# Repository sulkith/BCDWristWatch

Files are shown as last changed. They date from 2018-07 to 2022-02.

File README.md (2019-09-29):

# (BCD)WristWatch
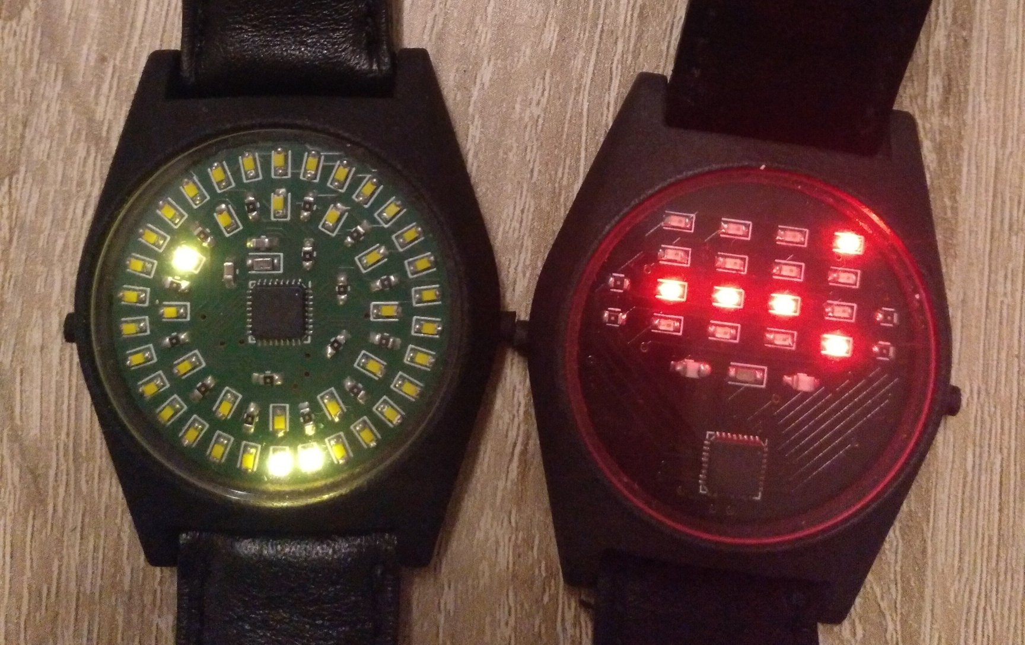
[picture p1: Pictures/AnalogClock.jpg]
picture of Both clocks side by side

Read the complete Story here in the Browser:<br>
https://htmlpreview.github.io/?https://github.com/sulkith/BCDWristWatch/blob/master/Story/Story.html <br>
Or you can download the PDF:<br>
https://github.com/sulkith/BCDWristWatch/blob/master/Story/Story.pdf

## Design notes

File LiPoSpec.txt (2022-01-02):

Typ: Lithium Polymer (LiPo) 3,7V / 1S
Länge der Kabel: ca. 10 cm
Nennspannung: 3,7V
Ladeschlussspannung: 4,2V
Entladeschlussspannung: 3,0V
Max. Ladestrom: (1C)
Max. Entladestrom: 2C für 10s
Max. Dauerentladestrom: (0,5C)

Lebensdauer:
300 Zyklen bei 0,5C Entladestrom
500 Zyklen bei 0,2C Entladestrom
max. erreichbare Zyklenzahl: 500 - 1.000 

https://fpvracing.ch/de/content/21-lipo-batterien

Entladerate (30C, 35C u.s.w.)

Die C Grösse der Batterie gibt an, wie viel Strom auf einmal von der Batterie gezogen werden kann/darf. 1C steht dabei für Ampere durch Amperestunde (Strom durch Ladung). Eine Batterie mit 2200mAh und 30C liefert demnach 30(A/Ah) x 2.2(Ah) = 66A. Der gesamte Multicopter darf in diesem Falle nicht mehr als 66A auf einmal ziehen. Gewisse LiPo-Packungen geben zusätzlich noch eine Burstrate an, welche grösser ist als die Kontinuierliche C-Rate, z.B. Discharge rate = 30C Continuous / 60C Burst. Burst ist die Angabe des erlaubten Spitzenstroms, welcher für ein paar Sekunden gezogen werden darf.

Es ist sehr wichtig dass man keine Batterie mit zu tiefem C-Rating für seinen Copter nimmt. Dadurch schädigt man die LiPo Batterie und wohlmöglich zusätzlich die ESCs.

1C 150mAh
1(A/Ah)*0,150(Ah)=150mA

PROG(Pin 2):Constant Charge Current Setting and Charge Current Monitor Pincharge current is set by connecting a resistor RISET from this pin to GND. When in precharge mode, the ISET pin’s voltage is regulated to 0.2V. When in constant charge current mode, the ISET pin’s voltage is regulated to 2V.In all modes during charging, the voltage on ISET pin can be used to measure the charge current as follows:

I_Bat = V_prog/R_prog * 1200 (Vprog=1V)

0,5A = (1V/2400)*1200

0,15A = (1/x)*1200
0,15A/1200 = 1/x
1200/0,15=x=8000 >= 8k

Rprog=10k
I_Bat = 1/10000*1200 = 120mA

Charger Circuit:
LTC4054
https://www.mouser.de/ProductDetail/Analog-Devices/LTC4054LES5-42TRPBF?qs=hVkxg5c3xu8%252BnYSikPxbpQ%3D%3D

Buck Converter:
TPS62205DBVR
https://www.mouser.de/ProductDetail/Texas-Instruments/TPS62205DBVR?qs=Gse6rAGbi7%252BLOibC81hqAA%3D%3D
TPS62203DBVR
https://www.mouser.de/ProductDetail/Texas-Instruments/TPS62203DBVR?qs=Gse6rAGbi7%252BekjMIU1w5MA%3D%3D
Induction
LQM18DH100M70L
https://www.mouser.de/ProductDetail/81-LQM18DH100M70L

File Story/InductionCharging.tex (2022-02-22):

\section{Making the watch rechargable}
The battery of the STM Watch version will last for about 6 months, so every 5 months i have to open the housing, change the battery and close the housing again. Also from an enviromental point of view it is not good to waste a battery every 6 months. So there has to be a solution to make the watch rechargable.
\subsection{possible solutions}
\subsubsection{Just use a rechargable battery}
The easiest variant to make the watch rechargable would be to directly use a rechargable battery wiht the same PCB. This would require no changes on the PCB level, but the rechargable batteries have a smaller capacitance than the not rechargable lithium batteries which are used till now.
So from the environmental point of view this is even worse, since the housing will wear out and i have to change the housing also very frequently. With this solution it also won't be possible to make the housing 100\% waterproof(glue it shut).
\subsubsection{charging pins on the outside of the watch}
Another possible solution would be to insert some contacts in the housing to be able to contact the battery from the outside. This would either require a battery management controller inside of the watch or in a charging bay. Since the charging bay for the watch would be also a special construction i would have gone for the charging bay with the integrated battery managment. 
This would also make the battery directly connected tothe outside of the watch possibly draining the battery when the watch is wet or sweaty.
For this problem a possible solution would be to add a reed contact to one of the pins of the battery.
to experiment a bit with these variant i created a devboard ( see Schematics/devboards/LiPo\_Circuit). This devboard is using a LTC4054ES5-4.2 as a battery controller.
With the devboard i was able to run the watch for about 2 months without recharging. If i don't have to open the watch to recharge the battery this is sufficient.
\subsubsection{adding a small solar cell}
With a very small solar cell it would also be possible to power the watch and maybe even charge the battery. If the solar cell is not powerfull enough to charge the watch in the daily usage it would also be possible to build a special charging box which charges the watch by shining light directly on the solar cell. 
The problem with this solution was the needed space on the watchface. The goal of the watch is to keep it as small as possible so it is easy to use and smaller than a normal smart watch.
\subsubsection{charging the watch via wireless charging}
This is a very comfortable solution for the user, but the most complex solution to implement in the watch itself. 
Also this solution would make it possible to fill the complete housing with epoxy, so it is 100\% waterproof.
Although this solution is the most complex solution, it is also the most elegant one so it is also the one which gets implemented.
\subsection{possible porblems when using lithium polymer batteries}
\subsubsection{overcurrent protection}
The battery has to be protected aganist overcurrent so it won't start burning suddenly. Luckily most batteries you can buy on ebay or other sources already have an integrated overcurrent protection.
\subsubsection{undervoltege protection}
Lithium batteries will wear out when they are discharged below certain levels, so this has to be avoided. Some Batteries already have an integrated undervoltage protection, but most batterymanagent ICs also include a undervoltage protection.
\subsubsection{voltage levels}
a typical Lithium Polymer battery has a undervoltage protection at $2V$ and a charging Voltage of $4.2V$, so either all parts have to be tolerant to $2V$ to $4.2V$ or we need to use some kind of Voltage regulator or DCDC Converter. For the STM32 tis is fine, but the BMA456 is only specified from $1.6V$ to $4.0V$, so we cannot use the whole range from the lithium polymer battery. For this reason in included the TPS62203DBV which is a step-down converter to $3.3V$, this will also decrease the needed current from the battery when the voltage is higher than needed.
\subsection{chosen solution: wireless charging}
\subsubsection{Implementing a testboard}
Wireless charging can either be implemented via a selfmade schematic or via an IC. While researching i came across the LTC4124 Controller from Amalog devices: \url{https://www.analog.com/en/products/ltc4124.html}. This IC features an wireless power receiver and an integrated batterymanagement, so it will be the only needed chip for the wireless charging part of the schematic.
Sadly the LTC4124 IC is a very small QFN package and only has the pad underneath as ground, so it has to be soldered very good.
The testboard can be found under Schematics/devboards/LiPo\_Wireless.
\paragraph{receiving part}
This testboar features a receiving part using the LTC4124. To get it running the LTC4124 needs to receive power wirelessly to connect the battery to the output pin. So you won't have any luck with the receiver until you get the sender running. 
A LED is showing when the receiver is charging, this can be used as a finst indcator that something is working. But beware the open dain pin of for the charging LED is only drawing $300µA$ so make sure to use a low current LED, otherwise you will be fooled by the LED not working. Trust me this will drive you nuts...
\paragraph{sending part}
The schematic for the sending part was straight from the datasheet of the LTC4124 nevertheless i was not able to get it working, the power dropped once the MOSFET turned on
after adding an additional resistor in line with the induction coil and a big capacitor paralell to the power supply the voltage stayed stable, but it was not supplying enough energy to charge the battery. Anyhow it was enough energy to swith on the output pin of the LTC4124. This was the first sign of life for the whole board. 
However i was not able to improve the sending part any further...
\paragraph{alternative Sender - QI charging pad}
The next option was to use a already available charging pad to send enough energy to charge the battery. I tried this with a QI charging pad, but sadly the QI charging standard includes a handshake which will prevent the sender to send energy when there is no receiver present.
The charging was working if the coil of the sender was placed between the QI charging pad and a QI charging phone.
Sadly the chargin was not possible when the coil was placed on the phone, or the phone was more than $10mm$ away from the charging pad. So it was not possible to charge the assembled watch with this method.
\paragraph{alternative Sender - Evaluation board}
The next solution i tried was to order an evaluation board for the LTC4124 and just use the sender which comes with the evaluation board.
This worked like a charm.
\subsubsection{Binary PCB}
TODO

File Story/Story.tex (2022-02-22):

%\documentclass[12pt,a4paper]{article}
%\usepackage[ngerman]{babel}

\documentclass[12pt,a4paper,final]{article}
\usepackage[T1]{fontenc}
\usepackage[utf8]{inputenc}
\usepackage[ngerman]{babel}
\usepackage{amsmath}
\usepackage{amsfonts}
\usepackage{amssymb}
\usepackage{lmodern}
\usepackage[left=2cm,right=2cm,top=2cm,bottom=2cm]{geometry}
\usepackage{graphicx}
\usepackage{hyperref}
\usepackage{listings}
\usepackage{fancyvrb}
\title{BCDWristWatch}
\date{\vspace{-10ex}}
\begin{document}
\pagenumbering{gobble}
\title{BCDWristWatch}
\author{SulKith}
\maketitle
\vspace{5cm}
\begin{center}
  
\end{center}
\newpage
\section*{Summary}
It all started with the idea of a PCB which could display the time in BCD code and is small enough to wear it on the wrist. Sadly i was not able to find a Housing which could be used for the Clock, so i created one myself in OpenSCAD and 3D-printed it.
After a while i got tired to explain the BCD code to everybody, so there is also a Analogish Version available.

The Software for both Versions is unified and just differentiated by the Linker. So there is no change to the Code needed.

After some problems with sweat entering the Housing and destroying the electronics, i tried several possible solutions (read more in the story).
\\
\\
The alternative try to solve the sweat issue was to remove the buttons completely and replace them with a G-Force sensor. As sensor the Bosch BMA456 is used, since it features various interrupt functionalities to wakeup the microcontroller and only draws a few microamps in standby.

The powerful Sensor also made some other cool features for a wrist watch.
There is a Wrist Tilt detection to activate the Watchface once the user rises the arm and takes a look on the watch. Now the watch can also be turned on while only using one hand e.g. while carrying stuff.

Another cool new feature is a stepcounter, so the watch is also a (not completely sweat resistant ;-) ) fitness tracker.

The next evolution step is switching to a new more powerful controller. For this the STM32L432K Controller was chosen. This controller also features a calender in the built in RTC.
\input{BinaryWatch.tex}
\input{AnalogWatch.tex}
\input{BinaryGWatch.tex}
\input{STM_Version.tex}
\input{STM_Manual.tex}
\input{InductionCharging.tex}

\end{document}

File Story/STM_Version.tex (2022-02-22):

\section{Switching to an ARM Controller}
The obvious next evolution step would be to include the BMA Sensor into the analog Version. But since the ATMega328P has a lot of reserved pins there are not enough usable pins to supply the BMA and the 42 LEDs (only one Pin was missing). So there were a few possible solutions
\subsection{AVR Controller in a bigger Package}
Regarding the Software this would be the easiest Varaint to go with.
But there are a few disadvantages of the AVR Controller.
\begin{itemize}
	\item a larger Package requires more PCB Space
	\item it requires 6 Pins for ISP programming
	\item it has a bigger power consumption than modern Controllers
	\item modern Controllers are faster
	\item it is an old Controller ;-)
	\item there is no technical challenge 
\end{itemize}
So this was not the final solution.
\subsection{Atmel SAM}
I started with the Atmel SAM Controller, because I liked the experience with Atmel Controllers so far. For a comparison of Microcontrollers there is a great article from Jay Carlson \url{https://jaycarlson.net/microcontrollers/}. The advantage of the Atmel SAM Controllers are there are a lot of open source Tools which could also be used out of a makefile, so the projectsrtucture is very easy to create. All the Configuration and the Bootupsequence is generated by the Atmel Start utility. \url{https://start.atmel.com/}. The feature i liked the most is the SERCOM Interface.A SERCOM interface could be used for various serial Interfaces (UART, I2C, SPI...), the biggest advantage is that all thepins could be multiplexed with each other.

Therefore i created a Evaluationboard i could start playing around with:
\url{https://github.com/sulkith/devboards/tree/master/ATSAML22G18A_LowPowerArm}

Once the Board arived i encountered the first problem. The files generated by the Atmel Start utility are licensed under the ASF license. And since i'm no lawyer, i couldn't really decide if it is safe to use these files in an open-source project like this one. So i decided to build a wrapper, which would unpack the Package generated by the Atmel Start utility and include the files in my project Structure (\url{https://github.com/sulkith/devboards/blob/master/ATSAML22G18A_LowPowerArm/Software/AtmelStart/AtmelStartIntegrate/importAtzip.sh}). But as soon as you need to change some code in the Startup or in the drivers the whole process is not working anymore.

But since in the early stages one has to change a lot of settings in the configurator and include it back in my code. So the whole Workflow is some kind of clumpsy. And i got a bit sick of changing a Setting and taking one or two minutes to change a single option. So i was looking for a solution where the whole process is smoother.

\subsection{STM32}
So a few colleques suggested to go for a STM32 Controller because the STMCubeIDE is very smooth and all configurations are done inside the IDE.Afterwards the Code is directly generated. A big plus point was that in the copiright notice it is explicitely stated, that you are allowed to redistribute the software if you mention the original source(this is automatically done in the header of every file). So using it for an open source project doesn't seem to be a problem.

\subsubsection{STM32L053R8}
To start with the ecosystem i went for a Nucleo-L053R8 development board with a lowpower Cortex M0+. It took me about half an hour to get the I2C running. So the IDE is great and easy to use. The Controller used on the Board is featuring a on-chip RTC which is also running in all Low-Power modes including Standby mode. So all the Timekeeping wor the wrist watch could be done completely by the chip. There is also a RTC-Clibration feature, which could be used to syncronize the deviation of the Crystal with a high precision frequency source. 
Sadly the STM32L053R8 Controller is not available in a QFN32 Package.

\subsubsection{STM32L432K} 
While searching for a replacement for the STM32L053R8 i came across the STM32L432K Controller, with a Cortex M4 Core, which is also featuring a Shutdown mode with only about 400 nA with the RTC running. So the Watch will consume very low power. A Wakeup is also possible by the Wakeup pin, which could be connected to the BMA Controller to wake up the Controller on wrist tilt or double-tap. There are enough pins for using the Wakeup Pin, SPI, SWD-Debugging and supplying all 42 LED for the analog version.
So from the Hardware point of view everything is fine.

\paragraph{Binary PCB}
Sinc the ST QFN Package looks like a big black box i also placed the BMA456 sensor, which also looks like a black box right next to it for a more PCB like look.
\begin{center}
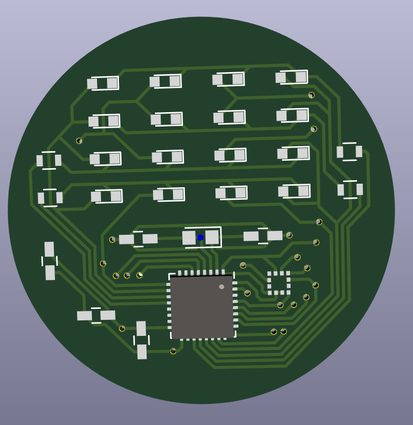
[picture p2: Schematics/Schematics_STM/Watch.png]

\end{center}
\paragraph{The Boot Pin}
When the first PCBs arrived it was very easy to get them working, but when the Debugger was not connected sometimes the controller wasn't booting correctly and was displaying strage things on the LED. When connecting to the controller without a reset one could identify the courrent all stack. And the address was in the section of the ST Bootloader. So the obvious suspect was the Boot Pin, the pin was floating in the initial PCB design and this is a bad Idea. In the first Prototype this was fixed by connecting it directly to the neighbouring ground pin. For the next version there will be a resistor pulling it to ground.

Since the Watch was working now it was time to get the crystal calibration working. But since the controller only has a 32 Pin Package the Calibration Pin is not available in the footprint. 

\paragraph{Calibration}
A Workaround for the missing calibration feature was to use the Timer in frequency counter mode with the LSE clock(External Crystal) connected to the Clock pin. So the Input timervalue will be saved on each Signal edge, after two edges the difference could be calculated. For an input Frequency of 1Hz the difference has to be exactly 32768. To increase the accuracy was the presacaler was set to the maximum value of 8. So the value has to be exactly 8*32768. To further increase the accuracy the whole process will be repeated 20 Times and then the average deviation will be calculated. From this deviation the correction value per 1 ppm could be calculated. But after the calibration procedure the Watch was still not very acurate.

\paragraph{Load Capacitance}
While searching for the source of the Clock Deviattion i came across the Application Note 2867
\url{https://www.st.com/resource/en/application_note/cd00221665-oscillator-design-guide-for-stm8af-al-s-stm32-mcus-and-mpus-stmicroelectronics.pdf} Which describes the Design guidelines for oscillators used in combination with STM32 controllers. The crystal used in the Clock is the Abracon ABS05W-32.768 kHz-D. The AN2867 recommends 4pF Load Capacitors for this setup. Till now i used 10pF Capacitors, this could als explain the heavy correction which was needed for the AtMega328P.

So i did a few single measurements to measure the difference of the Changes done. The measurements were done with the same Controller on the same PCB, once with a Battery Supply (2.8V) and once with Power Supply from the Nucleo Board (3,3V), The second change was the Change of the Capacitors from 10pF to 3,9pF (i couldn't get exactly 4pF on the 0603 Package). The Results could be found in the Table below.
\vspace{1cm}

\begin{tabular}{|l|l|l|l|}
\hline
Supply Voltage {[}V{]} & Load Capacitance {[}pF{]} & Frequency {[}Hz{]} & Deviation {[}ppm{]} \\ \hline
2,8   & 10                        & 32549              & -209                \\ \cline{2-4} 
                       & 3,9                       & 32850              & 92                  \\ \hline
3,3   & 10                        & 32548              & -210                \\ \cline{2-4} 
                       & 3,9                       & 32857              & 99                  \\ \hline
\end{tabular}
\vspace{1cm}

So we can conclude that a larger Capacitance slows the oscillator down. The correction needed for the clock was now smaller, but the deviation was still there.

\paragraph{CubeIDE Initialization}
After another few tests i found out there is a relation between Wakeups and the Deviation of the Clock. So the original Proble was every time the Controller is initialized the code generated by the CubeIDE will initialize the whole Clock System. To initialize the driver strength of the LSE Clock the clock has to be stopped, and syncronized again. This Process will delay the RTC Time by about 0,5 seconds.

Therefore i needed to adapt the initialization for the Controller. The function, which was causing the Problems is the \verb!SystemClock_Config()!, if there is a LSE configured it would be initialized. So the obvoius solution would be to disable the LSE. But if the LSE is disabled the RTC would need a Clock, so the RTC was also disabled. The big Problem is if the RTC is disabled in the configuration the HAL Driver would not be included in the project. So i copied the initialization Function from the code generated without the RTC and renamed it to \verb!SystemClock_Config_without_LSE()! in the Project configuration i disabled the function call to the original \verb!SystemClock_Config()! and called the \verb!SystemClock_Config_without_LSE()! in the usermain instead. Also the RTC initialization had to be rewritten to only initialize the RTC if the LSE is not running. For this task the Function \verb!STM32L4_HAL::HAL_driverInit()! was introduced. This Function checks if a RTC clock source is set. The clock source is set in the \verb!RCC_BDCR! register, which resides in the backupdomain of the STM and therefore is not cleared by a reset. So the initialization will be only done once when the Battery is inserted.

\paragraph{Analog PCB}
Since the STM32L432K has more usable pins than the Atmega328P it was also possible to route a PCB with the BMA Sensor and the Analog Watchface.
The space for the Analog Watchface was already very tight without the BMA Sensor. With the Sensor it got extremely tight, so i had to turn the Controller by 45 Degrees. Sadly I was not able to comply with all the Designrules for the BMA Sensor. Now i have a via under the BMA, i think this is very bad for series production, but for me it is working.

\begin{center}
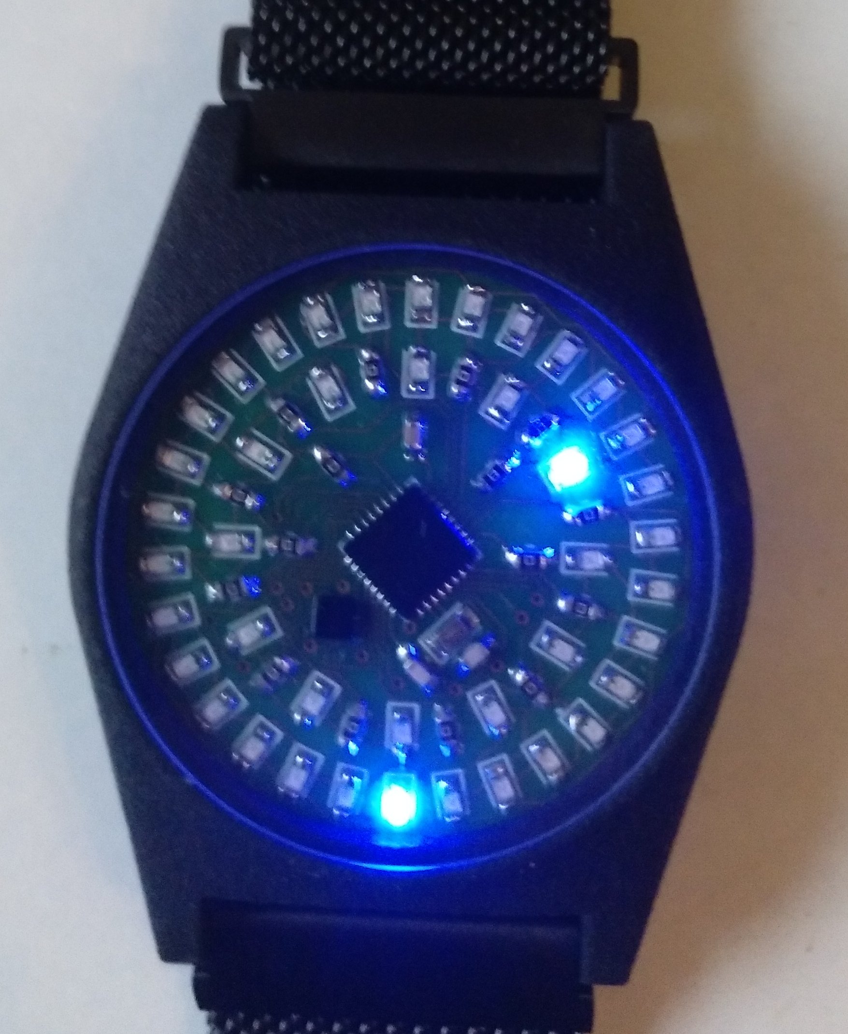
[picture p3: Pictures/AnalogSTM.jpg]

\end{center}

\paragraph{Software for the Analog Version}
I wanted to keep the changes on the Software as simple as possible and don't want to maintain two folders with common files between both variants. I created a combined software, which selects the correct \verb!DisplayManager! depending on  the watch variant saved in the flash, right next to the calibration values for the RTC. So i have only one Software, which fits the analog and the binary version of the watch, but i need to specify, via a define in the calibration software, if it is a analog or a binary watch. For further development i also added some defines in the software, which can disable a specific watch variant. This can be used either to save flash memory or to reduce the possible software bugs in the software.

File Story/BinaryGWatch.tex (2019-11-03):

\section{BinaryGWatch}
\subsection{PCB}
The PCB is based on the Binary Watch. Even the Buttons would still work if soldered on the board. Additionally to the original Schematics there is a Bosch BMA456 connected to the SPI, which is already on the back of the PCB to enable programming via Pogo Pins. Additionally there is also the Chip select pin used and two interrupt pins to enable the wakeup functionality via the BMA sensor. 

The SPI interface was chosen, to keep thepower consumption low, since SPI compared to I2C doesn't need PullUp Resistors.

The BMA Sensor is mounted on the back of the PCB to keep the symetric watch face.

The concept is to use the BMA Sensor also as interface. To enable the Display and also to set the time. So no buttons will be needed this should also enable a housing without holes to keep sweat from crawling into and solve the corroded PCB problems I had with the first BinaryWatch
\subsection{Software}
For interfacing with the BMA i use my own \href{https://github.com/sulkith/Bosch_BMA456}{Bosch\_BMA456} with an additional SPI-adapter.

The Software still has the ability to work with Buttons, but since the BMA is working really well there is no point in using th buttons. and risking that sweat will enter the housing.
\subsection{Housing}
Adapting the housing was very easy, just remove the holes for the buttons.
A little smoothing was done afterwards, because there were some thickened walls around the holes, where the Buttons were mounted.
\subsection{Manual}
\subsubsection{How to read the Watch}
The time is displayed in BCD Code. For further reference please see the Picture below:
\begin{center}
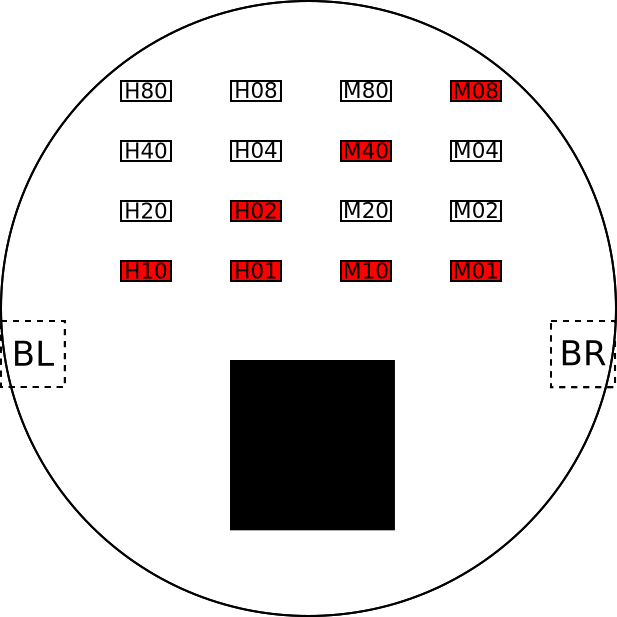
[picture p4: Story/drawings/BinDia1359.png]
  
\label{fig:BinWatchFace}
\end{center}
To read the Watch it is necessary to activate the Display this can be either done via double tapping the Housing or raising the arm to take a look on the watch(tilt it by a minimum of 12 degrees with the Watchface facing up and holding it steady for about one second)

The LEDs are read columnwise. So the right two columns are showing the Minutes. If an LED is litone have to add its Value to the Minutes if not then nothing is added. So for the full hour no led in the right two columns will be lit.

In the Example above the following LEDs are lit: M40, M10, M08 and M01.
The sum of all the values is the current minute value $40+10+8+1=59$

The Hours are displayed exactly like the Minutes. For the hours the 24 Hour Format is used. In the Example above the following LEDs are lit: H10, H01, H02. The current Hour Value is also determined by summing everythin up: $10+1+2=13$.

So the current Time in the example is 13:59. If it is 0:00 the watch will display 24:00 to make sure 0:00 is not confused with a broken watch.
\subsubsection{read the Stepcounter}
To switch between time display and stepcounter display one needs to double tap the watch. In the stepcounter mode the value is displayed differently. the first column from the left is used to signalize that the stepcounter is shown, it will always display 3(H20 \& H10) in this mode, because this would be an unplausible time. the two middle columns are used to display the two most significant numbers of the stepcounter. The most right column is used to display a exponent on the base of 10.
\paragraph{Example}
\vspace{5mm}

\begin{tabular}{|c|c|c|c|}
\hline 
0 & 0 & 0 & 0 \\ 
\hline 
0 & 1 & 1 & 0 \\ 
\hline 
1 & 0 & 0 & 1 \\ 
\hline 
1 & 1 & 0 & 0 \\ 
\hline 
\end{tabular}\\
\vspace{5mm}\\
so the following LEDs are lit:
\begin{itemize}
	\item H10, H20 $\Rightarrow$ 3 signalizes stepcounter mode
	\item H01, H04 $\Rightarrow$ 5
	\item M40 $\Rightarrow$ 4
	\item M02 $\Rightarrow$ 2
\end{itemize}
$54 \cdot 10 ^{2} = 5400$
\subsubsection{set the time}
To set the time first of all the display has to be activated, afterwards the watchface needs to be turned down and double tapping the Housing.
If the First step was succesful the two LEDs H80 and M80 will light up together. To enter the set hour mode the watchface needs to be turned up again and the watch needs to be double tapped again.

Now the LED M80 will be turned off.

To change the Value the watch needs to be tilted up to increase the value or tilted down to decrease the value, to switch to set minute mode the watch needs to be double tapped again. Changing the minutes works exactly like changing hours. To finish the setup process double tap the cloak again. Now the second counter will also start with zero, so it is possible to set the time precisely.

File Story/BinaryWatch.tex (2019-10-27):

\newpage
\section{Binary Watch}
\subsection{PCB}
\subsubsection{First PCB Version}
The First PCB Version was a desaster. The PCBs arrived very fast, but the QFN Package had the wrong size.
ATMEL only produces QFN32 in 7x7mm. Therefore the design of the PCB hat to be changed to the smaller package,
but that gave me the Chance to shrink the Design to a smaller form factor.
The part which keeps the PCB from getting smaller is the Coin Cell Battery (CR2032).
On the PCBs there was the order number printed on the Front side, which would be visble in the final assembly.
\subsubsection{Second PCB Version}

The second PCB Version was designed from scratch. But the Front was the side with the Battery, so hopefully the Order Number would not be printed on the visible side of the PCB. This worked out very well for the second Version of the PCBs.
\subsubsection{PCB1}

since the PCBs finally arrived. it was possible to assemble all the parts.
The first PCB was assembled with some Cables soldered to the Testpins on the Backside of the Board.
And the Battery case was also not assembled.
Here is a Picture of the uncleaned but already soldered PCB
\begin{center}
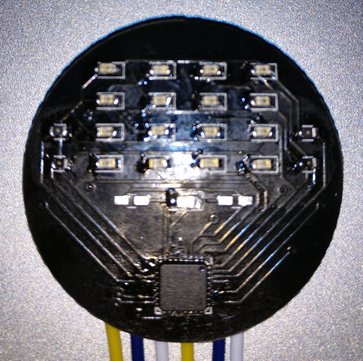
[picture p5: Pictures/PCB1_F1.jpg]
  
\end{center}

\subsubsection{PCB2}
The PCB2 was assembled and cleaned as a First Prototype with the Housing.\
Here aretwo Pictures of the PCB one without the LEDs turned on and one with the LEDs turned on.\
Brightness was set in the Program to 100/255 (see software void showLEDs, constant perc=100) 
\begin{center}
 

\end{center}

\subsubsection{PCB3}
The third PCB was ordered at \href{https://aisler.net}{aisler.net}. It only took around one and a half week to arrive(to Germany).\
The PCB was not completely milled out. It was in a carrier PCB with rectangular shape, but it was easy to remove.\
I had to sand the edges a bit, since it was a bit rough on the parts where i removed the connections to the carrier, since i had to sand the PCB anyway to fit in the Housing that was no big problem.\
The overall Quality of the PCBs is very good, but you can not choose the thicknes or color of the PCB.\
\begin{center}
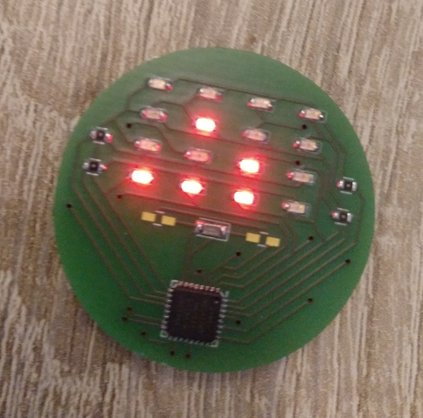
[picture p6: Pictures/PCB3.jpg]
  
\end{center}

\newpage

\subsection{Housing}
The Housing was designed in OpenSCAD.\
a very helpfull reference for the OpenSCAD syntax was\
\url{https://en.wikibooks.org/wiki/OpenSCAD_User_Manual/Transformations}

\subsubsection{Housing 1}
The Housing was printed by the TOOM Printing Service as SLS in PLA.\
Sadly all the surfaces are not really smooth, therefore the Buttons are working very bad.\
I tried to glue in the glass with superglue, but the glue dried out white, this looks really bad :-(\

\subsubsection{Plans for Housing 2}
The next housing should be produced via SLA with transparent Resin, so no glass for Protection is needed, 
since the resin could be used.
\paragraph{Problems while printing with SLA}
It turns out, that there is no completely transparent Resin available. All of them get a yellow color sooner or later.
So it is not really beautiful as a glass.

\subsubsection{Housing 2}
A friend told me that most of the time the resin will not reflect light equally in every spot, therefore i decided to order a PCB without glass and do the mounting of the glass with very tight tolerances and a rim on the top edge.\
this worked out extremely well.\
Another goal was to make the second Housing slim, because the first one was very bulky. With a bit of optimization is was possible to integrate the bottom plate completely in the housing. The overall thicknes was reduced from about 15mm to 9.4mm with the 1mm PCB or 10mm with the new 1.6mm PCB.\
For the PCB to tightly fit in either the Housing has to get some aditional holes or at least the Battery clip has to be modified.\
\begin{center}
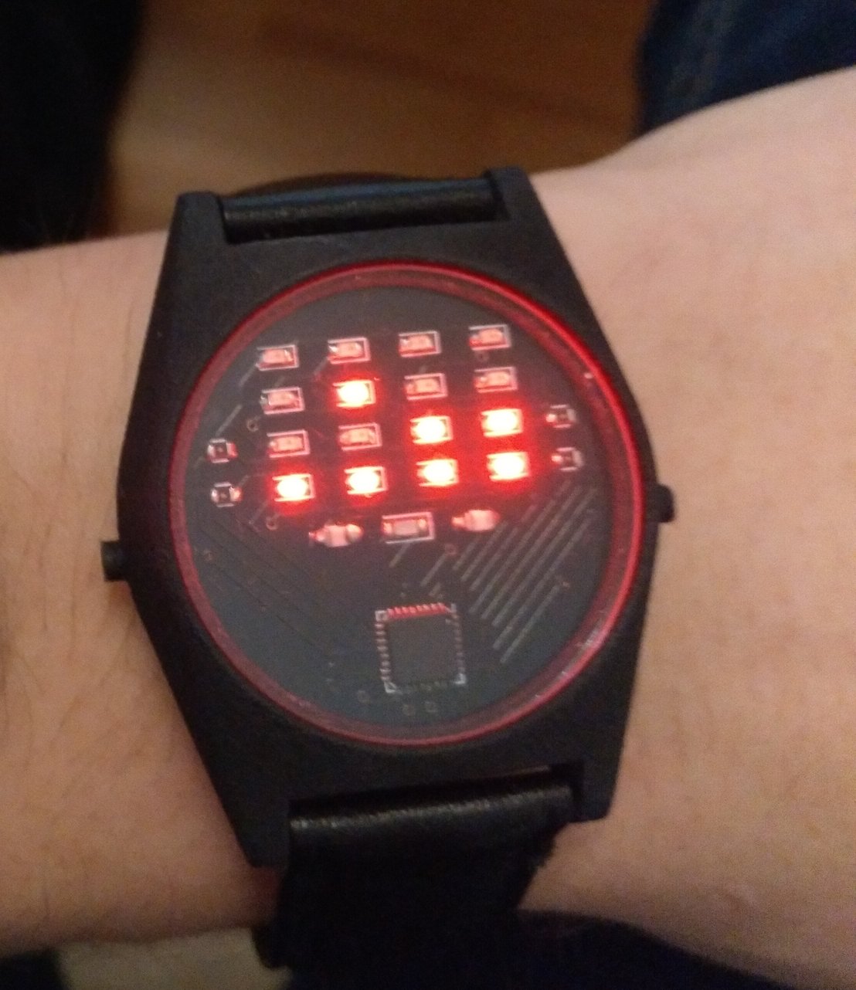
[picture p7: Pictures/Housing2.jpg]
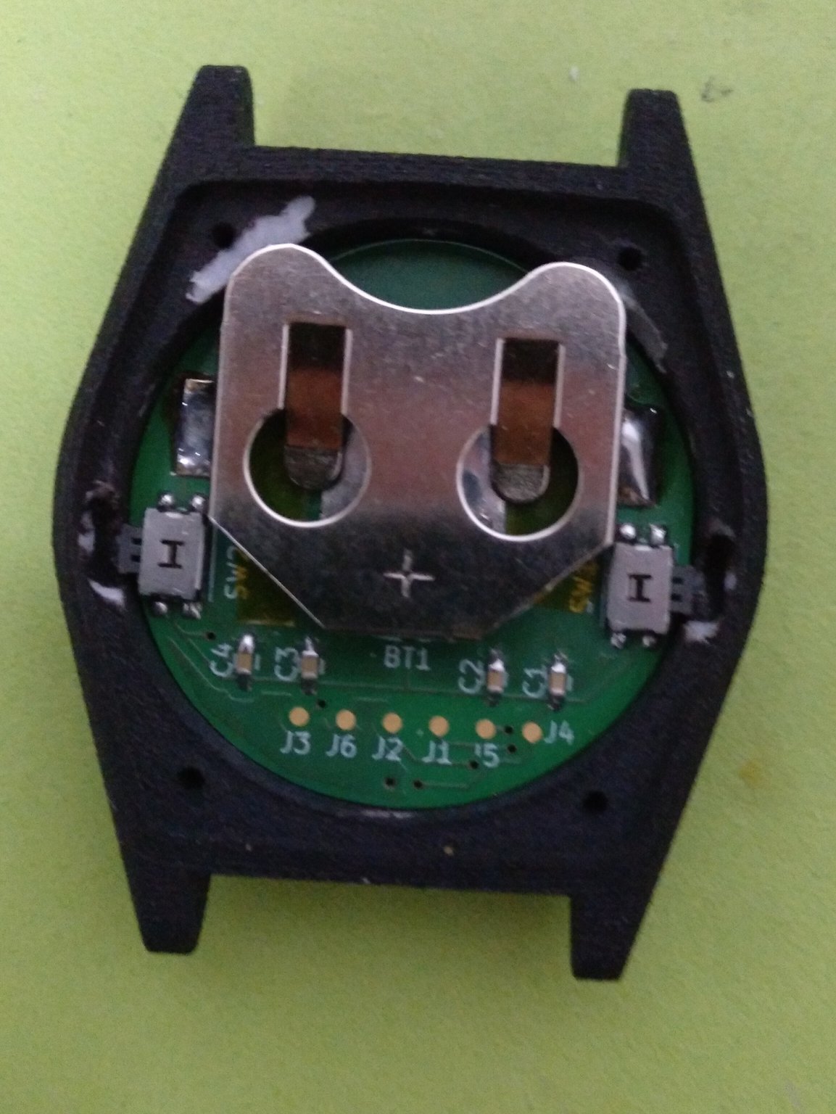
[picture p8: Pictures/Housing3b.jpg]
 
\end{center}

\subsection{Problems}
\subsubsection{Sweat is entering the Housing}
The first watch broke down after nearly 1 year. After opening the Housing the Problem was very obvious. Sweat was entering the Housing and corroded the PCB and the mounted parts.
\begin{center}
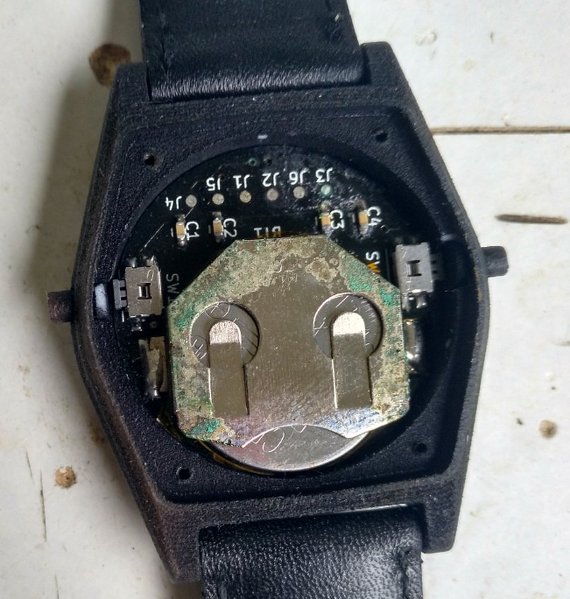
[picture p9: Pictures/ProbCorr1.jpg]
  
\end{center}
\paragraph{Cleaning the PCB and adding something to absorb the moisture}
As a solution i tried to clean the PCB with Isopropanol and glued some rice to the PCB to absorb the moisture, that helped only for about a week and the Watch stopped working again. So that is not the best solution, but is is an extraordinary try ;-)
\begin{center}
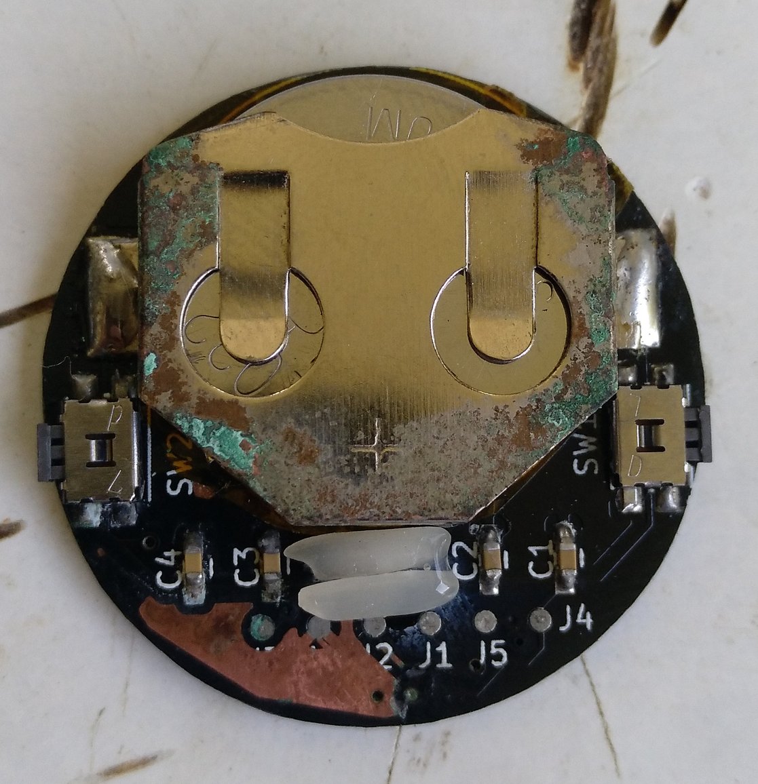
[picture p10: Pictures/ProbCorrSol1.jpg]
  
\end{center}
\paragraph{adding isolation Tape between the lid and the housing}
The second solution was to add Tape, which is originally designed to be used to seal threads, between the housing and the lid.\
That worked out a little bit better, but the Watch also stopped working after a few weeks. 
\paragraph{Analyzing the Watch again}
After analyzing it again the PCB seemd to be ok. The PCB was only a little damaged from the first sweat attack.
The Problem was that the time stopped to run, but another point was that the LEDs wont go off anymore. 
But it was possible to set the time. 
So the conclusion is that the clock which is run by the crystal stopped running.
\paragraph{Adding clear Nailpolish to guard the Crystal}
The next attempted solution was to add clear Nailpolish to the PCB, so the crystal is completely covered. This is an attempt to stop moisture from crawling below the crystal and stopping the clock.

Adding Nailpolish was also not the real solution. The Clock also stopped to work after a few weeks.

\paragraph{commercial products to insulate PCBs}
The next attempt will be to use a commercial Product to insulate the PCB.
For this i will try \href{https://www.reichelt.de/korrosionsschutzlack-plastik-70-super-400-ml-isolierlack-kontakt-32046-p125737.html}{Plastik 70 Super} from Kontakchemie.

\subsection{Manual}
\subsubsection{How to read the Watch}
The time is displayed in BCD Code. For further reference please see the Picture below:
\begin{center}
  
\label{fig:BinWatchFace}
\end{center}
There are Two Buttons on the Watch:
\begin{itemize}
	\item BL: left Button
	\item BR: right Button
\end{itemize}
To read the Watch it is necessary to activate the Display via one of the Buttons

The LEDs are read columnwise. So the right two columns are showing the Minutes. If an LED is litone have to add its Value to the Minutes if not then nothing is added. So for the full hour no led in the right two columns will be lit.

In the Example above the following LEDs are lit: M40, M10, M08 and M01.
The sum of all the values is the current minute value $40+10+8+1=59$

The Hours are displayed exactly like the Minutes. For the hours the 24 Hour Format is used. In the Example above the following LEDs are lit: H10, H01, H02. The current Hour Value is also determined by summing everythin up: $10+1+2=13$.

So the current Time in the example is 13:59. If it is 0:00 the watch will display 24:00 to make sure 0:00 is not confused with a broken watch.
\subsubsection{set the time}
To set the time first of all the display has to be activated, afterwards both buttons have to be released (to make sure that the setup mode is not accessed accidently). Now both buttons have to be pressed. Now the LED H80 lights up, to signalize that now it is in set hour mode. Now Both buttons can be released again.

To switch to the set minute mode the right button has to be pressed. In set minute mode the right button switches back to the normal mode.

With the right button the value which is set currently can be incremented.
The hour will not be incremented wen incrementing the minutes from 59 to 0.

Both setup modes will timeout if no button is pressed for 30 seconds.
While the watch is in setup mode the clock will be stopped, after returning to normal mode the seconds will start from 0 so it is easy to set the time precisely.

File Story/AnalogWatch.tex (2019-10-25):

\newpage
\section{Analog Watch}
\subsection{PCB}
After the PCBs for the BCD Version were working, i also created an analog Version, so i dont have to explain the Clock everytime ;-)

The Analog Watch features the same Schematics for the basic clock functionality, but the display is done via Charlieplexing the LEDs. There are 4 Clustes with 4 Pins which drive all the 42 LEDs. 12 LEDs on the inner ring are displaying the hours. On the outer ring 30 LEDs display the Minutes. Since it was not possible to fit 60 LEDs on the outer ring, uneven numbers are shown while lighting up the two neighbouring LEDs.
\begin{center}
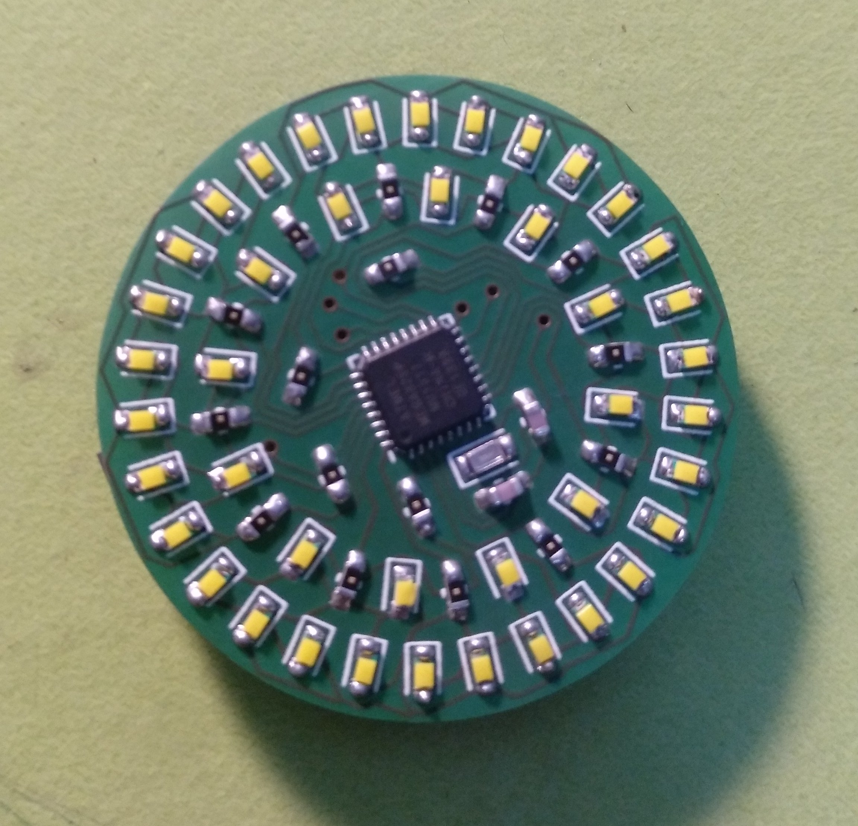
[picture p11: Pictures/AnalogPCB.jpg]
  
\end{center}
\newpage

\subsection{Housing}
The PCB for the analog Version is designed with the same mechanical Interface as the Binary Version therefore the Housing from the Binary Version can be used.

\subsection{first Watch which i gave away}
The first Watch i gave away was one of the analog PCB ones i built for my dads birthday.
for this Watch i replaced all the resistors for the LEDs with Zero $\Omega$ resistors, so the LEDs got more bright and are clearly readable also in the sunlight.
\begin{center}
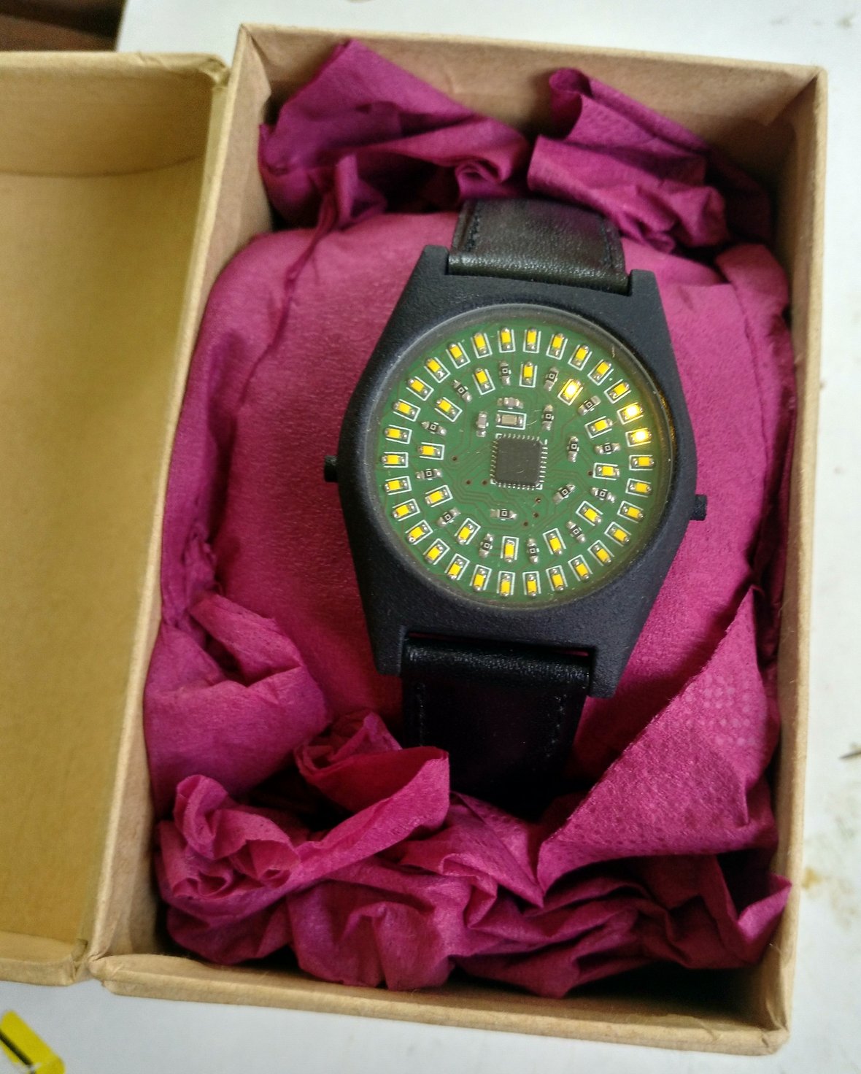
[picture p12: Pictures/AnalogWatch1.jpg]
  
\end{center}

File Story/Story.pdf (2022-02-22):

# BCDWristWatch

### SulKith


## Summary

It all started with the idea of a PCB which could display the time in BCD code and is small enough to wear it on the wrist. Sadly i was not able to find a Housing which could be used for the Clock, so i created one myself in OpenSCAD and 3D-printed it. After a while i got tired to explain the BCD code to everybody, so there is also a Analogish Version available.
The Software for both Versions is unified and just differentiated by the Linker. So there is no change to the Code needed.
After some problems with sweat entering the Housing and destroying the electronics, i tried several possible solutions (read more in the story).

The alternative try to solve the sweat issue was to remove the buttons completely and replace them with a G-Force sensor. As sensor the Bosch BMA456 is used, since it features various interrupt functionalities to wakeup the microcontroller and only draws a few microamps in standby.
The powerful Sensor also made some other cool features for a wrist watch. There is a Wrist Tilt detection to activate the Watchface once the user rises the arm and takes a look on the watch. Now the watch can also be turned on while only using one hand e.g. while carrying stuff. Another cool new feature is a stepcounter, so the watch is also a (not completely sweat resistant ;-) ) fitness tracker.
The next evolution step is switching to a new more powerful controller. For this the STM32L432K Controller was chosen. This controller also features a calender in the built in RTC.

## 1 Binary Watch

### 1.1 PCB

### 1.1.1 First PCB Version

The First PCB Version was a desaster. The PCBs arrived very fast, but the QFN Package had the wrong size. ATMEL only produces QFN32 in 7x7mm. Therefore the design of the PCB hat to be changed to the smaller package, but that gave me the Chance to shrink the Design to a smaller form factor. The part which keeps the PCB from getting smaller is the Coin Cell Battery (CR2032). On the PCBs there was the order number printed on the Front side, which would be visble in the final assembly.

### 1.1.2 Second PCB Version

The second PCB Version was designed from scratch. But the Front was the side with the Battery, so hopefully the Order Number would not be printed on the visible side of the PCB. This worked out very well for the second Version of the PCBs.

### 1.1.3 PCB1

since the PCBs finally arrived. it was possible to assemble all the parts. The first PCB was assembled with some Cables soldered to the Testpins on the Backside of the Board. And the Battery case was also not assembled. Here is a Picture of the uncleaned but already soldered PCB

### 1.1.4 PCB2

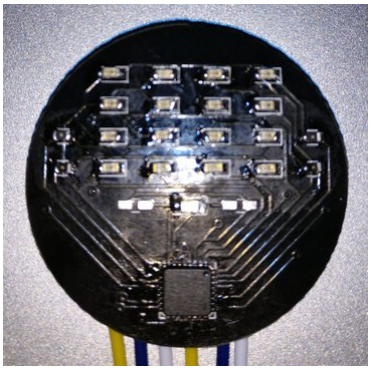
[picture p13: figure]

The PCB2 was assembled and cleaned as a First Prototype with the Housing. Here aretwo Pictures of the PCB one without the LEDs turned on and one with the LEDs turned on. Brightness was set in the Program to 100/255 (see software void showLEDs, constant perc=100)

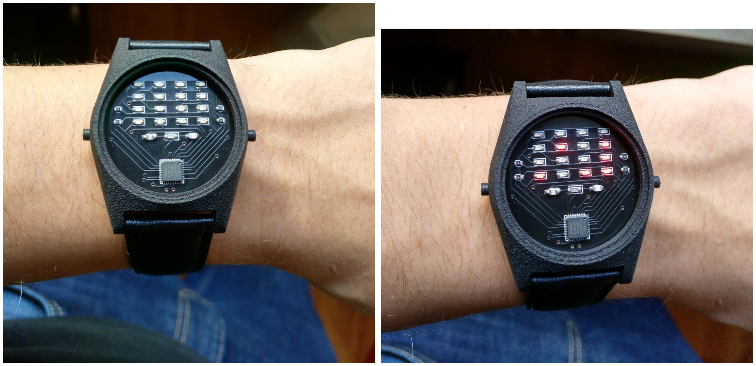
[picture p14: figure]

### 1.1.5 PCB3

The third PCB was ordered at aisler.net. It only took around one and a half week to arrive(to Germany). The PCB was not completely milled out. It was in a carrier PCB with rectangular shape, but it was easy to remove. I had to sand the edges a bit, since it was a bit rough on the parts where i removed the connections to the carrier, since i had to sand the PCB anyway to fit in the Housing that was no big problem. The overall Quality of the PCBs is very good, but you can not choose the thicknes or color of the PCB.


### 1.2 Housing

The Housing was designed in OpenSCAD. a very helpfull reference for the OpenSCAD syntax was https://en.wikibooks.org/wiki/OpenSCAD_User_Manual/Transformations

### 1.2.1 Housing 1

The Housing was printed by the TOOM Printing Service as SLS in PLA. Sadly all the surfaces are not really smooth, therefore the Buttons are working very bad. I tried to glue in the glass with superglue, but the glue dried out white, this looks really bad :-(

### 1.2.2 Plans for Housing 2

The next housing should be produced via SLA with transparent Resin, so no glass for Protection is needed, since the resin could be used.

Problems while printing with SLA It turns out, that there is no completely transparent Resin available. All of them get a yellow color sooner or later. So it is not really beautiful as a glass.

### 1.2.3 Housing 2

A friend told me that most of the time the resin will not reflect light equally in every spot, therefore i decided to order a PCB without glass and do the mounting of the glass with very tight tolerances and a rim on the top edge. this worked out extremely well. Another goal was to make the second Housing slim, because the first one was very bulky. With a bit of optimization is was possible to integrate the bottom plate completely in the housing. The overall thicknes was reduced from about 15mm to 9.4mm with the 1mm PCB or 10mm with the new 1.6mm PCB. For the PCB to tightly fit in either the Housing has to get some aditional holes or at least the Battery clip has to be modified.

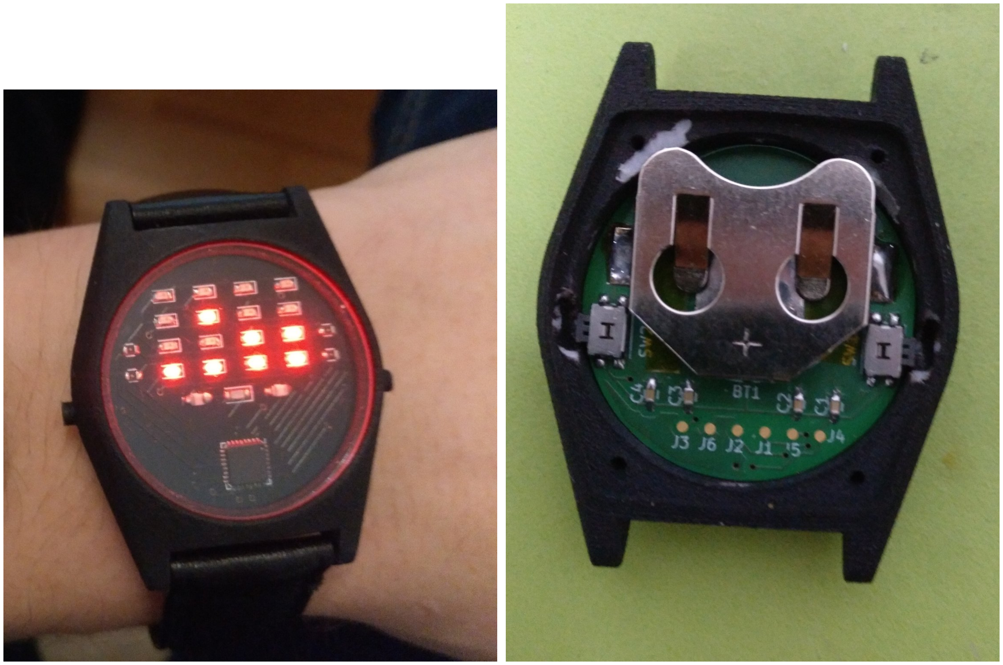
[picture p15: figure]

### 1.3 Problems

### 1.3.1 Sweat is entering the Housing

The first watch broke down after nearly 1 year. After opening the Housing the Problem was very obvious. Sweat was entering the Housing and corroded the PCB and the mounted parts.


Cleaning the PCB and adding something to absorb the moisture As a solution i tried to clean the PCB with Isopropanol and glued some rice to the PCB to absorb the moisture, that helped only for about a week and the Watch stopped working again. So that is not the best solution, but is is an extraordinary try ;-)


adding isolation Tape between the lid and the housing The second solution was to add Tape, which is originally designed to be used to seal threads, between the housing and the lid. That worked out a little bit better, but the Watch also stopped working after a few weeks.

Analyzing the Watch again After analyzing it again the PCB seemd to be ok. The PCB was only a little damaged from the first sweat attack. The Problem was that the time stopped to run, but another point was that the LEDs wont go off anymore. But it was possible to set the time. So the conclusion is that the clock which is run by the crystal stopped running.

Adding clear Nailpolish to guard the Crystal The next attempted solution was to add clear Nailpolish to the PCB, so the crystal is completely covered. This is an attempt to stop moisture from crawling below the crystal and stopping the clock.
Adding Nailpolish was also not the real solution. The Clock also stopped to work after a few weeks.

commercial products to insulate PCBs The next attempt will be to use a commercial Product to insulate the PCB. For this i will try Plastik 70 Super (https://www.reichelt.de/korrosionsschutzlack-plastik-70-super-400-ml-isolierlack-kontakt-32046-p125737.html) from Kontakchemie.

### 1.4 Manual

### 1.4.1 How to read the Watch

The time is displayed in BCD Code. For further reference please see the Picture below:


There are Two Buttons on the Watch:

- BL: left Button
- BR: right Button

To read the Watch it is necessary to activate the Display via one of the Buttons
The LEDs are read columnwise. So the right two columns are showing the Minutes. If an LED is litone have to add its Value to the Minutes if not then nothing is added. So for the full hour no led in the right two columns will be lit.
In the Example above the following LEDs are lit: M40, M10, M08 and M01. The sum of all the values is the current minute value 40 + 10 + 8 + 1 = 59
The Hours are displayed exactly like the Minutes. For the hours the 24 Hour Format is used. In the Example above the following LEDs are lit: H10, H01, H02. The current Hour Value is also determined by summing everythin up: 10 + 1 + 2 = 13.

So the current Time in the example is 13:59. If it is 0:00 the watch will display 24:00 to make sure 0:00 is not confused with a broken watch.

### 1.4.2 set the time

To set the time first of all the display has to be activated, afterwards both buttons have to be released (to make sure that the setup mode is not accessed accidently). Now both buttons have to be pressed. Now the LED H80 lights up, to signalize that now it is in set hour mode. Now Both buttons can be released again.
To switch to the set minute mode the right button has to be pressed. In set minute mode the right button switches back to the normal mode.
With the right button the value which is set currently can be incremented. The hour will not be incremented wen incrementing the minutes from 59 to 0.
Both setup modes will timeout if no button is pressed for 30 seconds. While the watch is in setup mode the clock will be stopped, after returning to normal mode the seconds will start from 0 so it is easy to set the time precisely.

## 2 Analog Watch

### 2.1 PCB

After the PCBs for the BCD Version were working, i also created an analog Version, so i dont have to explain the Clock everytime ;-)
The Analog Watch features the same Schematics for the basic clock functionality, but the display is done via Charlieplexing the LEDs. There are 4 Clustes with 4 Pins which drive all the 42 LEDs. 12 LEDs on the inner ring are displaying the hours. On the outer ring 30 LEDs display the Minutes. Since it was not possible to fit 60 LEDs on the outer ring, uneven numbers are shown while lighting up the two neighbouring LEDs.


### 2.2 Housing

The PCB for the analog Version is designed with the same mechanical Interface as the Binary Version therefore the Housing from the Binary Version can be used.

### 2.3 first Watch which i gave away

The first Watch i gave away was one of the analog PCB ones i built for my dads birthday. for this Watch i replaced all the resistors for the LEDs with Zero Ω resistors, so the LEDs got more bright and are clearly readable also in the sunlight.


## 3 BinaryGWatch

### 3.1 PCB

The PCB is based on the Binary Watch. Even the Buttons would still work if soldered on the board. Additionally to the original Schematics there is a Bosch BMA456 connected to the SPI, which is already on the back of the PCB to enable programming via Pogo Pins. Additionally there is also the Chip select pin used and two interrupt pins to enable the wakeup functionality via the BMA sensor.

The SPI interface was chosen, to keep thepower consumption low, since SPI compared to I2C doesn’t need PullUp Resistors.
The BMA Sensor is mounted on the back of the PCB to keep the symetric watch face. The concept is to use the BMA Sensor also as interface. To enable the Display and also to set the time. So no buttons will be needed this should also enable a housing without holes to keep sweat from crawling into and solve the corroded PCB problems I had with the first BinaryWatch

### 3.2 Software

For interfacing with the BMA i use my own Bosch_BMA456 (https://github.com/sulkith/Bosch_BMA456) with an additional SPI-adapter. The Software still has the ability to work with Buttons, but since the BMA is working really well there is no point in using th buttons. and risking that sweat will enter the housing.

### 3.3 Housing

Adapting the housing was very easy, just remove the holes for the buttons. A little smoothing was done afterwards, because there were some thickened walls around the holes, where the Buttons were mounted.

### 3.4 Manual

### 3.4.1 How to read the Watch

The time is displayed in BCD Code. For further reference please see the Picture below:

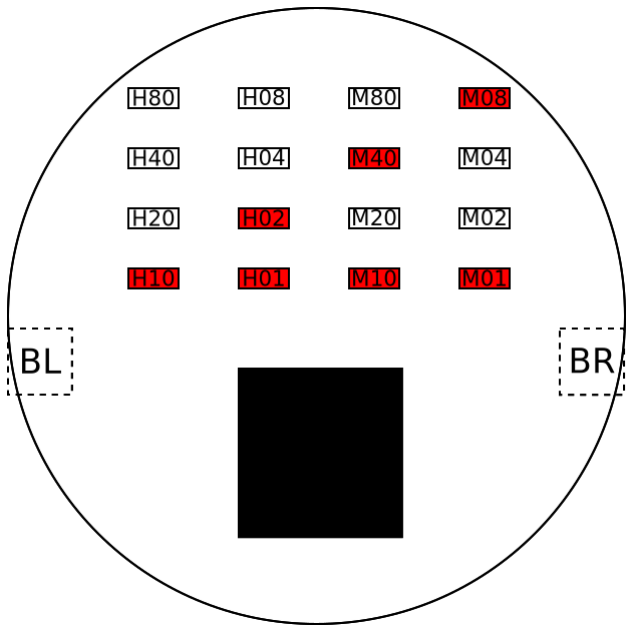
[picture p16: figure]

To read the Watch it is necessary to activate the Display this can be either done via double tapping the Housing or raising the arm to take a look on the watch(tilt it by a minimum of 12 degrees with the Watchface facing up and holding it steady for about one second)
The LEDs are read columnwise. So the right two columns are showing the Minutes. If an LED is litone have to add its Value to the Minutes if not then nothing is added. So for the full hour no led in the right two columns will be lit.
In the Example above the following LEDs are lit: M40, M10, M08 and M01. The sum of all the values is the current minute value 40 + 10 + 8 + 1 = 59

The Hours are displayed exactly like the Minutes. For the hours the 24 Hour Format is used. In the Example above the following LEDs are lit: H10, H01, H02. The current Hour Value is also determined by summing everythin up: 10 + 1 + 2 = 13.
So the current Time in the example is 13:59. If it is 0:00 the watch will display 24:00 to make sure 0:00 is not confused with a broken watch.

### 3.4.2 read the Stepcounter

To switch between time display and stepcounter display one needs to double tap the watch. In the stepcounter mode the value is displayed differently. the first column from the left is used to signalize that the stepcounter is shown, it will always display 3(H20 & H10) in this mode, because this would be an unplausible time. the two middle columns are used to display the two most significant numbers of the stepcounter. The most right column is used to display a exponent on the base of 10.

Example

0 | 0 | 0 | 0
0 | 1 | 1 | 0
1 | 0 | 0 | 1
1 | 1 | 0 | 0

so the following LEDs are lit:

- H10, H20 ⇒ 3 signalizes stepcounter mode
- H01, H04 ⇒ 5
- M40 ⇒ 4
- M02 ⇒ 2

54 · 10² = 5400

### 3.4.3 set the time

To set the time first of all the display has to be activated, afterwards the watchface needs to be turned down and double tapping the Housing. If the First step was succesful the two LEDs H80 and M80 will light up together. To enter the set hour mode the watchface needs to be turned up again and the watch needs to be double tapped again.
Now the LED M80 will be turned off.
To change the Value the watch needs to be tilted up to increase the value or tilted down to decrease the value, to switch to set minute mode the watch needs to be double tapped again. Changing the minutes works exactly like changing hours. To finish the setup process double tap the cloak again. Now the second counter will also start with zero, so it is possible to set the time precisely.

## 4 Switching to an ARM Controller

The obvious next evolution step would be to include the BMA Sensor into the analog Version. But since the ATMega328P has a lot of reserved pins there are not enough usable pins to supply the BMA and the 42 LEDs (only one Pin was missing). So there were a few possible solutions

### 4.1 AVR Controller in a bigger Package

Regarding the Software this would be the easiest Varaint to go with. But there are a few disadvantages of the AVR Controller.

- a larger Package requires more PCB Space
- it requires 6 Pins for ISP programming
- it has a bigger power consumption than modern Controllers
- modern Controllers are faster
- it is an old Controller ;-)
- there is no technical challenge

So this was not the final solution.

### 4.2 Atmel SAM

I started with the Atmel SAM Controller, because I liked the experience with Atmel Controllers so far. For a comparison of Microcontrollers there is a great article from Jay Carlson https://jaycarlson.net/microcontrollers/. The advantage of the Atmel SAM Controllers are there are a lot of open source Tools which could also be used out of a makefile, so the projectsrtucture is very easy to create. All the Configuration and the Bootupsequence is generated by the Atmel Start utility. https://start.atmel.com/. The feature i liked the most is the SERCOM Interface.A SERCOM interface could be used for various serial Interfaces (UART, I2C, SPI...), the biggest advantage is that all thepins could be multiplexed with each other.
Therefore i created a Evaluationboard i could start playing around with: https://github.com/sulkith/devboards/tree/master/ATSAML22G18A_LowPowerArm (https://github.com/sulkith/devboards/tree/master/ATSAML22G18A_LowPowerArm)
Once the Board arived i encountered the first problem. The files generated by the Atmel Start utility are licensed under the ASF license. And since i’m no lawyer, i couldn’t really decide if it is safe to use these files in an open-source project like this one. So i decided to build a wrapper, which would unpack the Package generated by the Atmel Start utility and include the files in my project Structure (https://github.com/sulkith/devboards/blob/master/ATSAML22G18A_LowPowerArm/Software/AtmelStart/AtmelStartIntegrate/importAtzip.sh). (https://github.com/sulkith/devboards/blob/master/ATSAML22G18A_LowPowerArm/Software/AtmelStart/AtmelStartIntegrate/importAtzip.sh) But as soon as you need to change some code in the Startup or in the drivers the whole process is not working anymore.
But since in the early stages one has to change a lot of settings in the configurator and include it back in my code. So the whole Workflow is some kind of clumpsy. And i got a bit sick of changing a Setting and taking one or two minutes to change a single option. So i was looking for a solution where the whole process is smoother.

### 4.3 STM32

So a few colleques suggested to go for a STM32 Controller because the STMCubeIDE is very smooth and all configurations are done inside the IDE.Afterwards the Code is directly generated. A big plus point was that in the copiright notice it is explicitely stated, that you are allowed to redistribute the software if you mention the original source(this is automatically done in the header of every file). So using it for an open source project doesn’t seem to be a problem.

### 4.3.1 STM32L053R8

To start with the ecosystem i went for a Nucleo-L053R8 development board with a lowpower Cortex M0+. It took me about half an hour to get the I2C running. So the IDE is great and easy to use. The Controller used on the Board is featuring a on-chip RTC which is also running in all Low-Power modes including Standby mode. So all the Timekeeping wor the wrist watch could be done completely by the chip. There is also a RTC-Clibration feature, which could be used to syncronize the deviation of the Crystal with a high precision frequency source. Sadly the STM32L053R8 Controller is not available in a QFN32 Package.

### 4.3.2 STM32L432K

While searching for a replacement for the STM32L053R8 i came across the STM32L432K Controller, with a Cortex M4 Core, which is also featuring a Shutdown mode with only about 400 nA with the RTC running. So the Watch will consume very low power. A Wakeup is also possible by the Wakeup pin, which could be connected to the BMA Controller to wake up the Controller on wrist tilt or double-tap. There are enough pins for using the Wakeup Pin, SPI, SWD-Debugging and supplying all 42 LED for the analog version. So from the Hardware point of view everything is fine.

Binary PCB Sinc the ST QFN Package looks like a big black box i also placed the BMA456 sensor, which also looks like a black box right next to it for a more PCB like look.


The Boot Pin When the first PCBs arrived it was very easy to get them working, but when the Debugger was not connected sometimes the controller wasn’t booting correctly and was displaying strage things on the LED. When connecting to the controller without a reset one could identify the courrent all stack. And the address was in the section of the ST Bootloader. So the obvious suspect was the Boot Pin, the pin was floating in the initial PCB design and this is a bad Idea. In the first Prototype this was fixed by connecting it directly to the neighbouring ground pin. For the next version there will be a resistor pulling it to ground.
Since the Watch was working now it was time to get the crystal calibration working. But since the controller only has a 32 Pin Package the Calibration Pin is not available in the footprint.

Calibration A Workaround for the missing calibration feature was to use the Timer in frequency counter mode with the LSE clock(External Crystal) connected to the Clock pin. So the Input timervalue will be saved on each Signal edge, after two edges the difference could be calculated. For an input Frequency of 1Hz the difference has to be exactly 32768. To increase the accuracy was the presacaler was set to the maximum value of 8. So the value has to be exactly 8*32768. To further increase the accuracy the whole process will be repeated 20 Times and then the average deviation will be calculated. From this deviation the correction value per 1 ppm could be calculated. But after the calibration procedure the Watch was still not very acurate.

Load Capacitance While searching for the source of the Clock Deviattion i came across the
Application Note 2867 https://www.st.com/resource/en/application_note/cd00221665-oscillator-design-guide-for-stm8af-al-s-stm32-mcus-and-mpus-stmicroelectronics. pdf (https://www.st.com/resource/en/application_note/cd00221665-oscillator-design-guide-for-stm8af-al-s-stm32-mcus-and-mpus-stmicroelectronics.pdf) Which describes the Design guidelines for oscillators used in combination with STM32 controllers. The crystal used in the Clock is the Abracon ABS05W-32.768 kHz-D. The AN2867
recommends 4pF Load Capacitors for this setup. Till now i used 10pF Capacitors, this could
als explain the heavy correction which was needed for the AtMega328P.
So i did a few single measurements to measure the difference of the Changes done. The measurements were done with the same Controller on the same PCB, once with a Battery Supply (2.8V) and once with Power Supply from the Nucleo Board (3,3V), The second change was the Change of the Capacitors from 10pF to 3,9pF (i couldn’t get exactly 4pF on the 0603 Package). The Results could be found in the Table below.
Supply Voltage [V] | Load Capacitance [pF] | Frequency [Hz] | Deviation [ppm]
2,8 | 10 | 32549 | -209
| 3,9 | 32850 | 92
3,3 | 10 | 32548 | -210
| 3,9 | 32857 | 99

So we can conclude that a larger Capacitance slows the oscillator down. The correction needed for the clock was now smaller, but the deviation was still there.

CubeIDE Initialization After another few tests i found out there is a relation between Wakeups and the Deviation of the Clock. So the original Proble was every time the Controller is initialized the code generated by the CubeIDE will initialize the whole Clock System. To initialize the driver strength of the LSE Clock the clock has to be stopped, and syncronized again. This Process will delay the RTC Time by about 0,5 seconds.
Therefore i needed to adapt the initialization for the Controller. The function, which was causing the Problems is the SystemClock_Config(), if there is a LSE configured it would be initialized. So the obvoius solution would be to disable the LSE. But if the LSE is disabled the RTC would need a Clock, so the RTC was also disabled. The big Problem is if the RTC is disabled in the configuration the HAL Driver would not be included in the project. So i copied the initialization Function from the code generated without the RTC and renamed it to SystemClock_Config_without_LSE() in the Project configuration i disabled the function call to the original SystemClock_Config() and called the SystemClock_Config_without_LSE() in the usermain instead. Also the RTC initialization had to be rewritten to only initialize the RTC if the LSE is not running. For this task the Function STM32L4_HAL::HAL_driverInit() was introduced. This Function checks if a RTC clock source is set. The clock source is set in the RCC_BDCR register, which resides in the backupdomain of the STM and therefore is not cleared by a reset. So the initialization will be only done once when the Battery is inserted.

Analog PCB Since the STM32L432K has more usable pins than the Atmega328P it was also possible to route a PCB with the BMA Sensor and the Analog Watchface. The space for the Analog Watchface was already very tight without the BMA Sensor. With the Sensor it got extremely tight, so i had to turn the Controller by 45 Degrees. Sadly I was not able to comply with all the Designrules for the BMA Sensor. Now i have a via under the BMA, i think this is very bad for series production, but for me it is working.


Software for the Analog Version I wanted to keep the changes on the Software as simple as possible and don’t want to maintain two folders with common files between both variants. I created a combined software, which selects the correct DisplayManager depending on the watch variant saved in the flash, right next to the calibration values for the RTC. So i have only one Software, which fits the analog and the binary version of the watch, but i need to specify, via a define in the calibration software, if it is a analog or a binary watch. For further development i also added some defines in the software, which can disable a specific watch variant. This can be used either to save flash memory or to reduce the possible software bugs in the software.

## 5 STM Version Manual

### 5.1 Read the time

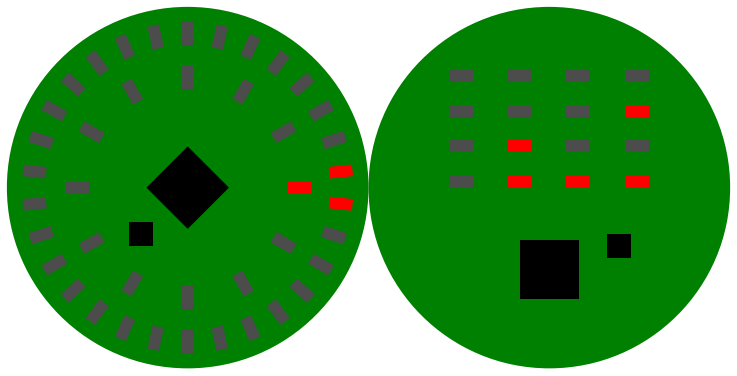
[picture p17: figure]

To read the Watch it is necessary to activate the Display this can be either done via double tapping the Housing or raising the arm to take a look on the watch(tilt it by a minimum of 12 degrees with the Watchface facing up and holding it steady for about one second)

Analog The analog Version an be read equally to a normal Watch. In the inner Ring the Hours from 1 to 12 are displayed. In the outer Ring the minutes are displayed from 0 to 59, since there are only 30 LEDs in the outer ring for uneven minutes the nearest two LEDs are lit up. For example for 3:15 the LEDs signalling 14 and 16 are lit up.

Binary in the Binary Version the LEDs are read columnwise as BCD code starting with 1 at the bottom. So the right two columns are showing the Minutes. If an LED is litone have to add its Value to the Minutes if not then nothing is added. So for the full hour no led in the right two columns will be lit. In the example above in the first column no LED is lit. In the second column the LED for 1 and 2 are lit. In the third column the LED for 1 is lit and in the last column the LED for 1 and 4 are lit. So it is 3:15.

### 5.1.1 setting the Time

To enter the Time setting mode you have to turn the Watch in show time mode upside down, Watchface facing the ground an double Tap it. The Watch enters debouncing mode. In debouncing mode the Hours 80 and Minutes 80 are blinking for the binary version for the Analog Version Hours 12 and 6 are blinking. (Blinking leds are displayed brighter in the graphic.

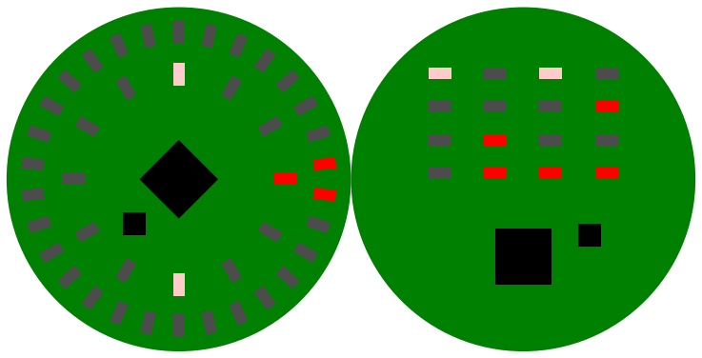
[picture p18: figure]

While in debouncing mode turn the watch around again (Watchface facing up) and double Tap it again to enter Set Hour mode.

In the set hour mode the hour can be increased by leaning the Watch away from you and decreased by leaning the watch towards you. In the Analog Version the LED signalling 10 Minutes is blinking, when the current hour setting is PM. Once the hour is set correctly double Tap the Watch again to enter Set Minute Mode.

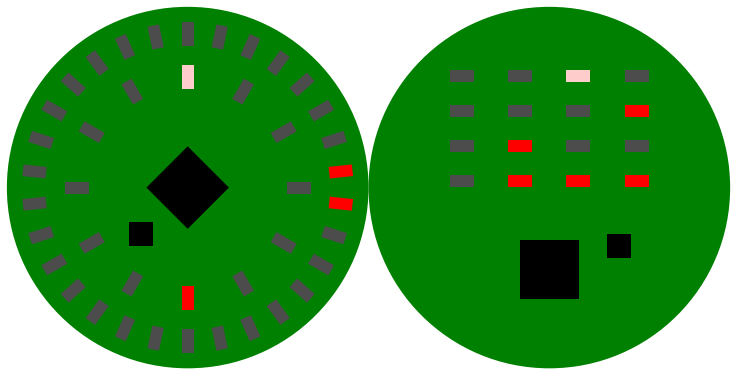
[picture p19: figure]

The Set hour mode works exactly like to set hour mode. Increasing and decreasing is done via leaning the Watch fowrward an backward. Once finished a double Tap sets the Seconds to 0 and starts the Watch again.

### 5.2 Read the Date

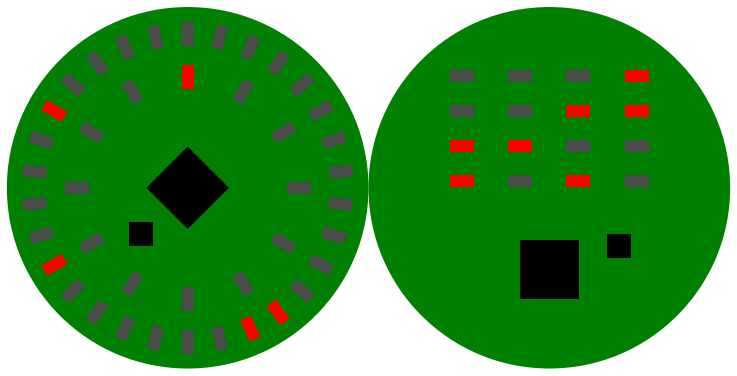
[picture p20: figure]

To enter the Date display mode tilt the Watch in Time Mode to the Front(Facing away from you) at least 10 degrees and double Tap it.

Analog On the analog Version The Minutes 40 and 50 are lit up to signal Date Display. On the Hours Ring the Month is displayed as Hour and the Day is Displayed as Minutes.

Binary On the binary Version the first column is showing 3 to signal Date Display. In the second and third column the Day is displayed as BCD Code and the Month is displayed in binary code(it does not stop on 9)

A double Tap with the watch facing up switches back to show time mode.

### 5.2.1 setting the Date

To enter the Date setting mode you have to turn the Watch in show date mode upside down, Watchface facing the ground an double Tap it. The Watch enters debouncing mode. In debouncing mode the Hours 8 and Minutes 80 are blinking for the binary version for the Analog Version Minutes 40 and 50 are blinking. (Blinking leds are displayed brighter in the graphic.

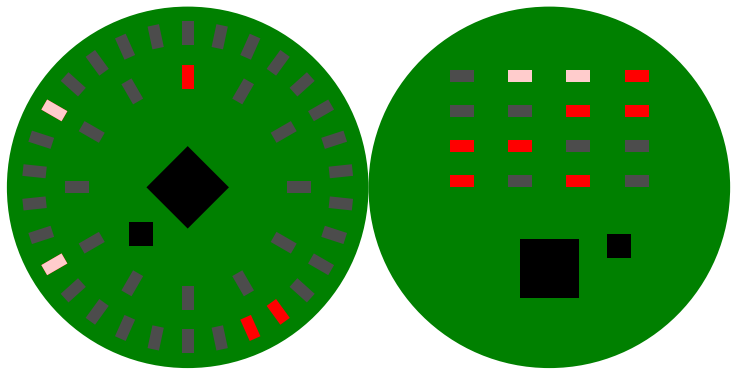
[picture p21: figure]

While in debouncing mode turn the watch around again (Watchface facing up) and double Tap it again to enter set day mode.

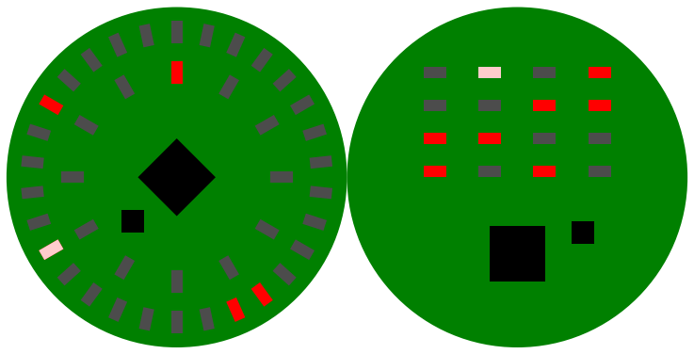
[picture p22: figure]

Setting the Day works exactly like setting the hour. Increasing and decreasing is done via leaning the Watch fowrward an backward. Once finished a double Tap switches to set month mode.

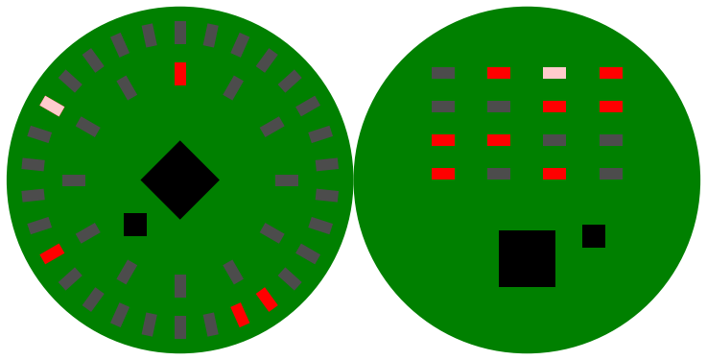
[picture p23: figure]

Setting the Month works exactly like setting the hour. Increasing and decreasing is done via leaning the Watch fowrward an backward. Once finished a double Tap switches to set year mode.

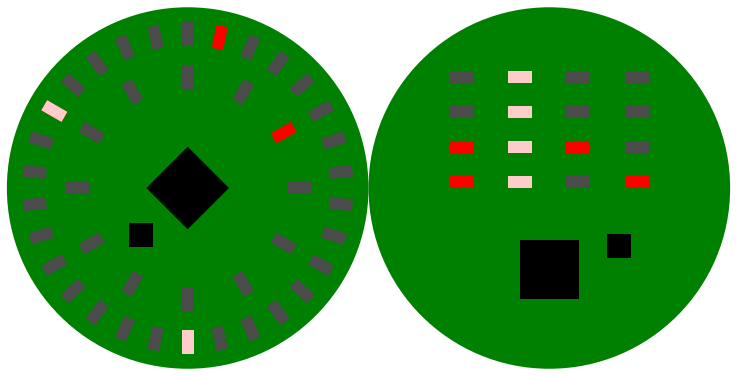
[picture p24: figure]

The year is only used for the leap year calculation and can be only set between 0 and 99.

Analog In the Analog Version the Set year mode is signalized by blinking both minute LEDs 30 and 50. The Year tens are shown in the inner ring with one LED per Counter and the ones are shown in the outer ring with one LED per counter. In this example XX21.

Binary Setting Year mode is displayed by showing 3 in the first column and blinking all LEDs in the second column. The year is displayed in columns 3 and 4. In this example XX21.

Setting the Month works exactly like setting the hour. Increasing and decreasing is done via leaning the Watch fowrward an backward. Once finished a double Tap sets the Seconds to 0 and starts the Watch again.

### 5.3 Todays Steps

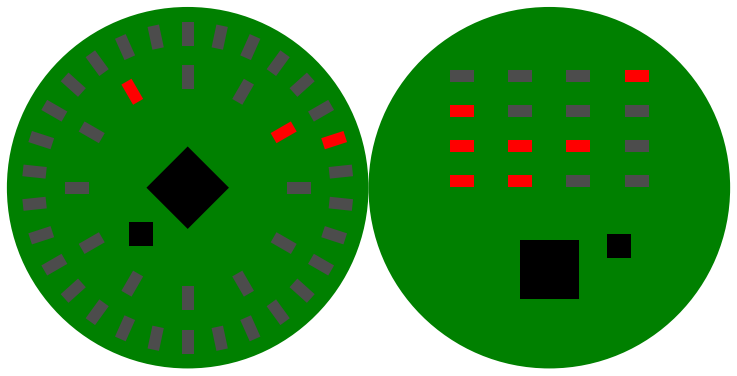
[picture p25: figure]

To enter Step display mode tilt the Watch in Time Mode to the Back(Facing you) at least 10 degrees and double Tap it.

Analog On the Analog Watch the hour LED 11 is lit up with the overflow counter (from 0(12 o’clock) to 3. The overflow counter counts the number of whole rounds on the Stepcounter. An overflow occurs on 15000. The current Stepcounter without overflow is displayed in the outer Ring. Each LED signalizes 500 Steps. The value is rounded to 500. In the Example the overflow counter shows 2 and the counter itself shows 6. 2 ∗ 15000 + 6 ∗ 500 = 33000

Binary On the binary Watch the Step Counter is signalized by the forst column showing 7. Column 2 to 4 shows the steps in 100 counts rounded to 100 counts. So 32768 in the exmample will be shown as (7)328

A double Tap with the watch facing up switches back to show time mode.

### 5.4 Show steps history

To enter the steps history mode you have to turn the Watch in show steps mode upside down, Watchface facing the ground an double Tap it.


The history counter can be increased and decreased by leaning the watch back and forth.

Analog The steps history mode looks like the Show steps mode, but there is an additional LEDas Hitory Counter lit up. The History counter starts at Hour 4 and increases depending on how far ago the Date is. In the Example Hour 5 is shown, so the history is from 2 days ago. The steps are show as in the Show Steps mode, so there were 7500 Steps done two days ago.

Binary The steps hitory mode is signalized by the H80 LED. The LEDs below show how long ago the Steps were counted, the counter starts yesterday with 0. so the example shows the Data from 2 Days ago. The steps are displayed as in the show steps mode. so the example shows 7500 Steps 2 days ago.

to leave this mode double tap changes to the show Battery Voltage.

### 5.5 show battery voltage

To enter the steps history mode you have to double tap the Watch in show steps history mode.


Analog The show battery voltage is signalized by the Hour 11 and 12 lighting up together. The voltage is shown on the minutes ring, scaled from 3.5V to 1,5V, so each quarter is 0,5V. The Watch in the example is showing 2,95V.

Binary The show battery voltage is signalized by the Hour 40 LED. Column 2 to 4 are showing the Battery voltage in 10mV granularity. So the Example shows 2950mV = 2, 95V

A double Tap with the watch facing up switches back to show steps mode.

## 6 Making the watch rechargable

The battery of the STM Watch version will last for about 6 months, so every 5 months i have to open the housing, change the battery and close the housing again. Also from an enviromental point of view it is not good to waste a battery every 6 months. So there has to be a solution to make the watch rechargable.

### 6.1 possible solutions

### 6.1.1 Just use a rechargable battery

The easiest variant to make the watch rechargable would be to directly use a rechargable battery wiht the same PCB. This would require no changes on the PCB level, but the rechargable batteries have a smaller capacitance than the not rechargable lithium batteries which are used till now. So from the environmental point of view this is even worse, since the housing will wear out and i have to change the housing also very frequently. With this solution it also won’t be possible to make the housing 100% waterproof(glue it shut).

### 6.1.2 charging pins on the outside of the watch

Another possible solution would be to insert some contacts in the housing to be able to contact the battery from the outside. This would either require a battery management controller inside of the watch or in a charging bay. Since the charging bay for the watch would be also a special construction i would have gone for the charging bay with the integrated battery managment. This would also make the battery directly connected tothe outside of the watch possibly draining the battery when the watch is wet or sweaty. For this problem a possible solution would be to add a reed contact to one of the pins of the battery. to experiment a bit with these variant i created a devboard ( see Schematics/devboards/LiPo_Circuit). This devboard is using a LTC4054ES5-4.2 as a battery controller. With the devboard i was able to run the watch for about 2 months without recharging. If i don’t have to open the watch to recharge the battery this is sufficient.

### 6.1.3 adding a small solar cell

With a very small solar cell it would also be possible to power the watch and maybe even charge the battery. If the solar cell is not powerfull enough to charge the watch in the daily usage it would also be possible to build a special charging box which charges the watch by shining light directly on the solar cell. The problem with this solution was the needed space on the watchface. The goal of the watch is to keep it as small as possible so it is easy to use and smaller than a normal smart watch.

### 6.1.4 charging the watch via wireless charging

This is a very comfortable solution for the user, but the most complex solution to implement in the watch itself. Also this solution would make it possible to fill the complete housing with epoxy, so it is 100% waterproof. Although this solution is the most complex solution, it is also the most elegant one so it is also the one which gets implemented.

### 6.2 possible porblems when using lithium polymer batteries

### 6.2.1 overcurrent protection

The battery has to be protected aganist overcurrent so it won’t start burning suddenly. Luckily most batteries you can buy on ebay or other sources already have an integrated overcurrent protection.

### 6.2.2 undervoltege protection

Lithium batteries will wear out when they are discharged below certain levels, so this has to be avoided. Some Batteries already have an integrated undervoltage protection, but most batterymanagent ICs also include a undervoltage protection.

### 6.2.3 voltage levels

a typical Lithium Polymer battery has a undervoltage protection at 2V and a charging Voltage of 4.2V , so either all parts have to be tolerant to 2V to 4.2V or we need to use some kind of Voltage regulator or DCDC Converter. For the STM32 tis is fine, but the BMA456 is only specified from 1.6V to 4.0V , so we cannot use the whole range from the lithium polymer battery. For this reason in included the TPS62203DBV which is a step-down converter to 3.3V , this will also decrease the needed current from the battery when the voltage is higher than needed.

### 6.3 chosen solution: wireless charging

### 6.3.1 Implementing a testboard

Wireless charging can either be implemented via a selfmade schematic or via an IC. While researching i came across the LTC4124 Controller from Amalog devices: https://www.analog.com/en/products/ltc4124.html. (https://www.analog.com/en/products/ltc4124.html) This IC features an wireless power receiver and an integrated batterymanagement, so it will be the only needed chip for the wireless charging part of the schematic. Sadly the LTC4124 IC is a very small QFN package and only has the pad underneath as ground, so it has to be soldered very good. The testboard can be found under Schematics/devboards/LiPo_Wireless.

receiving part This testboar features a receiving part using the LTC4124. To get it running the LTC4124 needs to receive power wirelessly to connect the battery to the output pin. So you won’t have any luck with the receiver until you get the sender running. A LED is showing when the receiver is charging, this can be used as a finst indcator that something is working. But beware the open dain pin of for the charging LED is only drawing 300ţA so make sure to use a low current LED, otherwise you will be fooled by the LED not working. Trust me this will drive you nuts...

sending part The schematic for the sending part was straight from the datasheet of the LTC4124 nevertheless i was not able to get it working, the power dropped once the MOSFET turned on after adding an additional resistor in line with the induction coil and a big capacitor paralell to the power supply the voltage stayed stable, but it was not supplying enough energy to charge the battery. Anyhow it was enough energy to swith on the output pin of the LTC4124. This was the first sign of life for the whole board. However i was not able to improve the sending part any further...

alternative Sender - QI charging pad The next option was to use a already available charging pad to send enough energy to charge the battery. I tried this with a QI charging pad, but sadly the QI charging standard includes a handshake which will prevent the sender to send energy when there is no receiver present. The charging was working if the coil of the sender was placed between the QI charging pad and a QI charging phone. Sadly the chargin was not possible when the coil was placed on the phone, or the phone was more than 10mm away from the charging pad. So it was not possible to charge the assembled watch with this method.

alternative Sender - Evaluation board The next solution i tried was to order an evaluation board for the LTC4124 and just use the sender which comes with the evaluation board. This worked like a charm.

### 6.3.2 Binary PCB

TODO

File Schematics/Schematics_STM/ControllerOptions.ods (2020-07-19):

Controller | Datasheet | WebAdresse | Price | LowPower Mode | RetentionSpace | PgmSpace KB | current Sum nA | Num Pins | unusable Pins | SPI Pins | Int Pins | Cal Pins | SWD | free Pins | double used free
Atmega 328P | http://www.farnell.com/datasheets/798182.pdf | https://www.develektro.com/MICROCHIP-ATMEGA328P-MU-MCU-8BIT-AVR-32K-FLASH-32QFN | 2,34 | sleep | 2048 | 32 | 900 | 32 | 12 | 4 | 1 | 0 | 0 | 15 | 15
STM32L432KBU6 | http://www.farnell.com/datasheets/2283391.pdf | https://www.develektro.com/STMICROELECTRONICS-STM32L432KBU6-MCU-ARM-CORTEX-M4-80MHZ-QFN-32 | 6,6 | Shutdown | 128 | 128 | 535 | 32 | 9 | 4 | 1 | 1 | 2 | 15 | 18
STM32L432KBU6 | http://www.farnell.com/datasheets/2283391.pdf | https://www.develektro.com/STMICROELECTRONICS-STM32L432KBU6-MCU-ARM-CORTEX-M4-80MHZ-QFN-32 | 6,6 | Standby | 128 | 128 | 448 | 32 | 9 | 4 | 1 | 1 | 2 | 15 | 18
STM32L051K8U6 | http://www.farnell.com/datasheets/1886888.pdf | https://www.develektro.com/STMICROELECTRONICS-STM32L051K8U6-MCU-32BIT-CORTEX-M0-32MHZ-UFQFPN-32 | 4,01 | Standby | 20 | 64 | 770 | 32 | 9 | 4 | 1 | 1 | 2 | 15 | 18
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

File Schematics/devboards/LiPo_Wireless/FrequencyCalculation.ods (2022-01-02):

f_DRIVE[Hz] | '=1Mhz*50k/ | Rset
205761,316872428 |  | 243000 |  | L_Tx[µH] | 7,5 | Würth Groß | 7,5 | µH
f_TX-TANK[Hz] | '=1.29* | f_DRIVE[Hz] |  |  |  | Würth Klein | 12,6 | µH | 12,6
265432,098765432 |  | 205761,316872428 |  | L_RX[µH] | 12,6 | TDK | 8,32 | µH
C_Tx [F] | '=(1/(2*PI* | f_TX-TANK[Hz] | ))^2/ | L_Tx[H] |  | C_Tx [nF] | 47,93713977843
4,793713977843E-08 |  | 265432,098765432 |  | 0,0000075 |  | C_Txr [nF] | 47
C_Tx [nF] | C_Tx chosen [nF] | C_Tx chosen [F] |  |  |  | Abweichung | 1,99391442219149
47,93713977843 | 47 | 0,000000047 |  |  |  | C_Rx [nF] | 47,4834489912413
 |  |  |  |  |  | C_Rxr [nF] | 47
f_TX-TANK[Hz] | '=1/(2*PI*SQRT( | L_Tx[H] | * | C_Tx chosen [F] | ')) | Abweichung | 1,02861487498147
268065,282144144 |  | 0,0000075 |  | 0,000000047
f_RX_TANK[Hz] | '= | f_DRIVE[Hz]
205761,316872428 |  | 205761,316872428
C_Rx [F] | '=(1/(2*PI* | f_RX-TANK[Hz] | ))^2/ | L_RX[H]
4,74834489912413E-08 |  | 205761,316872428 |  | 0,0000126
C_Rx [nF]
47,4834489912413

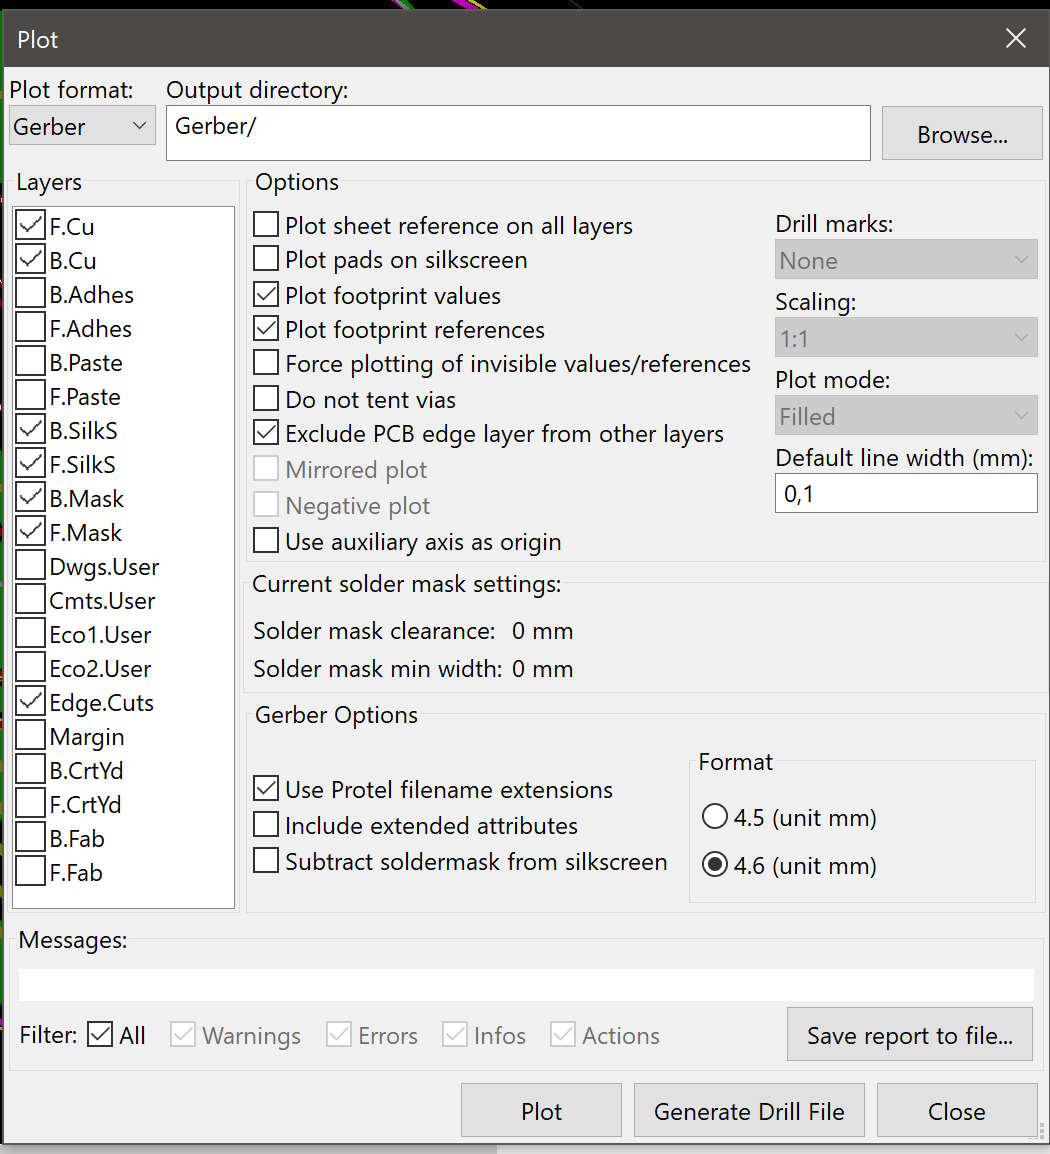
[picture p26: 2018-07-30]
Schematics/Schematics_328P/Gerber/settings_rename_edge_cuts_to_gbr.png

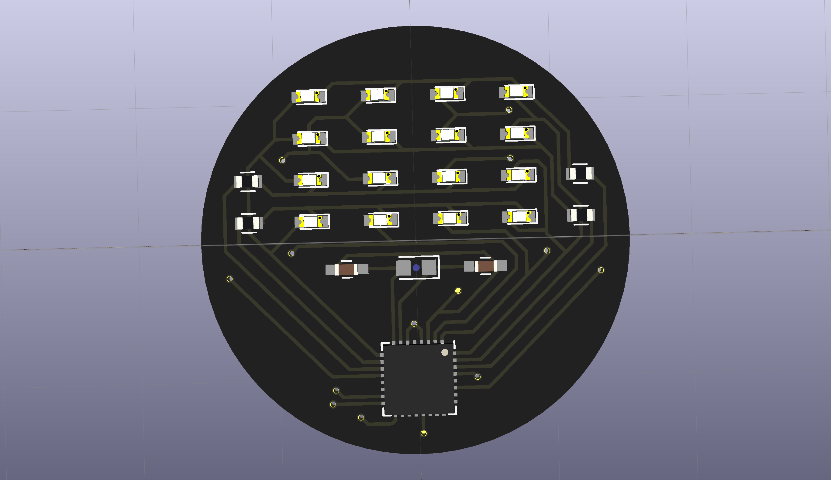
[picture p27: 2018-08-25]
Schematics/Schematics_328P/Watch.png

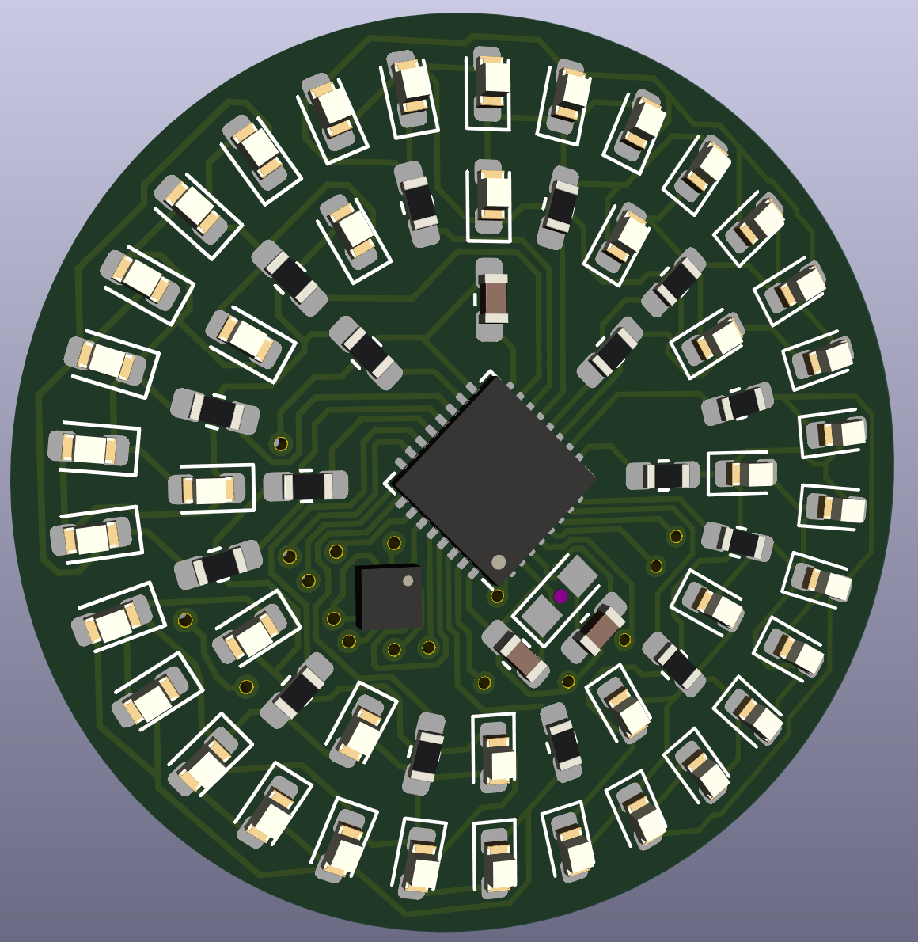
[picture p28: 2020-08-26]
Schematics/Schematics_analog_STM/AnalogWatch.png

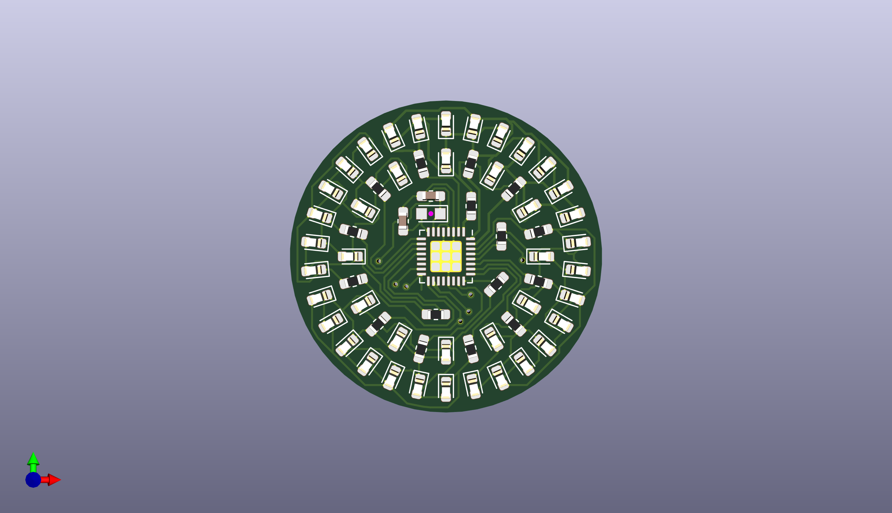
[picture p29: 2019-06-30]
Schematics/Schematics_analog_328P/AnalogWatch.png

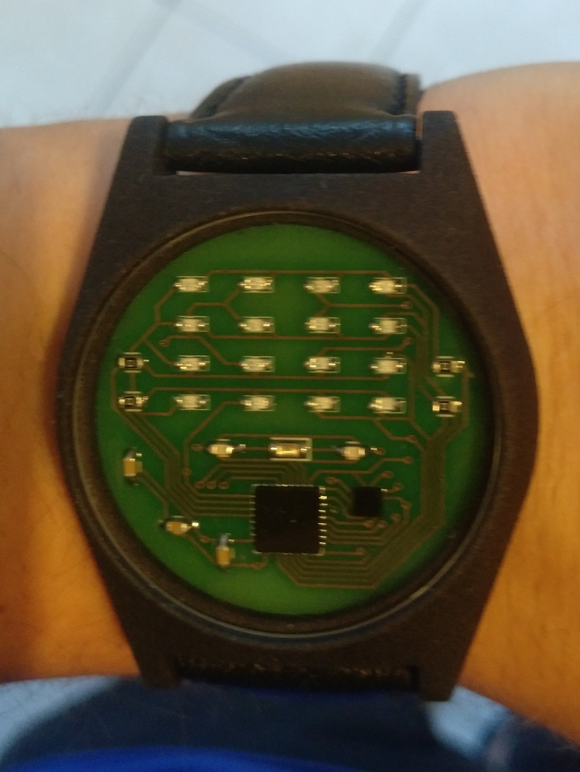
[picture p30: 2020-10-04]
Pictures/Watch_STM32_Binary.jpg

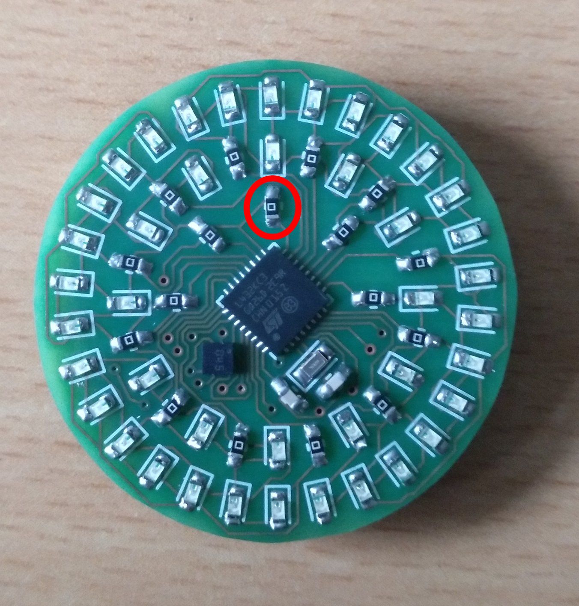
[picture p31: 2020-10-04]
Pictures/PCB_STM32_Analog.jpg

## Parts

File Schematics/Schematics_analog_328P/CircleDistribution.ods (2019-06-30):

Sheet: OuterCircle_LED
 |  |  | Number Offset | 0
 | Angle Offset | 6 | Number | 30 |  | xoffs |  | 100
 |  |  | Radius | 13.2 | mm | yoffs |  | 100
1 | 18 | 0.314159265358979 | 12.553946015096 | -4.07902432574931 |  | D1 | D11 | 112.553946015096 | 95.9209756742507 | 18
2 | 30 | 0.523598775598299 | 11.4315353299546 | -6.6 |  | D2 | D12 | 111.431535329955 | 93.4 | 30
3 | 42 | 0.733038285837618 | 9.8095116963016 | -8.83252400393693 |  | D3 | D13 | 109.809511696302 | 91.1674759960631 | 42
4 | 54 | 0.942477796076938 | 7.75876533026065 | -10.6790243257493 |  | D4 | D14 | 107.758765330261 | 89.3209756742507 | 54
5 | 66 | 1.15191730631626 | 5.36892368860057 | -12.0588000408823 |  | D5 | D15 | 105.368923688601 | 87.9411999591177 | 66
6 | 78 | 1.36135681655558 | 2.74443431879442 | -12.9115483296862 |  | D6 | D16 | 102.744434318794 | 87.0884516703138 | 78
7 | 90 | 1.5707963267949 | 8.08266887437253E-16 | -13.2 |  | D7 | D17 | 100 | 86.8 | 90
8 | 102 | 1.78023583703422 | -2.74443431879442 | -12.9115483296862 |  | D8 | D18 | 97.2555656812056 | 87.0884516703138 | 102
9 | 114 | 1.98967534727354 | -5.36892368860056 | -12.0588000408823 |  | D9 | D19 | 94.6310763113995 | 87.9411999591177 | 114
10 | 126 | 2.19911485751286 | -7.75876533026064 | -10.6790243257493 |  | D10 | D43 | 92.2412346697394 | 89.3209756742507 | 126
11 | 138 | 2.40855436775217 | -9.80951169630161 | -8.83252400393693 |  | D11 | D44 | 90.1904883036984 | 91.1674759960631 | 138
12 | 150 | 2.61799387799149 | -11.4315353299546 | -6.6 |  | D12 | D45 | 88.5684646700454 | 93.4 | 150
13 | 162 | 2.82743338823081 | -12.553946015096 | -4.07902432574931 |  | D13 | D46 | 87.446053984904 | 95.9209756742507 | 162
14 | 174 | 3.03687289847013 | -13.1276890188612 | -1.37977571513303 |  | D14 | D47 | 86.8723109811388 | 98.620224284867 | 174
15 | 186 | 3.24631240870945 | -13.1276890188612 | 1.37977571513303 |  | D15 | D48 | 86.8723109811388 | 101.379775715133 | 186
16 | 198 | 3.45575191894877 | -12.553946015096 | 4.07902432574931 |  | D16 | D32 | 87.446053984904 | 104.079024325749 | 198
17 | 210 | 3.66519142918809 | -11.4315353299546 | 6.6 |  | D17 | D33 | 88.5684646700454 | 106.6 | 210
18 | 222 | 3.87463093942741 | -9.8095116963016 | 8.83252400393693 |  | D18 | D34 | 90.1904883036984 | 108.832524003937 | 222
19 | 234 | 4.08407044966673 | -7.75876533026065 | 10.6790243257493 |  | D19 | D35 | 92.2412346697394 | 110.679024325749 | 234
20 | 246 | 4.29350995990605 | -5.36892368860056 | 12.0588000408823 |  | D20 | D36 | 94.6310763113995 | 112.058800040882 | 246
21 | 258 | 4.50294947014537 | -2.74443431879443 | 12.9115483296862 |  | D21 | D37 | 97.2555656812056 | 112.911548329686 | 258
22 | 270 | 4.71238898038469 | -2.42480066231176E-15 | 13.2 |  | D22 | D38 | 100 | 113.2 | 270
23 | 282 | 4.92182849062401 | 2.74443431879442 | 12.9115483296862 |  | D23 | D21 | 102.744434318794 | 112.911548329686 | 282
24 | 294 | 5.13126800086333 | 5.36892368860056 | 12.0588000408823 |  | D24 | D22 | 105.368923688601 | 112.058800040882 | 294
25 | 306 | 5.34070751110265 | 7.75876533026064 | 10.6790243257493 |  | D25 | D23 | 107.758765330261 | 110.679024325749 | 306
26 | 318 | 5.55014702134197 | 9.8095116963016 | 8.83252400393694 |  | D26 | D24 | 109.809511696302 | 108.832524003937 | 318
27 | 330 | 5.75958653158129 | 11.4315353299546 | 6.60000000000001 |  | D27 | D25 | 111.431535329955 | 106.6 | 330
28 | 342 | 5.96902604182061 | 12.553946015096 | 4.07902432574931 |  | D28 | D26 | 112.553946015096 | 104.079024325749 | 342
29 | 354 | 6.17846555205993 | 13.1276890188612 | 1.37977571513304 |  | D29 | D27 | 113.127689018861 | 101.379775715133 | 354
30 | 6 | 0.10471975511966 | 13.1276890188612 | -1.37977571513303 |  | D30 | D28 | 113.127689018861 | 98.620224284867 | 6

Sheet: InnerCircle_LED
 |  |  | Number Offset | 100
 | Angle Offset | 0 | Number | 12 |  | xoffs |  | 100
 |  |  | Radius | 9.5 | mm | yoffs |  | 100
1 | 30 | 0.523598775598299 | 8.22724133595217 | -4.75 |  | D101 | D101 | 108.227241335952 | 95.25 | 30
2 | 60 | 1.0471975511966 | 4.75 | -8.22724133595217 |  | D102 | D102 | 104.75 | 91.7727586640478 | 60
3 | 90 | 1.5707963267949 | 5.81707229594993E-16 | -9.5 |  | D103 | D103 | 100 | 90.5 | 90
4 | 120 | 2.0943951023932 | -4.75 | -8.22724133595217 |  | D104 | D401 | 95.25 | 91.7727586640478 | 120
5 | 150 | 2.61799387799149 | -8.22724133595217 | -4.75 |  | D105 | D402 | 91.7727586640478 | 95.25 | 150
6 | 180 | 3.14159265358979 | -9.5 | -1.16341445918999E-15 |  | D106 | D403 | 90.5 | 100 | 180
7 | 210 | 3.66519142918809 | -8.22724133595217 | 4.75 |  | D107 | D301 | 91.7727586640478 | 104.75 | 210
8 | 240 | 4.18879020478639 | -4.75 | 8.22724133595217 |  | D108 | D302 | 95.25 | 108.227241335952 | 240
9 | 270 | 4.71238898038469 | -1.74512168878498E-15 | 9.5 |  | D109 | D303 | 100 | 109.5 | 270
10 | 300 | 5.23598775598299 | 4.75 | 8.22724133595217 |  | D110 | D201 | 104.75 | 108.227241335952 | 300
11 | 330 | 5.75958653158129 | 8.22724133595217 | 4.75 |  | D111 | D202 | 108.227241335952 | 104.75 | 330
12 | 0 | 0 | 9.5 | 0 |  | D112 | D203 | 109.5 | 100 | 0

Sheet: InnerCircle_R
 |  |  | Number Offset | 100
 | Angle Offset | 15 | Number | 12 |  | xoffs |  | 100
 |  |  | Radius | 9.5 | mm | yoffs |  | 100
1 | 45 | 0.785398163397448 | 6.7175144212722 | -6.7175144212722 |  | D101 | R14 | 106.717514421272 | 93.2824855787278 | 45
2 | 75 | 1.30899693899575 | 2.45878092847395 | -9.17629534974615 |  | D102 | R13 | 102.458780928474 | 90.8237046502539 | 75
3 | 105 | 1.83259571459405 | -2.45878092847395 | -9.17629534974615 |  | D103 | R11 | 97.5412190715261 | 90.8237046502539 | 105
4 | 135 | 2.35619449019234 | -6.7175144212722 | -6.7175144212722 |  | D104 | R44 | 93.2824855787278 | 93.2824855787278 | 135
5 | 165 | 2.87979326579064 | -9.17629534974615 | -2.45878092847395 |  | D105 | R43 | 90.8237046502539 | 97.5412190715261 | 165
6 | 195 | 3.40339204138894 | -9.17629534974615 | 2.45878092847394 |  | D106 | R41 | 90.8237046502538 | 102.458780928474 | 195
7 | 225 | 3.92699081698724 | -6.7175144212722 | 6.7175144212722 |  | D107 | R34 | 93.2824855787278 | 106.717514421272 | 225
8 | 255 | 4.45058959258554 | -2.45878092847395 | 9.17629534974615 |  | D108 | R33 | 97.5412190715261 | 109.176295349746 | 255
9 | 285 | 4.97418836818384 | 2.45878092847394 | 9.17629534974615 |  | D109 | R31 | 102.458780928474 | 109.176295349746 | 285
10 | 315 | 5.49778714378214 | 6.7175144212722 | 6.7175144212722 |  | D110 | R24 | 106.717514421272 | 106.717514421272 | 315
11 | 345 | 6.02138591938044 | 9.17629534974615 | 2.45878092847395 |  | D111 | R23 | 109.176295349746 | 102.458780928474 | 345
12 | 15 | 0.261799387799149 | 9.17629534974615 | -2.45878092847395 |  | D112 | R21 | 109.176295349746 | 97.5412190715261 | 15

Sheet: Groups
 | D9 | D8 | D7 | D6 | D5 | D4 | D3 | D2 | D1 | Dx03 | Dx02 | Dx01
C1 | x | x | x | x | x | x | x | x | x | x | x | x
C2 |  | x | x | x | x | x | x | x | x | x | x | x
C3 |  | x | x | x | x | x | x | x |  | x | x | x
C4 |  | x | x | x | x | x | x |  |  | x | x | x
Components to Remove
C1
C2 | D29
C3 | D39 |  |  |  |  |  |  |  | D31
C4 | D49 |  |  |  |  |  |  | D42 | D41

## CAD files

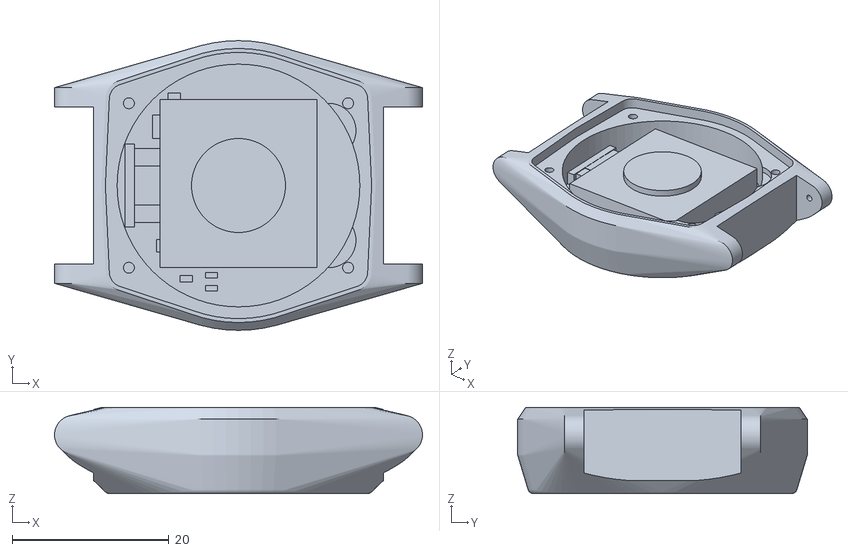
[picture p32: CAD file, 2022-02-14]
Housing/HousingAssembled.stl
47.0 x 37.0 x 11.0

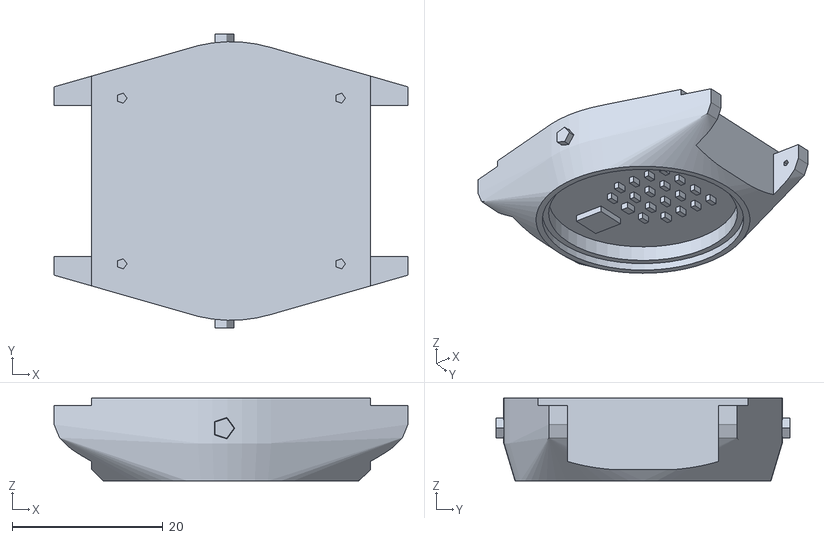
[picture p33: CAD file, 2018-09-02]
HousingAssembled.stl
47.0 x 39.0 x 11.0

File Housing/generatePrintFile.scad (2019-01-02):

use <Housing.scad>
echo("generating STL File");
$fs=0.01;
$fa=1;
printall();

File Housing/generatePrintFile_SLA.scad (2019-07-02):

use <Housing.scad>
echo("generating STL File");
$fs=0.01;
$fa=1;
printSLASideBySide();

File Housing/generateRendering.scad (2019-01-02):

use <Housing.scad>
echo("generate Rendering STL File");
$fs=0.05;
$fa=5;
rendering();

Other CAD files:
Housing/Housing.scad

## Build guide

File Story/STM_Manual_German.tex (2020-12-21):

\section{Bedienungsanleitung STM Version}
\subsection{Zeit ablesen}
\begin{center}

\end{center}
Um die Uhrzeit abzulesen muss die Anzeige aktiviert werden, das kann entweder durch doppeltes Antippen aktiviert werden, oder durch anheben des Armes um einen Blick auf die Uhr zu werfen (drehen der Uhr um mindestens 12 Grad während die Anzeige nach oben zeigt und anschließendes stillhalten für etwa eine Sekunde)

\paragraph{Analog}
Die analoge Uhr kann entsprechend einer normalen Analoguhr abgelesen werden. Der innere Ring zeigt die aktuelle Stunde zwischen eins und zwölf an.
Der äußere Ring zeigt die Minuten von null bis neunundfünfzig an, da der äußere Ring nur 30 LEDs besitzt werden für ungerade Minuten die LEDs beleuchtet, die der eigentlichen Minutenanzahl am nächsten sind.
Für 3:15 Uhr wird z.B. die Stundenanzeige für 3 Uhr aktiviert und die Minutenanzeige für 14 und 16 Minuten, wie auf der Grafik zu sehen.

\paragraph{Binary}
die Binäre Version wird spaltenweise gelesen. Die Wertigkeit beginnt von unten mit eins, zwei, vier und acht. Die Linken beiden Spalten zeigen die Stundenanzahl die rechten beiden die Minutenanzahl.
Wenn eine LED leuchtet muss man deren Wertigkeit zu der Summe hinzuzählen.
Zur vollen Stunde werden also alle LEDs in den rechten beiden Spalten aus sein.
In dem Beispiel ist in der Stunden Zehnerspalte keine LED aktiviert.
In der zweiten Spalte ist LED1 und LED2 beleuchtet, damit ergibt sich 3 als Stundenanzahl.
In der dritten Spalte Minuten Zehner brennt LED1, in der vierten Spalte LED1 und LED4, somit ergeben sich 15 Minuten.
Insgesamt also 3:15 Uhr
\subsubsection{Einstellen der Zeit}
Um in den Zeiteinstellungsmodus zu starten muss sich die Uhr im Zeitanzeige Modus befinden. Anschließend muss die Uhr mit der ANzeige nach unten doppelt angetippt werden, damit wechselt die Uhr in den Entprellmodus. 
Im Entprellmodus blinken in der Binärversion die Azeigen für Stunden 80 und Minuten 80. In der analogen Variante blinkt die Anzeige für die Stunden 12 und 6. (Blinkende LEDs werden in der Grafik heller dargestellt)

\begin{center}

\end{center}
Im Entprellmodus muss die Anzeige der Uhr wieder nach Oben gedreht werden und doppelt angetippt werden.
\begin{center}

\end{center}
Im Stundeneinstellungsmodus kann die Stundenanzahl durch kippen der Uhr nach Oben (weg vom Benutzer) erhöht und durch kippen nach unten verringert werden. In der analogen Variante blinkt die LED, die normalerweise 10 Minuten anzeigt, wenn die eingestellte Stundenanzahl nach 12 Uhr mittags liegt.
Sobald die Stundenanzahl korrekt eingestellt ist kann durch doppeltippen der Minuteneinstellungsmodus aktiviert werden.
\begin{center}

\end{center}
der Minuteneinstellungsmodus funktioniert genau wie der Stundeneinstellungsmodus, erhöhen und verringern der Minutenanzahl kann duch kippen der Uhr erreicht werden. Wenn die Minutenanzahl richtig eingestellt ist kann der Einstellungsmodus mit doppeltippen verlassen werden. Beim Verlassen des Einstellungsmodus werden die Sekunden auf null gestellt und die Uhr beginn wieder zu laufen.
%\subsection{Read the Date}
%\begin{center}
%\includegraphics[width=0.6\textwidth]{../Graphics/Date25_Dez}
%\end{center}
%To enter the Date display mode tilt the Watch in Time Mode to the Front(Facing away from you) at least 10 degrees and double Tap it.
%\paragraph{Analog}
%On the analog Version The Minutes 40 and 50 are lit up to signal Date Display.
%On the Hours Ring the Month is displayed as Hour and the Day is Displayed as Minutes.
%
%\paragraph{Binary}
%On the binary Version the first column is showing 3 to signal Date Display.
%In the second and third column the Day is displayed as BCD Code and the Month is displayed in binary code(it does not stop on 9)\\
%\\
%A double Tap with the watch facing up switches back to show time mode.
%
%\subsubsection{setting the Date}
%To enter the Date setting mode you have to turn the Watch in show date mode upside down, Watchface facing the ground an double Tap it. The Watch enters debouncing mode.
%In debouncing mode the Hours 8 and Minutes 80 are blinking for the binary version for the Analog Version Minutes 40 and 50 are blinking. (Blinking leds are displayed brighter in the graphic.
%\begin{center}
%\includegraphics[width=0.6\textwidth]{../Graphics/Date25_Dez_debouncing}
%\end{center}
%While in debouncing mode turn the watch around again (Watchface facing up)  and double Tap it again to enter set day mode.
%\begin{center}
%\includegraphics[width=0.6\textwidth]{../Graphics/Date25_Dez_SetDay}
%\end{center}
%Setting the Day works exactly like setting the hour. Increasing and decreasing is done via leaning the Watch fowrward an backward. Once finished a double Tap switches to set month mode.
%\begin{center}
%\includegraphics[width=0.6\textwidth]{../Graphics/Date25_Dez_SetMonth}
%\end{center}
%Setting the Month works exactly like setting the hour. Increasing and decreasing is done via leaning the Watch fowrward an backward. Once finished a double Tap switches to set year mode.
%\begin{center}
%\includegraphics[width=0.6\textwidth]{../Graphics/Date25_Dez_SetYear21}
%\end{center}
%The year is only used for the leap year calculation and can be only set between 0 and 99. 
%\paragraph{Analog} 
%In the Analog Version the Set year mode is signalized by blinking both minute LEDs 30 and 50. The Year tens are shown in the inner ring with one LED per Counter and the ones are shown in the outer ring with one LED per counter. In this example XX21.
%\paragraph{Binary}
%Setting Year mode is displayed by showing 3 in the first column and blinking all LEDs in the second column. The year is displayed in columns 3 and 4. In this example XX21.\\
%\\
%Setting the Month works exactly like setting the hour. Increasing and decreasing is done via leaning the Watch fowrward an backward. Once finished a double Tap sets the Seconds to 0 and starts the Watch again.
\subsection{Anzeige der heutigen Schritte}
\begin{center}

\end{center}
Um die Schrittanzeige einzuschalten muss die Uhr um etwas 10 Grad nach vorn gekippt werden und im Zeitanzeigemodus doppelt angetippt werden.

\paragraph{Analog}
In der analogen Variante wird die LED für elf Uhr gleichzeitig mit der Überlaufanzeige 0 bis 3 Uhr aktiviert. Die Überlaufanzeige zeigt die Anzahl der vollständigen Umrundung an. Eine vollständige Umrundung besteht aus 15000 Schritten.
Der äußere Ring zeigt die Schritte ohne Überlauf an. Jede LED signalisiert 500 Schritte. Der Wert wird auf 500 Schritte gerundet. Die erste Umschaltung auf die LED die normalerweise für 2 Minuten steht erfolgt also bei 251 Schritten.
In dem Beispiel ist der Überlaufzähler auf 2 und im äußeren Ring brennt die sechste LED (normalerweise 12 Minuten).
$2*15000+6*500 = 33000$
Die Anzeige signalisiert in dem Beispiel also 33000 Schritte am heutigen Tag.
\paragraph{Binary}
In der Binär Variante zeigt die erste Spalte eine 7 an, die rechten drei Spalten Zeigen die Schritte mit einer Auflösung von 100 an.
Die 32768 Schritte in dem Bispiel werden also als (7)328 angezeigt.\\
\\
Doppeltippen während die aktuellen Schritte angezeigt werden führt zurück in den Zeitanzeige Modus, wenn die Uhr nach Oben zeigt.
\subsection{Schritthistorie ansehen}
Um in den Schritthistoriemodus zu kommen muss die Uhr, während die heutigen Schritte angeszeigt werden, nach unten gedreht werden. Anschließend kann mit Doppeltippen die Schritthistorie aktiviert werden.
\begin{center}

\end{center}
Der Historienzähler kann erhöht und verringert werden, indem die Uhr nach vorne oder nach hinten geneigt wird.
\paragraph{Analog} 
Der Schritthistorienmodus ähnelt stark der Schrittzähleranzeige. Der Einzige Unterschied ist die Anzeige des Historienzählers.
Der Historienzähler beginnt bei 4 Uhr und erhöht sich je nachdem, wie lange die zugehörige Schrittanzahl zurückliegt. In dem Beispiel ist die LED für 5 Uhr aktiviert. Damit ist die Anzeige von vor 2 Tagen. Die Schritte werden wie im Schrittzählermodus angezeigt. Die Anzeige im Beispiel zeigt also an, dass der Schrittzähler vor 2 Tagen bei 7500 lag.
\paragraph{Binary}
Die Schritthistorie wird durch die LED H80 signalisiert.
Die LEDs direkt darunter zeigen die History Counter an. Der Counter startet gestern mit 0.
Die Anzeige im Beispiel zeigt also an, dass der Schrittzähler vor 2 Tagen bei 7500 lag.\\
\\
Diese Anzeige kann mit einem Doppeltippen zur Batteriespannungsanzeige verlassen werden.
\subsection{Batteriespannungsanzeige}
Um die Battersiepannungsanzeige zu aktivieren muss im Schritthistoreinmodus ein Doppeltipp erfolgen.
\begin{center}

\end{center}
\paragraph{Analog}
Die Batteriespannungsanzeige wird signalisiert, indem die Stundenanzeige für 11 und 12 Uhr gemeinsam angezeigt wird.
Die Batterispannung wird auf dem äußeren Ring skaliert von 3,5V bis 1,5V angezeigt. Jedes Viertel entspricht also 0,5V.
Die Uhr in dem Beispiel zeigt also 2,95V an.

\paragraph{Binary}
Die Batteriespannungsanzeige wird durch die LED H40 signalisiert.
Die rechten 3 Spalten zeigen die Batteriespannung in 10mV Schritten an.
$2950mV=2,95V$\\
\\
Doppeltippen in diesem Modus führt zurück in den Schrittanzeigemodus.

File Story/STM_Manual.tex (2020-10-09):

\section{STM Version Manual}
\subsection{Read the time}
\begin{center}

\end{center}
To read the Watch it is necessary to activate the Display this can be either done via double tapping the Housing or raising the arm to take a look on the watch(tilt it by a minimum of 12 degrees with the Watchface facing up and holding it steady for about one second)

\paragraph{Analog}
The analog Version an be read equally to a normal Watch. 
In the inner Ring the Hours from 1 to 12 are displayed. 
In the outer Ring the minutes are displayed from 0 to 59, 
since there are only 30 LEDs in the outer ring for uneven minutes the nearest two LEDs are lit up. 
For example for 3:15 the LEDs signalling 14 and 16 are lit up.

\paragraph{Binary}
in the Binary Version the LEDs are read columnwise as BCD code starting with 1 at the bottom. So the right two columns are showing the Minutes. If an LED is litone have to add its Value to the Minutes if not then nothing is added. So for the full hour no led in the right two columns will be lit.
In the example above in the first column no LED is lit. In the second column the LED for 1 and 2 are lit. In the third column the LED for 1 is lit and in the last column the LED for 1 and 4 are lit.
So it is 3:15.
\subsubsection{setting the Time}
To enter the Time setting mode you have to turn the Watch in show time mode upside down, Watchface facing the ground an double Tap it. The Watch enters debouncing mode.
In debouncing mode the Hours 80 and Minutes 80 are blinking for the binary version for the Analog Version Hours 12 and 6 are blinking. (Blinking leds are displayed brighter in the graphic.
\begin{center}

\end{center}
While in debouncing mode turn the watch around again (Watchface facing up)  and double Tap it again to enter Set Hour mode.
\begin{center}

\end{center}
In the set hour mode the hour can be increased by leaning the Watch away from you and decreased by leaning the watch towards you. In the Analog Version the LED signalling 10 Minutes is blinking, when the current hour setting is PM.
Once the hour is set correctly double Tap the Watch again to enter Set Minute Mode.
\begin{center}

\end{center}
The Set hour mode works exactly like to set hour mode. Increasing and decreasing is done via leaning the Watch fowrward an backward. Once finished a double Tap sets the Seconds to 0 and starts the Watch again.
\subsection{Read the Date}
\begin{center}

\end{center}
To enter the Date display mode tilt the Watch in Time Mode to the Front(Facing away from you) at least 10 degrees and double Tap it.
\paragraph{Analog}
On the analog Version The Minutes 40 and 50 are lit up to signal Date Display.
On the Hours Ring the Month is displayed as Hour and the Day is Displayed as Minutes.

\paragraph{Binary}
On the binary Version the first column is showing 3 to signal Date Display.
In the second and third column the Day is displayed as BCD Code and the Month is displayed in binary code(it does not stop on 9)\\
\\
A double Tap with the watch facing up switches back to show time mode.

\subsubsection{setting the Date}
To enter the Date setting mode you have to turn the Watch in show date mode upside down, Watchface facing the ground an double Tap it. The Watch enters debouncing mode.
In debouncing mode the Hours 8 and Minutes 80 are blinking for the binary version for the Analog Version Minutes 40 and 50 are blinking. (Blinking leds are displayed brighter in the graphic.
\begin{center}

\end{center}
While in debouncing mode turn the watch around again (Watchface facing up)  and double Tap it again to enter set day mode.
\begin{center}

\end{center}
Setting the Day works exactly like setting the hour. Increasing and decreasing is done via leaning the Watch fowrward an backward. Once finished a double Tap switches to set month mode.
\begin{center}

\end{center}
Setting the Month works exactly like setting the hour. Increasing and decreasing is done via leaning the Watch fowrward an backward. Once finished a double Tap switches to set year mode.
\begin{center}

\end{center}
The year is only used for the leap year calculation and can be only set between 0 and 99. 
\paragraph{Analog} 
In the Analog Version the Set year mode is signalized by blinking both minute LEDs 30 and 50. The Year tens are shown in the inner ring with one LED per Counter and the ones are shown in the outer ring with one LED per counter. In this example XX21.
\paragraph{Binary}
Setting Year mode is displayed by showing 3 in the first column and blinking all LEDs in the second column. The year is displayed in columns 3 and 4. In this example XX21.\\
\\
Setting the Month works exactly like setting the hour. Increasing and decreasing is done via leaning the Watch fowrward an backward. Once finished a double Tap sets the Seconds to 0 and starts the Watch again.
\subsection{Todays Steps}
\begin{center}

\end{center}
To enter Step display mode tilt the Watch in Time Mode to the Back(Facing you) at least 10 degrees and double Tap it.
\paragraph{Analog}
On the Analog Watch the hour LED 11 is lit up with the overflow counter (from 0(12 o'clock) to 3. The overflow counter counts the number of whole rounds on the Stepcounter. An overflow occurs on 15000. The current Stepcounter without overflow is displayed in the outer Ring. Each LED signalizes 500 Steps. The value is rounded to 500.
In the Example the overflow counter shows 2 and the counter itself shows 6.
$2*15000+6*500 = 33000$
\paragraph{Binary}
On the binary Watch the Step Counter is signalized by the forst column showing 7. Column 2 to 4 shows the steps in 100 counts rounded to 100 counts. So 32768 in the exmample will be shown as (7)328\\
\\
A double Tap with the watch facing up switches back to show time mode.

\subsection{Show steps history}
To enter the steps history mode you have to turn the Watch in show steps mode upside down, Watchface facing the ground an double Tap it.
\begin{center}

\end{center}
The history counter can be increased and decreased by leaning the watch back and forth.
\paragraph{Analog} 
The steps history mode looks like the Show steps mode, but there is an additional LEDas Hitory Counter lit up. The History counter starts at Hour 4 and increases depending on how far ago the Date is. In the Example Hour 5 is shown, so the history is from 2 days ago. The steps are show as in the Show Steps mode, so there were 7500 Steps done two days ago.
\paragraph{Binary}
The steps hitory mode is signalized by the H80 LED. The LEDs below show how long ago the Steps were counted, the counter starts yesterday with 0. so the example shows the Data from 2 Days ago. The steps are displayed as in the show steps mode. so the example shows 7500 Steps 2 days ago.\\
\\
to leave this mode double tap changes to the show Battery Voltage.
\subsection{show battery voltage}
To enter the steps history mode you have to double tap the Watch in show steps history mode.
\begin{center}

\end{center}
\paragraph{Analog}
The show battery voltage is signalized by the Hour 11 and 12 lighting up together. The voltage is shown on the minutes ring, scaled from 3.5V to 1,5V, so each quarter is 0,5V. The Watch in the example is showing 2,95V.

\paragraph{Binary}
The show battery voltage is signalized by the Hour 40 LED. Column 2 to 4 are showing the Battery voltage in 10mV granularity. So the Example shows $2950mV=2,95V$\\
\\
A double Tap with the watch facing up switches back to show steps mode.

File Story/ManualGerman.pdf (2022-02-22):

# Bedienungsanleitung (BCD)WristWatch

## 1 Bedienungsanleitung STM Version

### 1.1 Zeit ablesen

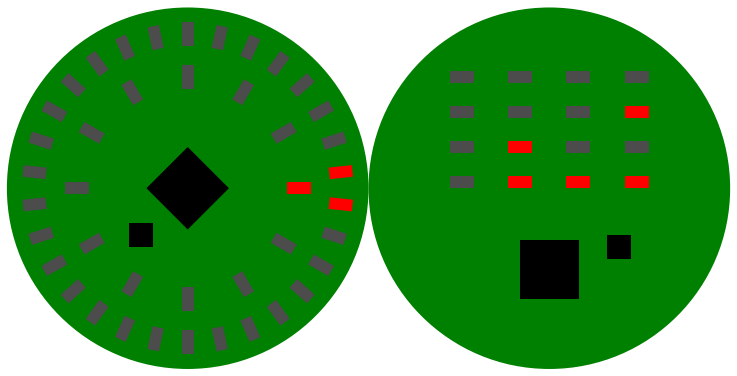
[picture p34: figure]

Um die Uhrzeit abzulesen muss die Anzeige aktiviert werden, das kann entweder durch doppeltes Antippen aktiviert werden, oder durch anheben des Armes um einen Blick auf die Uhr zu werfen (drehen der Uhr um mindestens 12 Grad während die Anzeige nach oben zeigt und anschließendes stillhalten für etwa eine Sekunde)

Analog Die analoge Uhr kann entsprechend einer normalen Analoguhr abgelesen werden. Der innere Ring zeigt die aktuelle Stunde zwischen eins und zwölf an. Der äußere Ring zeigt die Minuten von null bis neunundfünfzig an, da der äußere Ring nur 30 LEDs besitzt werden für ungerade Minuten die LEDs beleuchtet, die der eigentlichen Minutenanzahl am nächsten sind. Für 3:15 Uhr wird z.B. die Stundenanzeige für 3 Uhr aktiviert und die Minutenanzeige für 14 und 16 Minuten, wie auf der Grafik zu sehen.

Binary die Binäre Version wird spaltenweise gelesen. Die Wertigkeit beginnt von unten mit eins, zwei, vier und acht. Die Linken beiden Spalten zeigen die Stundenanzahl die rechten beiden die Minutenanzahl. Wenn eine LED leuchtet muss man deren Wertigkeit zu der Summe hinzuzählen. Zur vollen Stunde werden also alle LEDs in den rechten beiden Spalten aus sein. In dem Beispiel ist in der Stunden Zehnerspalte keine LED aktiviert. In der zweiten Spalte ist LED1 und LED2 beleuchtet, damit ergibt sich 3 als Stundenanzahl. In der dritten Spalte Minuten Zehner brennt LED1, in der vierten Spalte LED1 und LED4, somit ergeben sich 15 Minuten. Insgesamt also 3:15 Uhr

### 1.1.1 Einstellen der Zeit

Um in den Zeiteinstellungsmodus zu starten muss sich die Uhr im Zeitanzeige Modus befinden. Anschließend muss die Uhr mit der ANzeige nach unten doppelt angetippt werden, damit wechselt die Uhr in den Entprellmodus. Im Entprellmodus blinken in der Binärversion die Azeigen für Stunden 80 und Minuten 80. In der analogen Variante blinkt die Anzeige für die Stunden 12 und 6. (Blinkende LEDs werden in der Grafik heller dargestellt)

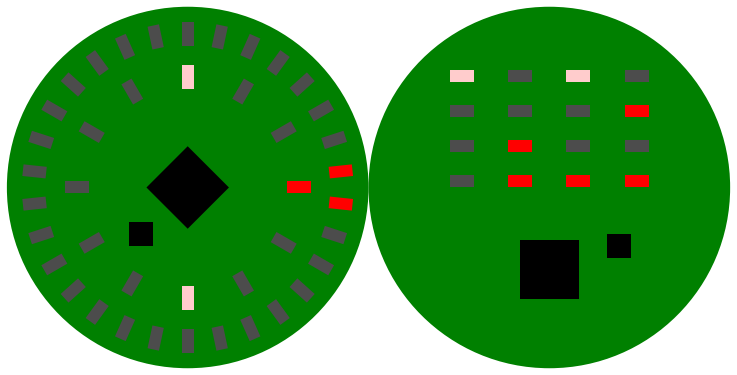
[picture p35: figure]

Im Entprellmodus muss die Anzeige der Uhr wieder nach Oben gedreht werden und doppelt

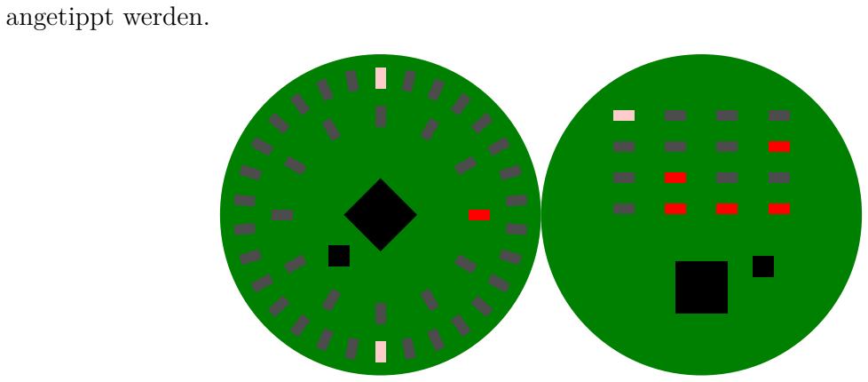
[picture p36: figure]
angetippt werden.

Im Stundeneinstellungsmodus kann die Stundenanzahl durch kippen der Uhr nach Oben (weg vom Benutzer) erhöht und durch kippen nach unten verringert werden. In der analogen Variante blinkt die LED, die normalerweise 10 Minuten anzeigt, wenn die eingestellte Stundenanzahl nach 12 Uhr mittags liegt. Sobald die Stundenanzahl korrekt eingestellt ist kann durch doppel-

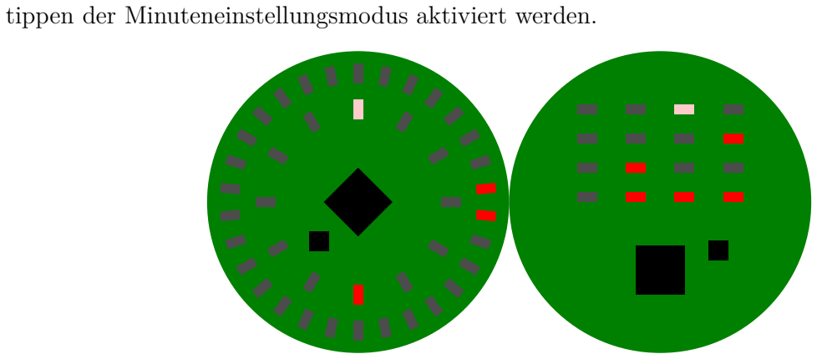
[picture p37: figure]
tippen der Minuteneinstellungsmodus aktiviert werden.

der Minuteneinstellungsmodus funktioniert genau wie der Stundeneinstellungsmodus, erhöhen und verringern der Minutenanzahl kann duch kippen der Uhr erreicht werden. Wenn die Minutenanzahl richtig eingestellt ist kann der Einstellungsmodus mit doppeltippen verlassen werden. Beim Verlassen des Einstellungsmodus werden die Sekunden auf null gestellt und die Uhr beginn wieder zu laufen.

### 1.2 Anzeige der heutigen Schritte

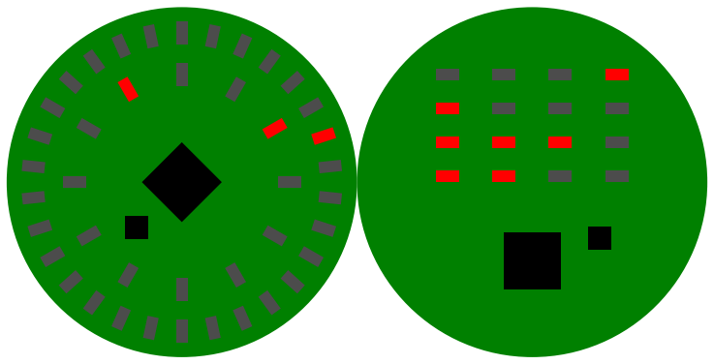
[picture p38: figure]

Um die Schrittanzeige einzuschalten muss die Uhr um etwas 10 Grad nach vorn gekippt werden und im Zeitanzeigemodus doppelt angetippt werden.

Analog In der analogen Variante wird die LED für elf Uhr gleichzeitig mit der Überlaufanzeige 0 bis 3 Uhr aktiviert. Die Überlaufanzeige zeigt die Anzahl der vollständigen Umrundung an. Eine vollständige Umrundung besteht aus 15000 Schritten. Der äußere Ring zeigt die Schritte ohne Überlauf an. Jede LED signalisiert 500 Schritte. Der Wert wird auf 500 Schritte gerundet. Die erste Umschaltung auf die LED die normalerweise für 2 Minuten steht erfolgt also bei 251 Schritten. In dem Beispiel ist der Überlaufzähler auf 2 und im äußeren Ring brennt die sechste LED (normalerweise 12 Minuten). 2 ∗ 15000 + 6 ∗ 500 = 33000 Die Anzeige signalisiert in dem Beispiel also 33000 Schritte am heutigen Tag.

Binary In der Binär Variante zeigt die erste Spalte eine 7 an, die rechten drei Spalten Zeigen die Schritte mit einer Auflösung von 100 an. Die 32768 Schritte in dem Bispiel werden also als (7)328 angezeigt.

Doppeltippen während die aktuellen Schritte angezeigt werden führt zurück in den Zeitanzeige Modus, wenn die Uhr nach Oben zeigt.

### 1.3 Schritthistorie ansehen

Um in den Schritthistoriemodus zu kommen muss die Uhr, während die heutigen Schritte angeszeigt werden, nach unten gedreht werden. Anschließend kann mit Doppeltippen die Schrit-

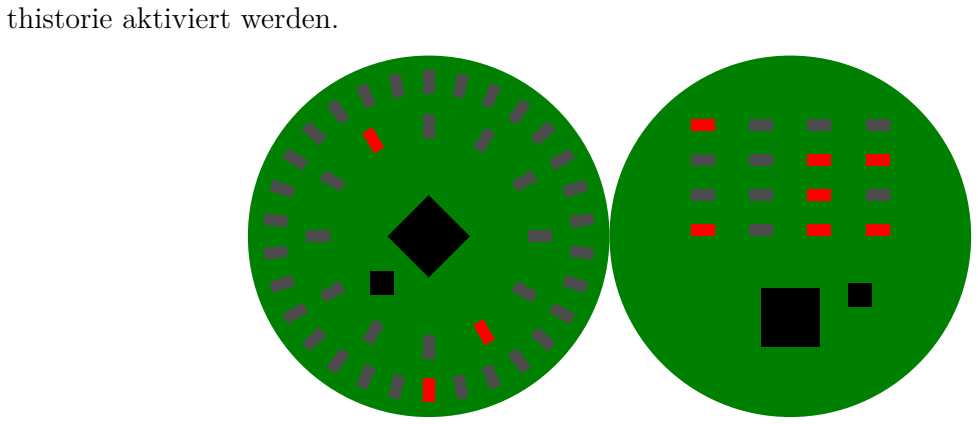
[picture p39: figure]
thistorie aktiviert werden.

Der Historienzähler kann erhöht und verringert werden, indem die Uhr nach vorne oder nach hinten geneigt wird.

Analog Der Schritthistorienmodus ähnelt stark der Schrittzähleranzeige. Der Einzige Unterschied ist die Anzeige des Historienzählers. Der Historienzähler beginnt bei 4 Uhr und erhöht sich je nachdem, wie lange die zugehörige Schrittanzahl zurückliegt. In dem Beispiel ist die LED für 5 Uhr aktiviert. Damit ist die Anzeige von vor 2 Tagen. Die Schritte werden wie im Schrittzählermodus angezeigt. Die Anzeige im Beispiel zeigt also an, dass der Schrittzähler vor 2 Tagen bei 7500 lag.

Binary Die Schritthistorie wird durch die LED H80 signalisiert. Die LEDs direkt darunter zeigen die History Counter an. Der Counter startet gestern mit 0. Die Anzeige im Beispiel zeigt also an, dass der Schrittzähler vor 2 Tagen bei 7500 lag.

Diese Anzeige kann mit einem Doppeltippen zur Batteriespannungsanzeige verlassen werden.

### 1.4 Batteriespannungsanzeige

Um die Battersiepannungsanzeige zu aktivieren muss im Schritthistoreinmodus ein Doppeltipp erfolgen.

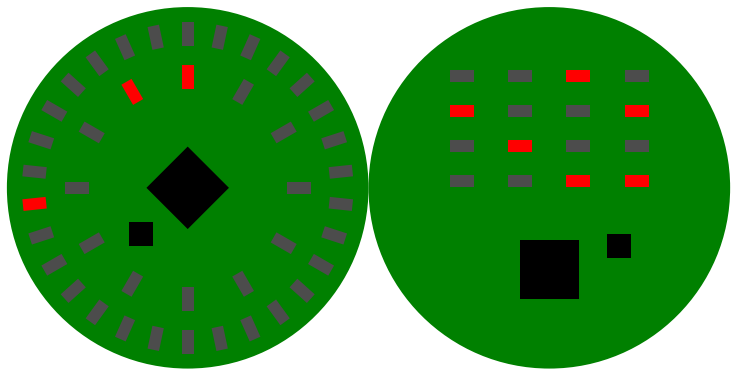
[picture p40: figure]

Analog Die Batteriespannungsanzeige wird signalisiert, indem die Stundenanzeige für 11 und 12 Uhr gemeinsam angezeigt wird. Die Batterispannung wird auf dem äußeren Ring skaliert von 3,5V bis 1,5V angezeigt. Jedes Viertel entspricht also 0,5V. Die Uhr in dem Beispiel zeigt also 2,95V an.

Binary Die Batteriespannungsanzeige wird durch die LED H40 signalisiert. Die rechten 3 Spalten zeigen die Batteriespannung in 10mV Schritten an. 2950mV = 2, 95V

Doppeltippen in diesem Modus führt zurück in den Schrittanzeigemodus.

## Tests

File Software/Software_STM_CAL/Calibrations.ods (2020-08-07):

PCB | Voltage [V] | Capacitance [pF] | CALP | CALM | Resulting Corr
1 | 3,3 | 10 | 1 | 303 | 209
1 | 2,8 | 10 | 1 | 302 | 210
1 | 2,8 | 3,9 | 0 | 92 | -92
1 | 3,3 | 3,9 | 0 | 99 | -99

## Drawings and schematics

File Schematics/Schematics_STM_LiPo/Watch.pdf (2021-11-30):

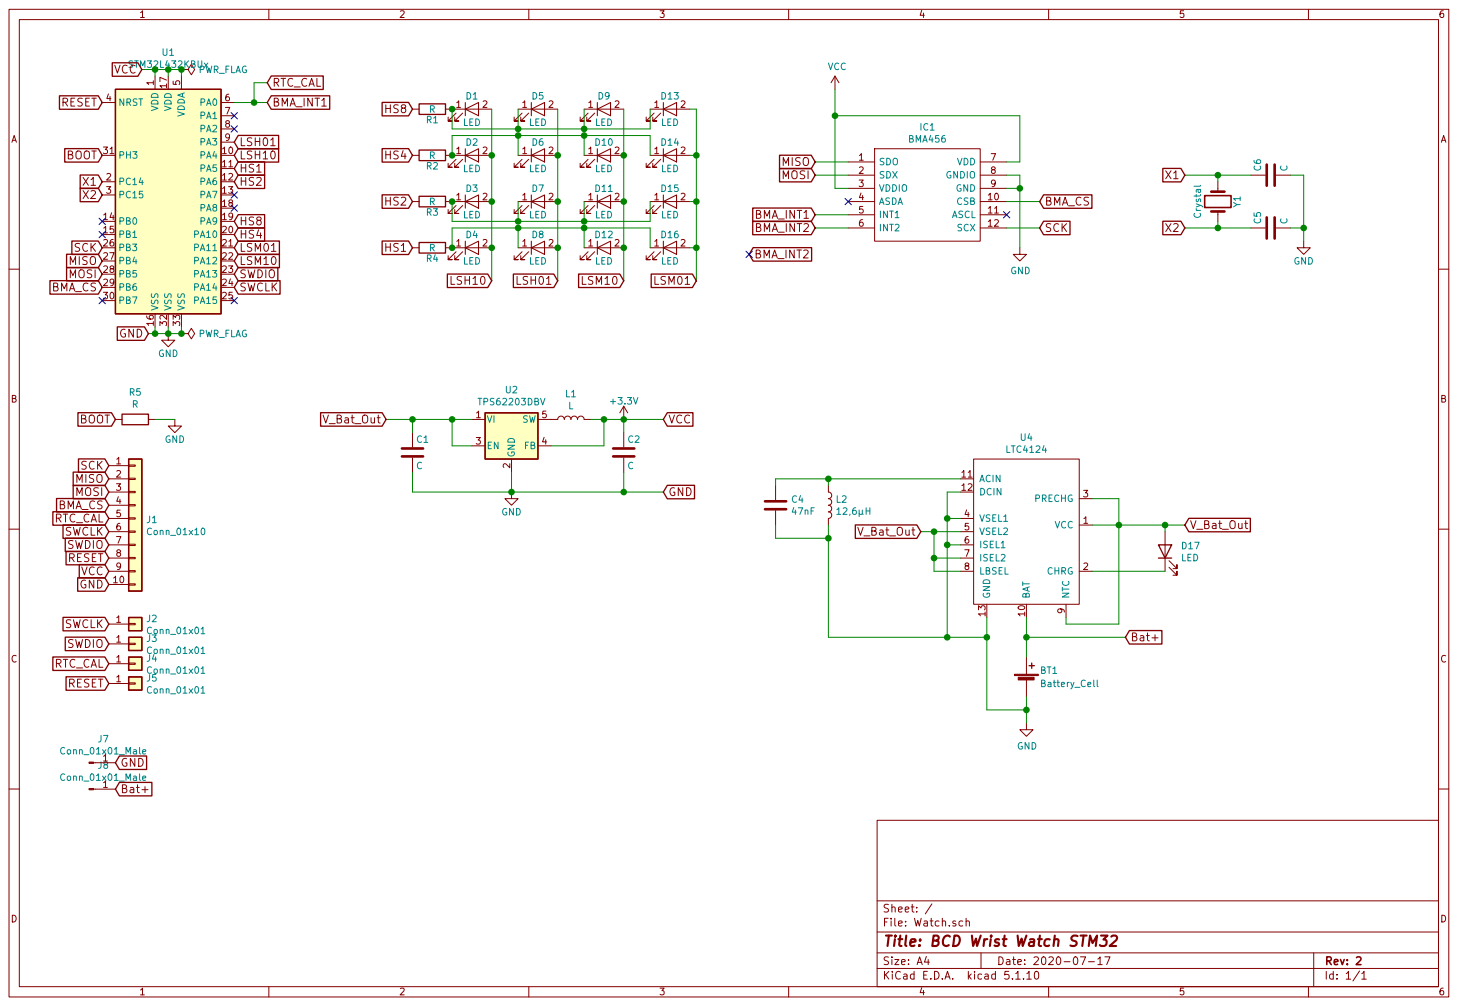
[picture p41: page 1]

Id: 1/1 Title: BCD Wrist Watch STM32

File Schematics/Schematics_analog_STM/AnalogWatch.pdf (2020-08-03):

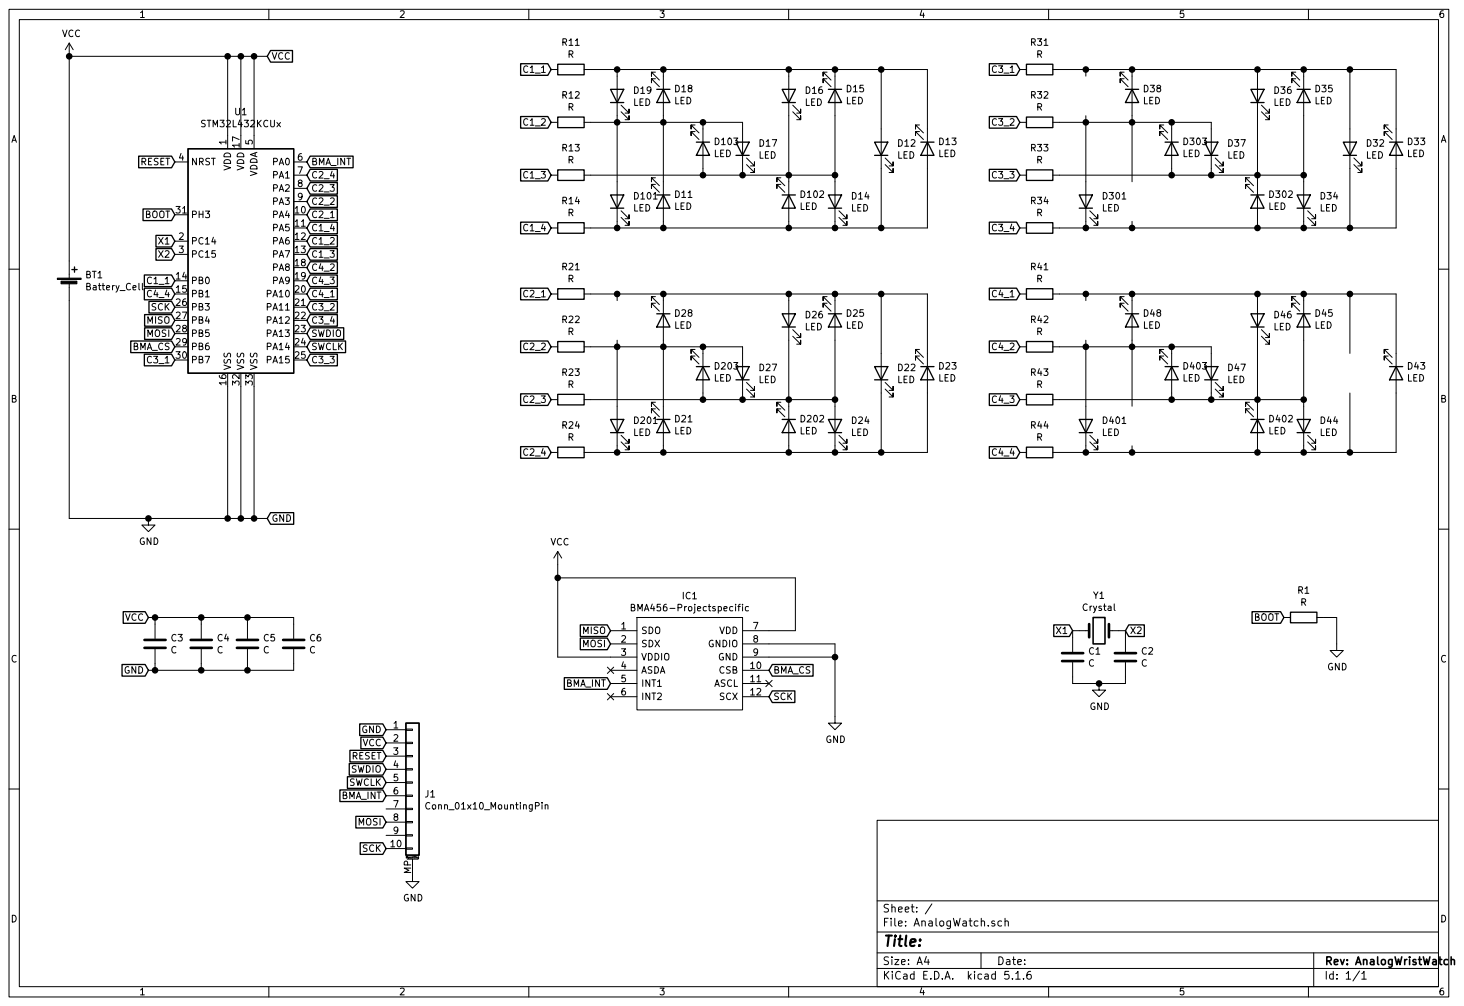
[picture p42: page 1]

5 VSS 16 VSS 32 VSS 33 U1 STM32L432KCUx SDO 1 CSB 10 ASCL 11 SCX 12 SDX 2 VDDIO 3 ASDA 4

File: AnalogWatch.sch Sheet: /
Id: 1/1 Title:

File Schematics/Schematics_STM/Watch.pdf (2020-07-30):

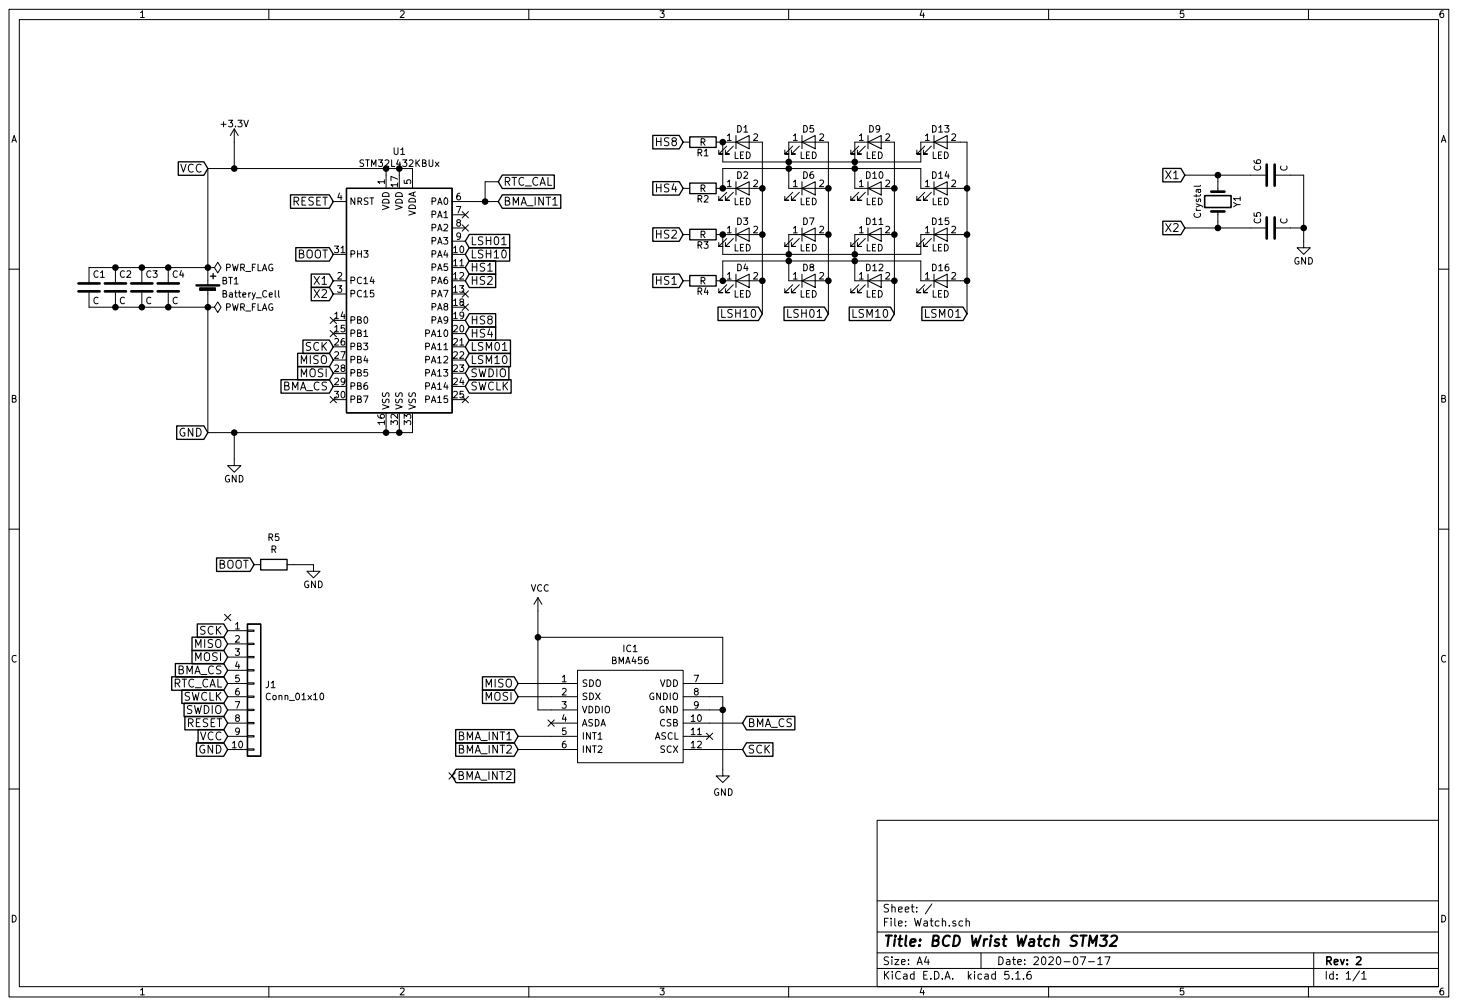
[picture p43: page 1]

File: Watch.sch Sheet: / GND GND GND

Id: 1/1 Title: BCD Wrist Watch STM32

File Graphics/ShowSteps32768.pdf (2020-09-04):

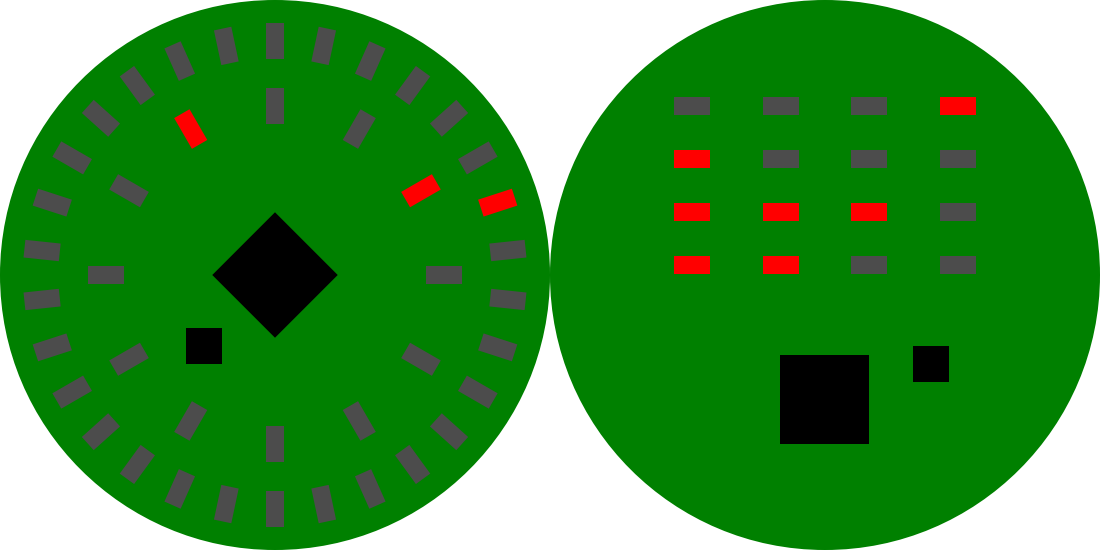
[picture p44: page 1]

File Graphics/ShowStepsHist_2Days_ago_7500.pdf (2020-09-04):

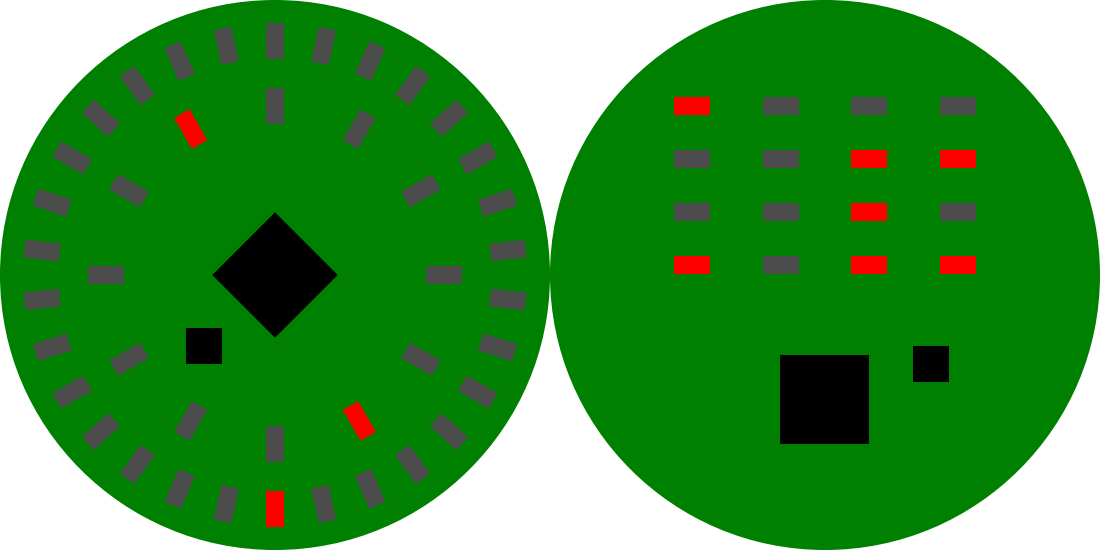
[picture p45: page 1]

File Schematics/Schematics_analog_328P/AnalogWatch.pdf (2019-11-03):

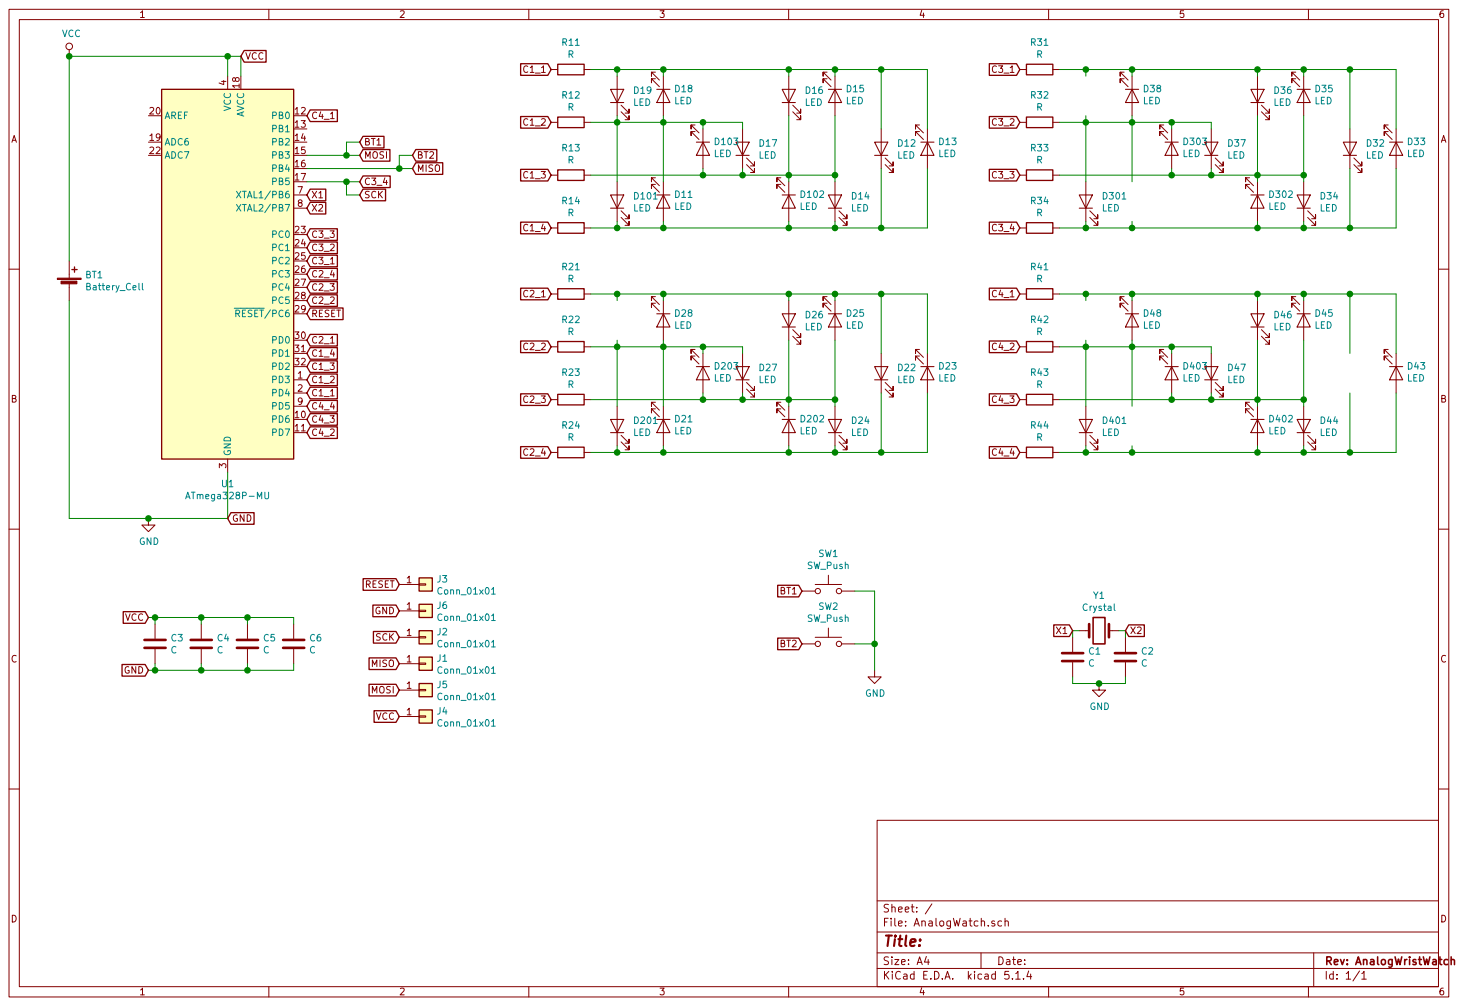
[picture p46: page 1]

File: AnalogWatch.sch Sheet: /
Id: 1/1 Title:

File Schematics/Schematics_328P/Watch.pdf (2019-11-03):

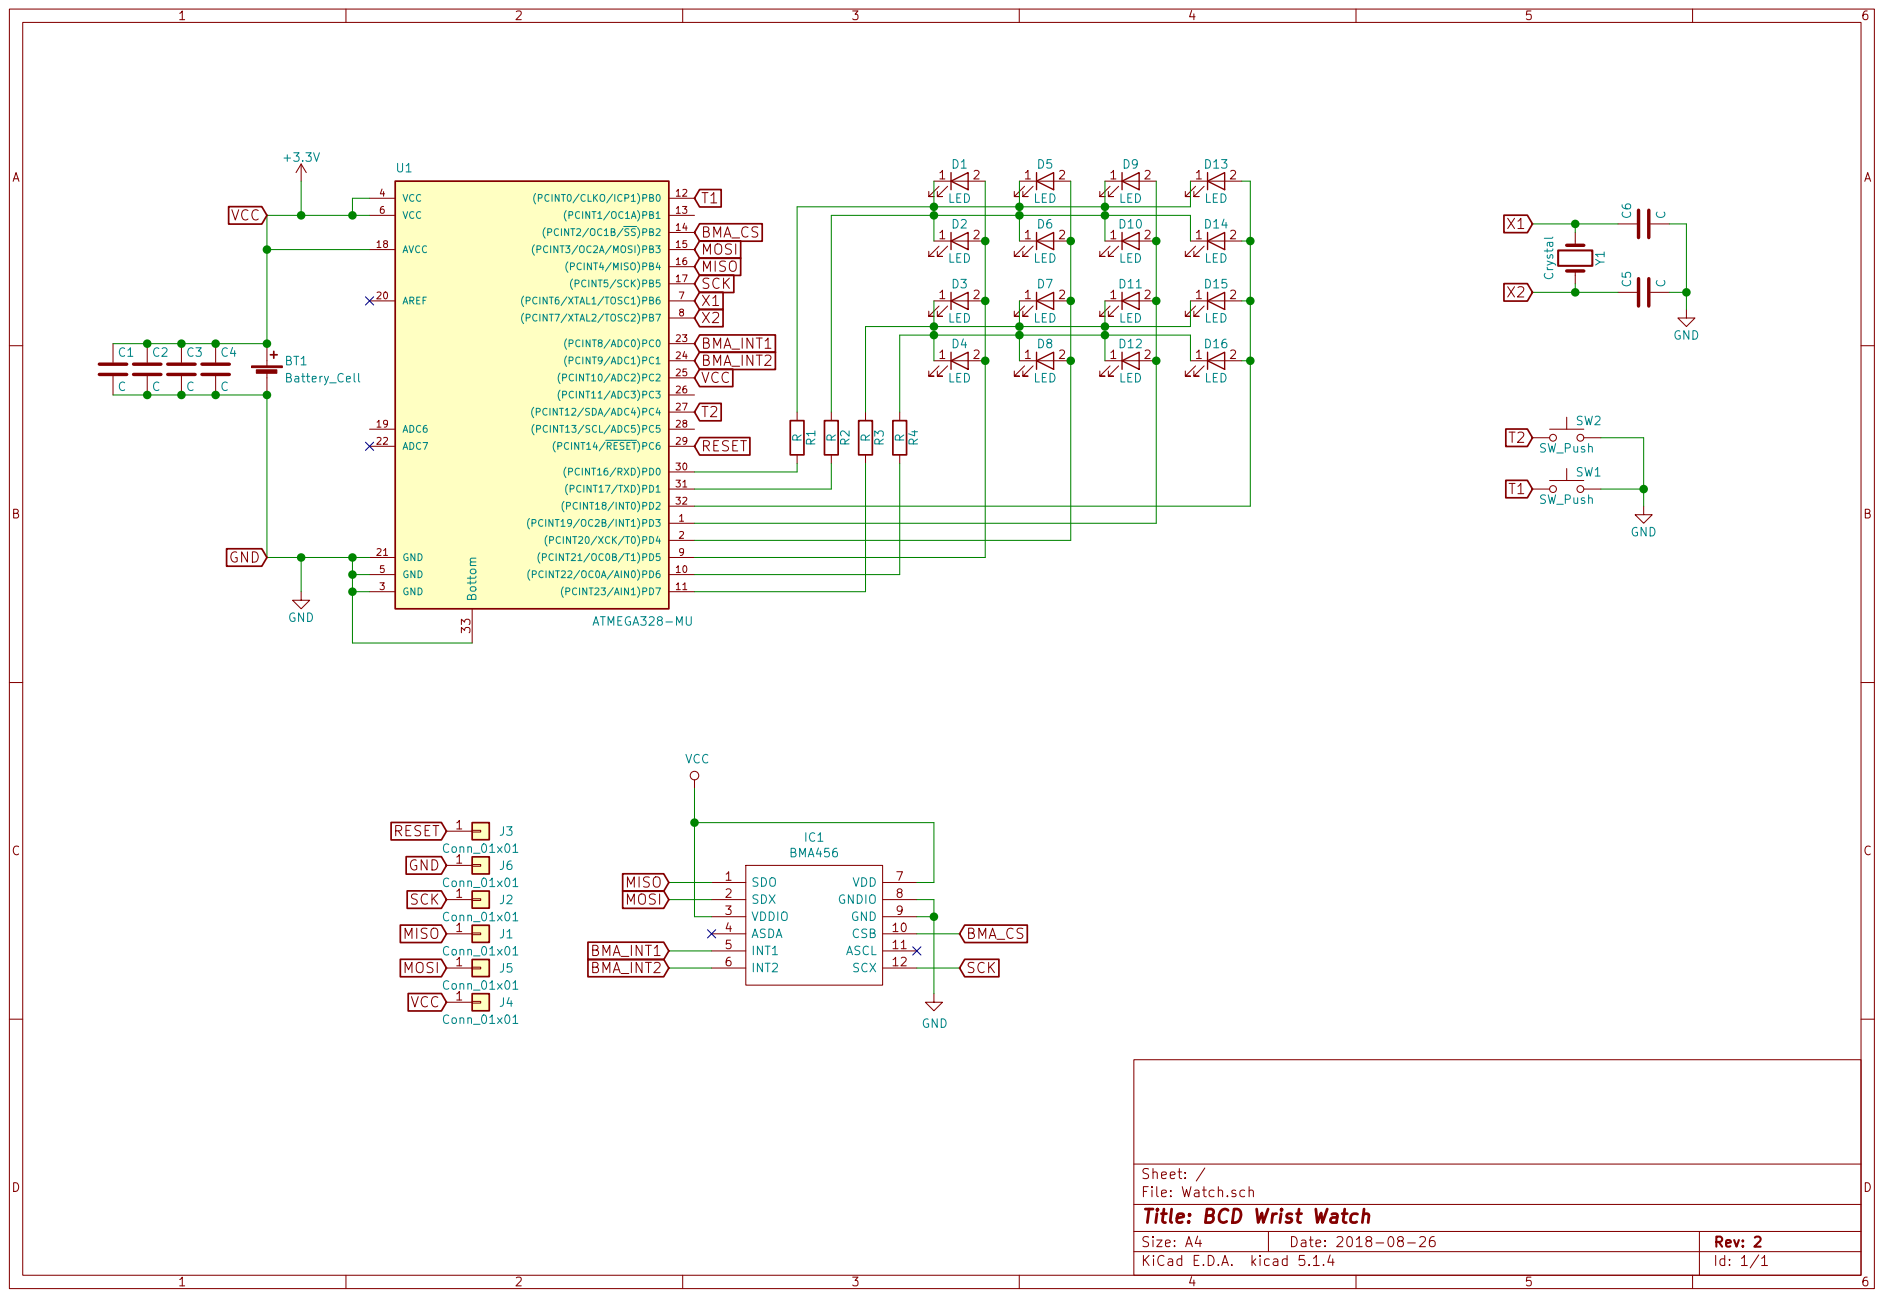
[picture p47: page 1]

Id: 1/1 Title: BCD Wrist Watch

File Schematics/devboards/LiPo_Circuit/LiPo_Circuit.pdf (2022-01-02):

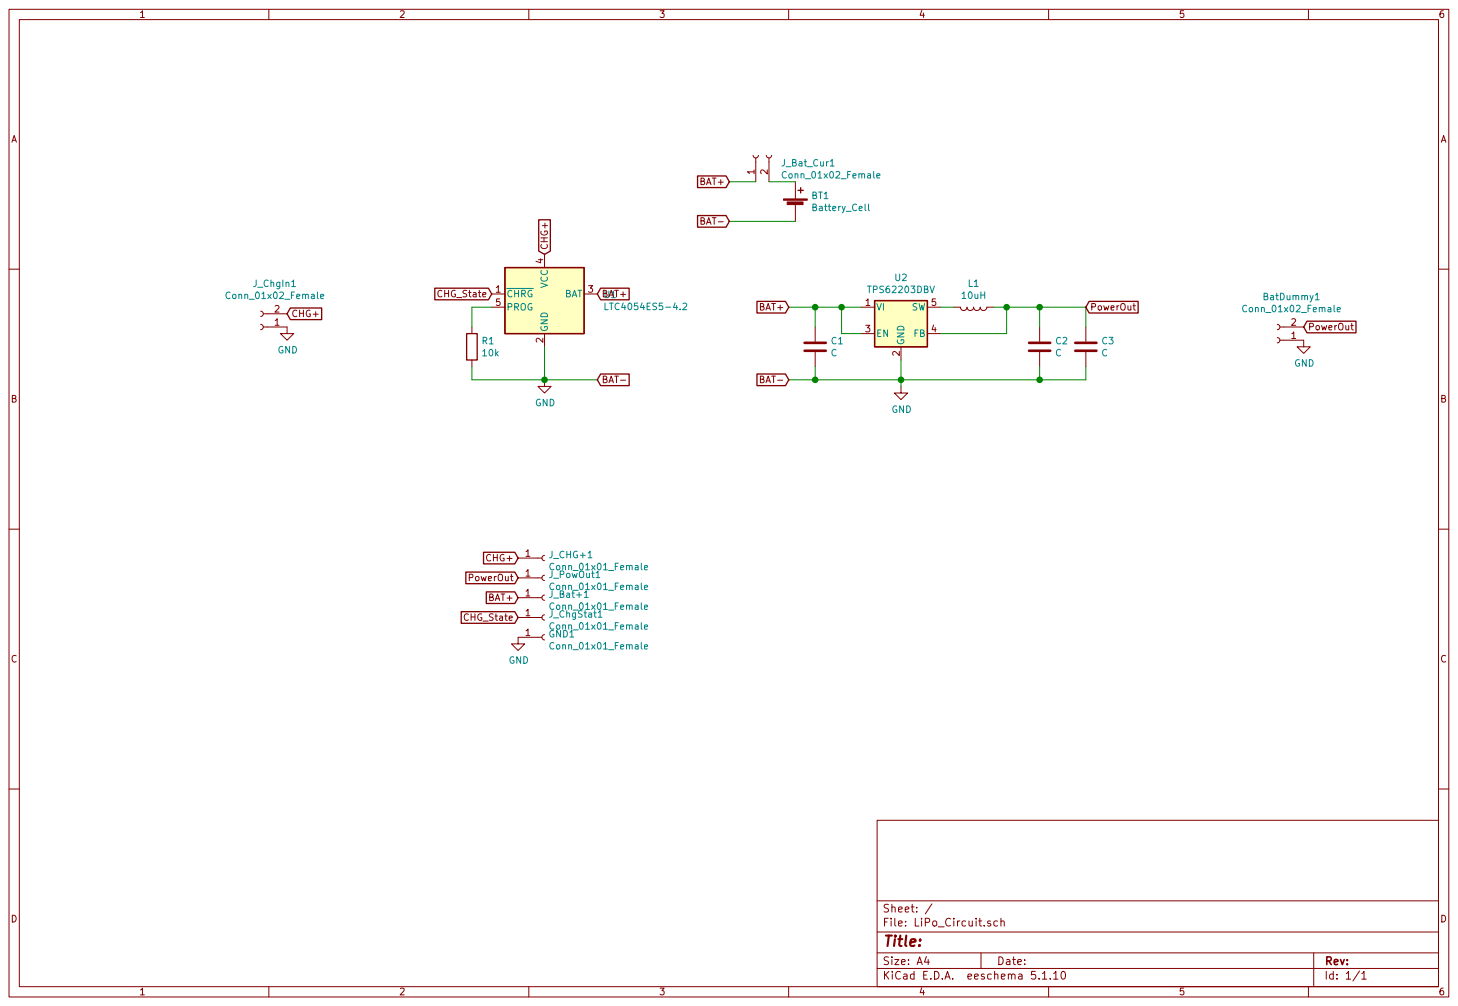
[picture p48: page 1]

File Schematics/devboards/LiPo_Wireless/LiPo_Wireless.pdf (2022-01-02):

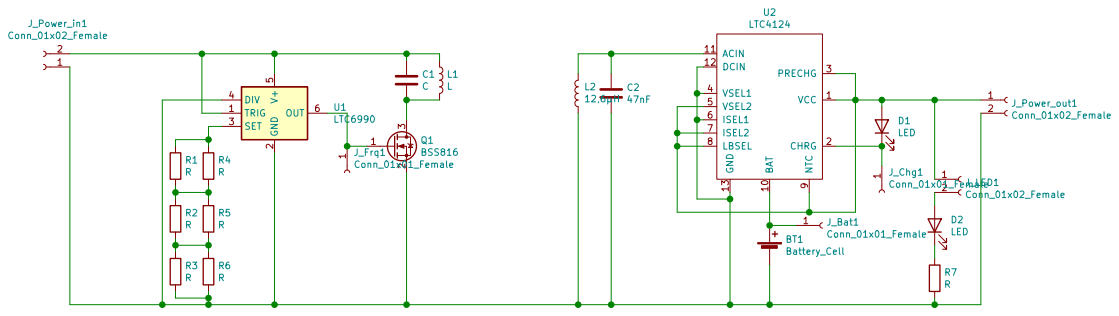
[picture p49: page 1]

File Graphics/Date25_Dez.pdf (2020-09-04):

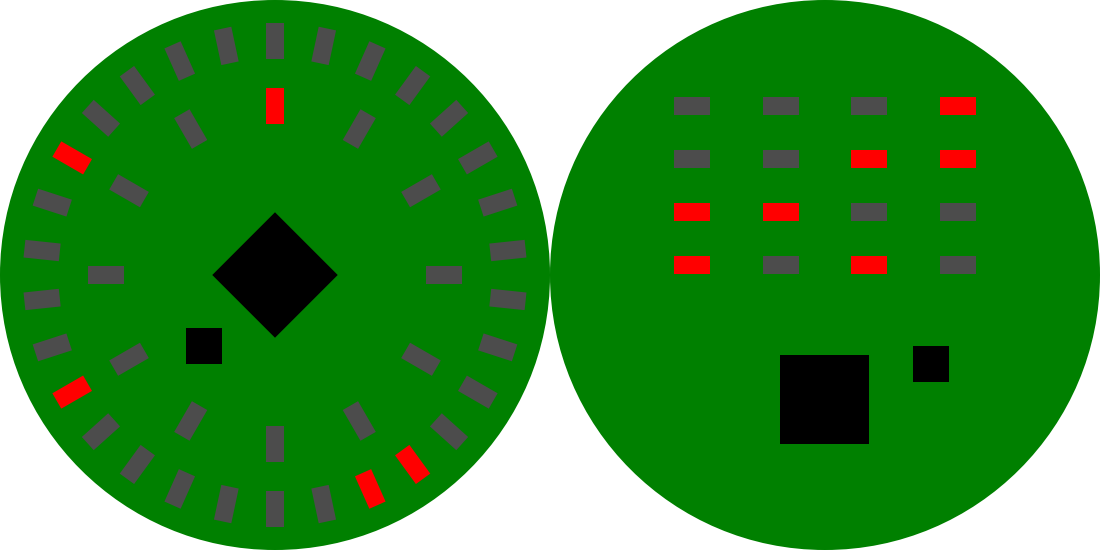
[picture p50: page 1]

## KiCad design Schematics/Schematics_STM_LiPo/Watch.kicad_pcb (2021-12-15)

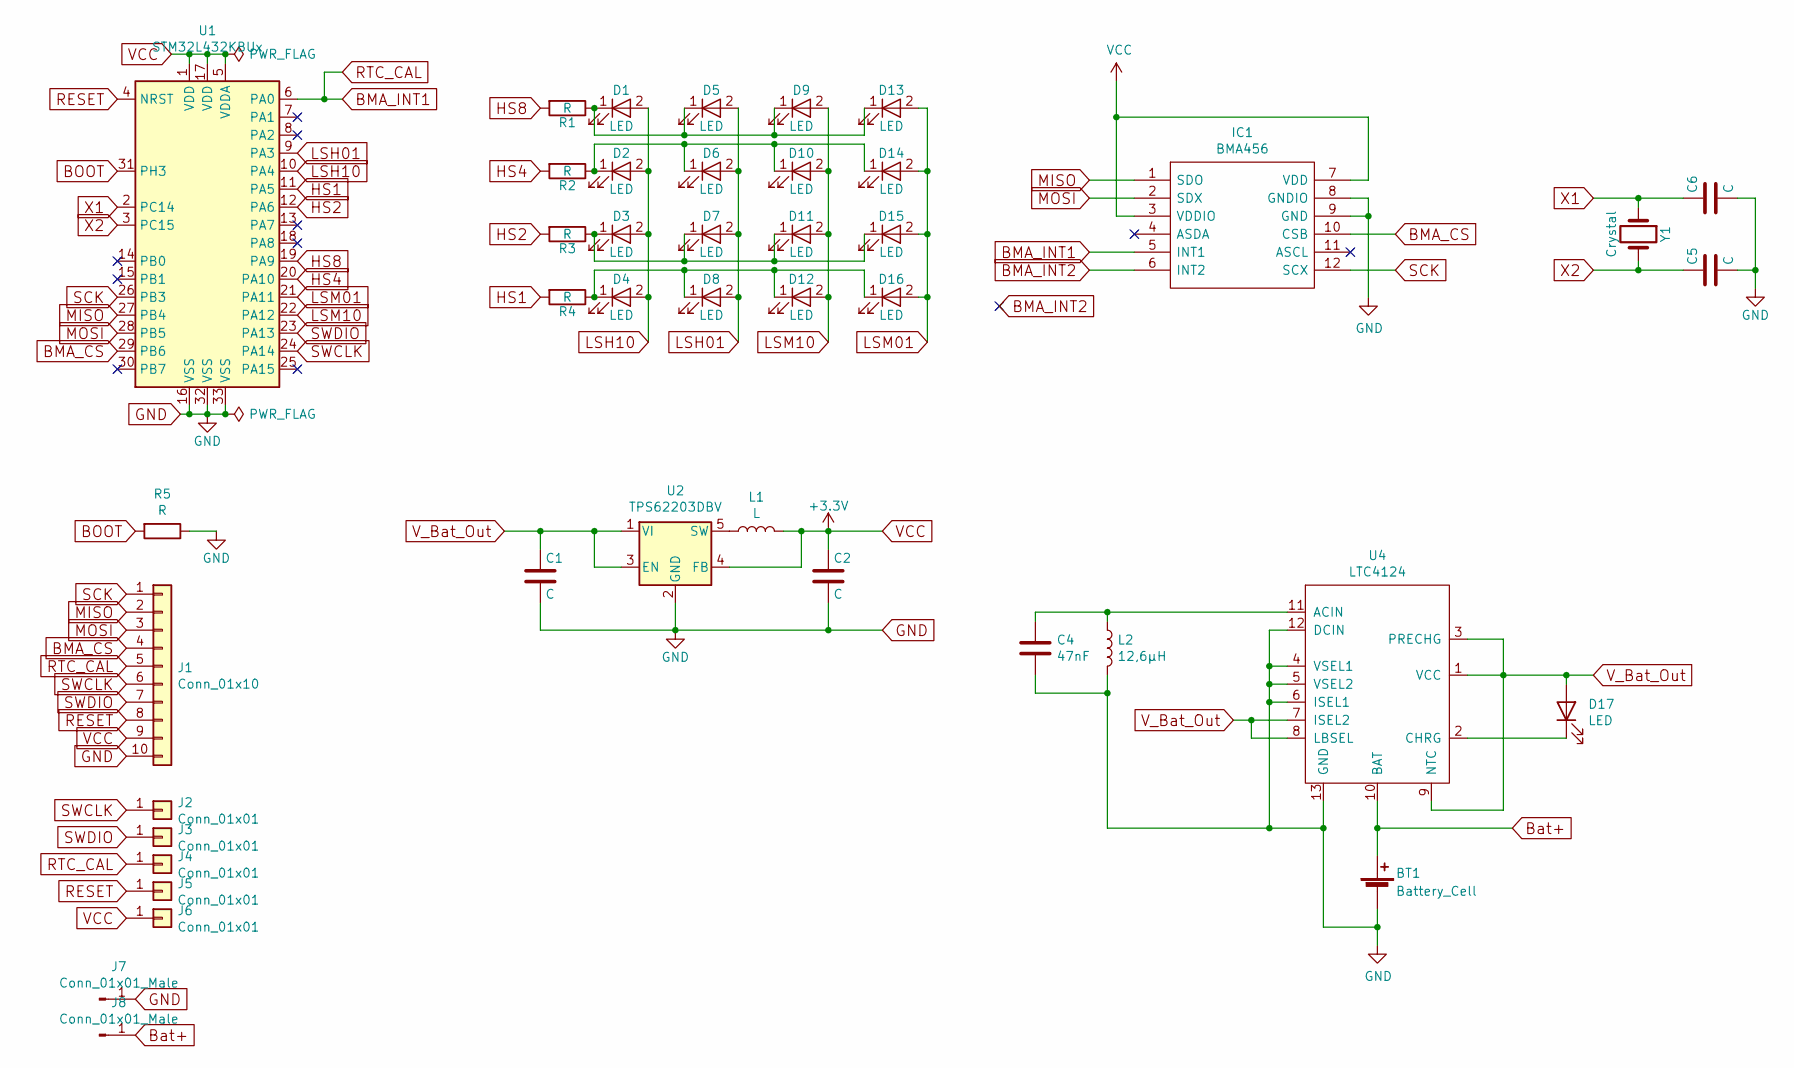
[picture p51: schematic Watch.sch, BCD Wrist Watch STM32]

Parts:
BT1: Battery_Cell; solderPad_small
C1, C2, C5, C6: C; C_0603_HandSoldering
C4: 47nF; C_0603_1608Metric_Pad1.08x0.95mm_HandSolder
D1, D2, D3, D4, D5, D6, D7, D8, D9, D10, D11, D12, D13, D14, D15, D16: LED; LED_0603
D17: LED; LED_0603_1608Metric
IC1: BMA456; Mouser Part Number 262-BMA456
J1: Conn_01x10; TE_1-1734839-0_1x10-1MP_P0.5mm_Horizontal
J2, J3, J4, J5, J6: Conn_01x01; TestPoint
J7, J8: Conn_01x01_Male; SolderPad
L1: L; L_0603_1608Metric_Pad1.05x0.95mm_HandSolder
L2: 12,6µH; solderPad_small
R1, R2, R3, R4: R; R_0603
R5: R; R_0603_1608Metric
U1: STM32L432KBUx; QFN-32-1EP_5x5mm_P0.5mm_EP3.65x3.65mm
U2: TPS62203DBV; SOT-23-5
U4: LTC4124; Analog_LQFN12_LTC4124
Y1: Crystal; Crystal_SMD_2012-2pin_2.0x1.2mm_HandSoldering

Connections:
BMA_CS: IC1.10 (CSB), J1.4, U1.29 (PB6)
BMA_INT1: IC1.5 (INT1), J1.5, J4.1, U1.6 (PA0)
BMA_INT2: IC1.6 (INT2)
BOOT: R5.2, U1.31 (PH3)
Bat+: BT1.1 (+), J8.1, U4.10 (BAT)
GND: BT1.2 (-), C1.2, C2.2, C4.2, C5.2, C6.2, IC1.8 (GNDIO), IC1.9 (GND), J1.10, J7.1, L2.2, R5.1, U1.16 (VSS), U1.32 (VSS), U1.33 (VSS), U2.2 (GND), U4.4 (VSEL1), U4.5 (VSEL2), U4.6 (ISEL1), U4.12 (DCIN), U4.13 (GND)
HS1: R4.2, U1.11 (PA5)
HS2: R3.2, U1.12 (PA6)
HS4: R2.2, U1.20 (PA10)
HS8: R1.2, U1.19 (PA9)
LSH01: D5.2 (A), D6.2 (A), D7.2 (A), D8.2 (A), U1.9 (PA3)
LSH10: D1.2 (A), D2.2 (A), D3.2 (A), D4.2 (A), U1.10 (PA4)
LSM01: D13.2 (A), D14.2 (A), D15.2 (A), D16.2 (A), U1.21 (PA11)
LSM10: D9.2 (A), D10.2 (A), D11.2 (A), D12.2 (A), U1.22 (PA12)
MISO: IC1.1 (SDO), J1.2, U1.27 (PB4)
MOSI: IC1.2 (SDX), J1.3, U1.28 (PB5)
unnamed: C4.1, L2.1, U4.11 (ACIN)
unnamed: D1.1 (K), D5.1 (K), D9.1 (K), D13.1 (K), R1.1
unnamed: D2.1 (K), D6.1 (K), D10.1 (K), D14.1 (K), R2.1
unnamed: D3.1 (K), D7.1 (K), D11.1 (K), D15.1 (K), R3.1
unnamed: D4.1 (K), D8.1 (K), D12.1 (K), D16.1 (K), R4.1
unnamed: D17.1 (K), U4.2 (CHRG)
unnamed: L1.1, U2.5 (SW)
RESET: J1.8, J5.1, U1.4 (NRST)
SCK: IC1.12 (SCX), J1.1, U1.26 (PB3)
SWCLK: J1.6, J2.1, U1.24 (PA14)
SWDIO: J1.7, J3.1, U1.23 (PA13)
VCC: C2.1, IC1.3 (VDDIO), IC1.7 (VDD), J1.9, J6.1, L1.2, U1.1 (VDD), U1.5 (VDDA), U1.17 (VDD), U2.4 (FB)
V_Bat_Out: C1.1, D17.2 (A), U2.1 (VI), U2.3 (EN), U4.1 (VCC), U4.3 (PRECHG), U4.7 (ISEL2), U4.8 (LBSEL), U4.9 (NTC)
X1: C6.1, U1.2 (PC14), Y1.1
X2: C5.1, U1.3 (PC15), Y1.2

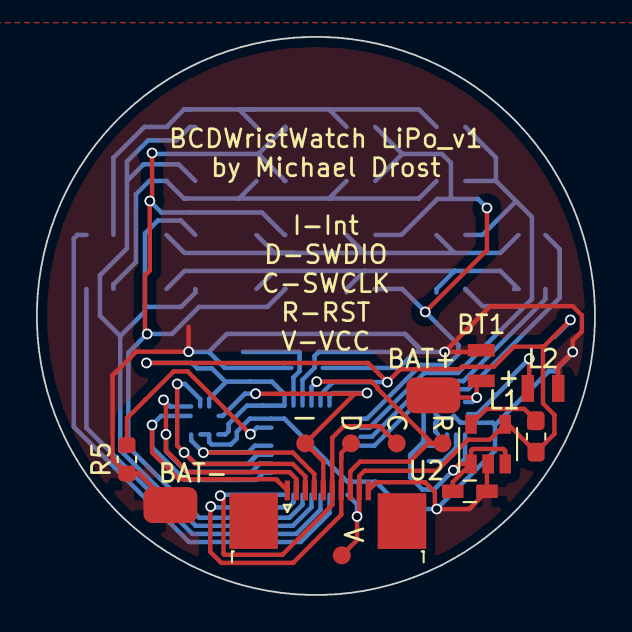
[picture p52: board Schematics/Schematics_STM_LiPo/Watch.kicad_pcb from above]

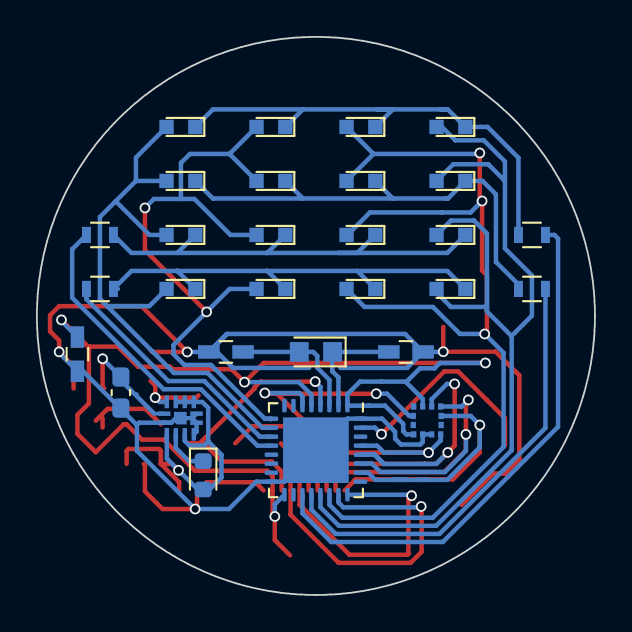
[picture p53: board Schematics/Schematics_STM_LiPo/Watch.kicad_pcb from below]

Board: 2 copper layers, 31.0 x 31.0 mm, 43 parts (29 on the bottom side), 30 nets.

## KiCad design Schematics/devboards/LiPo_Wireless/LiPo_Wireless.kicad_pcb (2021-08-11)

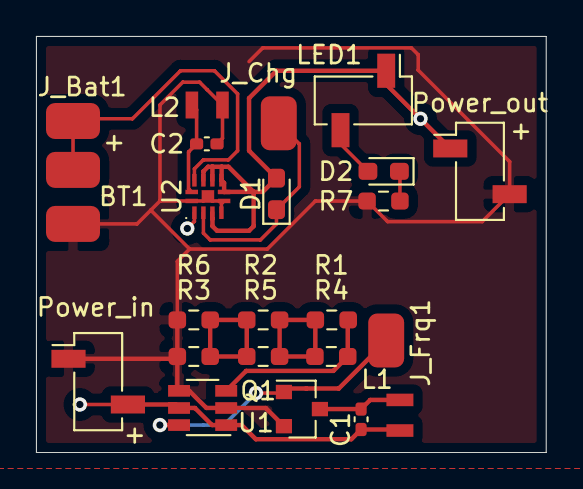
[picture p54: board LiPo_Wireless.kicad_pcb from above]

Board: 2 copper layers, 28.3 x 23.1 mm, 23 parts (0 on the bottom side), 13 nets.

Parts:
BT1: Battery_Cell; SolderPad_2Pin
C1: C; C_0402_1005Metric_Pad0.74x0.62mm_HandSolder
C2: 47nF; C_0402_1005Metric_Pad0.74x0.62mm_HandSolder
D1, D2: LED; D_0603_1608Metric_Pad1.05x0.95mm_HandSolder
J_Bat1: Conn_01x01_Female; SolderPad
J_Chg: Conn_01x01_Female; SolderPad
J_Frq1: Conn_01x01_Female; SolderPad
L1: L; solderPad_small
L2: 12,6µH; solderPad_small
LED1: Conn_01x02_Female; PinSocket_1x02_P2.54mm_Vertical_SMD_Pin1Left
Power_in: Conn_01x02_Female; PinSocket_1x02_P2.54mm_Vertical_SMD_Pin1Left
Power_out: Conn_01x02_Female; PinSocket_1x02_P2.54mm_Vertical_SMD_Pin1Left
Q1: BSS816; SOT-23
R1, R2, R3, R4, R5, R6, R7: R; R_0603_1608Metric_Pad0.98x0.95mm_HandSolder
U1: LTC6990; TSOT-23-6
U2: LTC4124; Analog_LQFN12_LTC4124

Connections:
unnamed: BT1.1, J_Bat1.1, U2.10
unnamed: BT1.2, C2.2, L2.1, Power_in.1, Power_out.2, Q1.2, R3.2, R6.2, R7.2, U1.2, U1.4, U2.4, U2.6, U2.12, U2.13
unnamed: C1.1, L1.1, Power_in.2, U1.1, U1.5
unnamed: C1.2, L1.2, Q1.3
unnamed: C2.1, L2.2, U2.11
unnamed: D1.1, J_Chg.1, U2.2
unnamed: D1.2, LED1.1, Power_out.1, U2.1, U2.3, U2.5, U2.7, U2.8, U2.9
unnamed: D2.1, R7.1
unnamed: D2.2, LED1.2
unnamed: J_Frq1.1, Q1.1, U1.6
unnamed: R1.1, R4.1, U1.3
unnamed: R1.2, R2.1, R4.2, R5.1
unnamed: R2.2, R3.1, R5.2, R6.1

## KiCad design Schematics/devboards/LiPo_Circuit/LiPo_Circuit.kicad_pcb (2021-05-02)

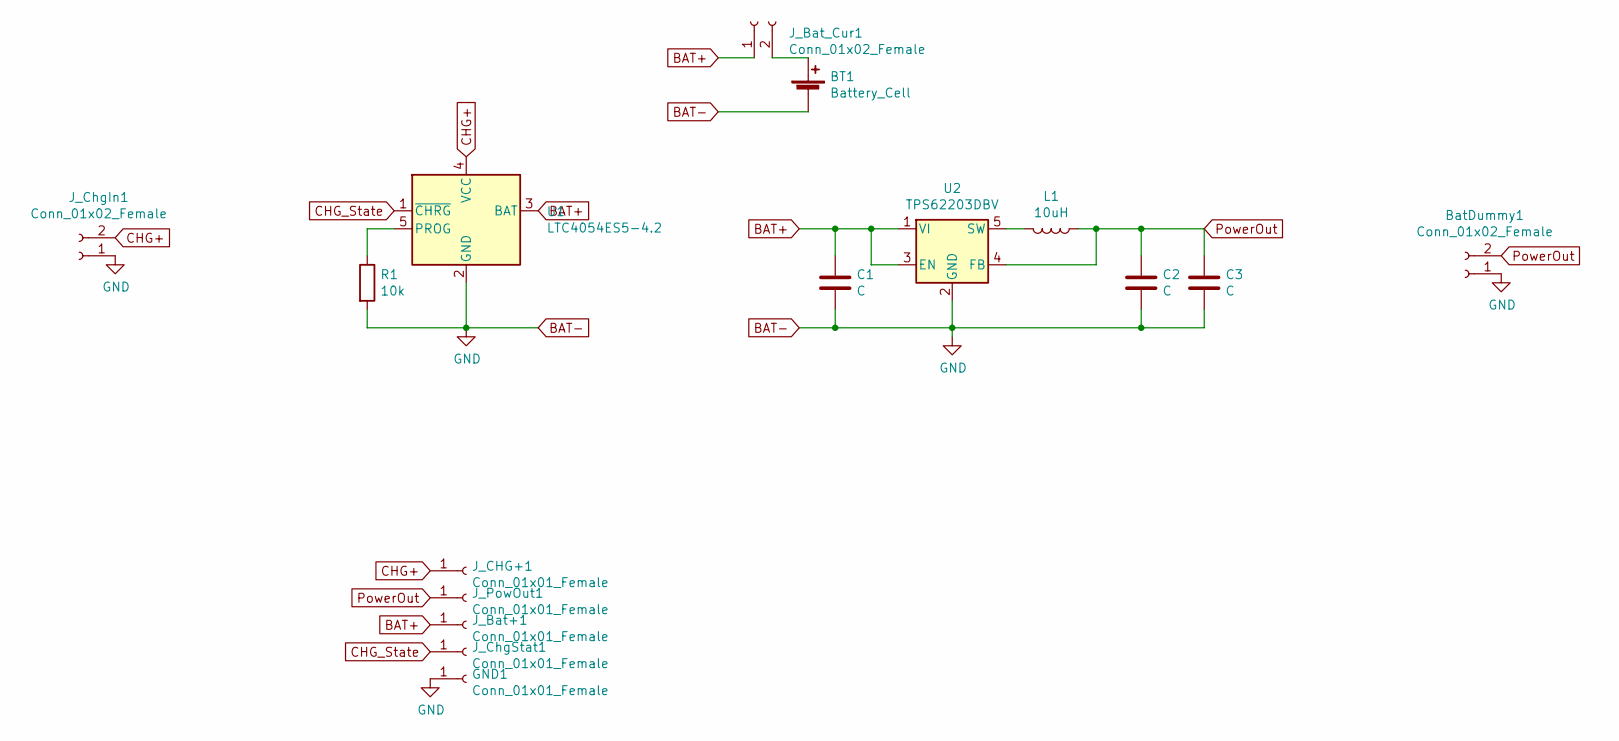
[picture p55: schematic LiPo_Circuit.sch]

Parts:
BT1: Battery_Cell; SolderPad_2Pin
BatDummy1: Conn_01x02_Female; CR2032_Dummy
C1, C2, C3: C; C_0603_1608Metric_Pad1.08x0.95mm_HandSolder
GND1: Conn_01x01_Female; SolderPad
J_Bat+1: Conn_01x01_Female; SolderPad
J_Bat_Cur1: Conn_01x02_Female; PinHeader_1x02_P2.54mm_Vertical
J_CHG+1: Conn_01x01_Female; SolderPad
J_ChgIn1: Conn_01x02_Female; PinHeader_1x02_P2.54mm_Vertical
J_ChgStat1: Conn_01x01_Female; SolderPad
J_PowOut1: Conn_01x01_Female; SolderPad
L1: 10uH; L_0603_1608Metric_Pad1.05x0.95mm_HandSolder
R1: 10k; R_0603_1608Metric_Pad0.98x0.95mm_HandSolder
U1: LTC4054ES5-4.2; TSOT-23-5
U2: TPS62203DBV; SOT-23-5

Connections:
BAT+: C1.1, J_Bat+1.1, J_Bat_Cur1.1, U1.3 (BAT), U2.1 (VI), U2.3 (EN)
BAT-: BT1.2 (-), BatDummy1.1, C1.2, C2.2, C3.2, GND1.1, J_ChgIn1.1, R1.2, U1.2 (GND), U2.2 (GND)
CHG+: J_CHG+1.1, J_ChgIn1.2, U1.4 (VCC)
CHG_State: J_ChgStat1.1, U1.1 (~CHRG)
unnamed: BT1.1 (+), J_Bat_Cur1.2
unnamed: L1.2, U2.5 (SW)
unnamed: R1.1, U1.5 (PROG)
PowerOut: BatDummy1.2, C2.1, C3.1, J_PowOut1.1, L1.1, U2.4 (FB)

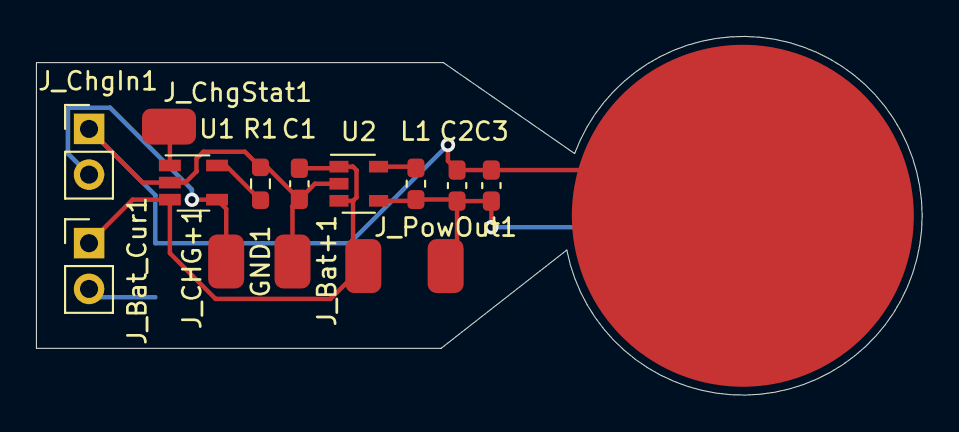
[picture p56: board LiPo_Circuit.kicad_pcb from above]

Board: 2 copper layers, 49.2 x 19.9 mm, 16 parts (1 on the bottom side), 8 nets.

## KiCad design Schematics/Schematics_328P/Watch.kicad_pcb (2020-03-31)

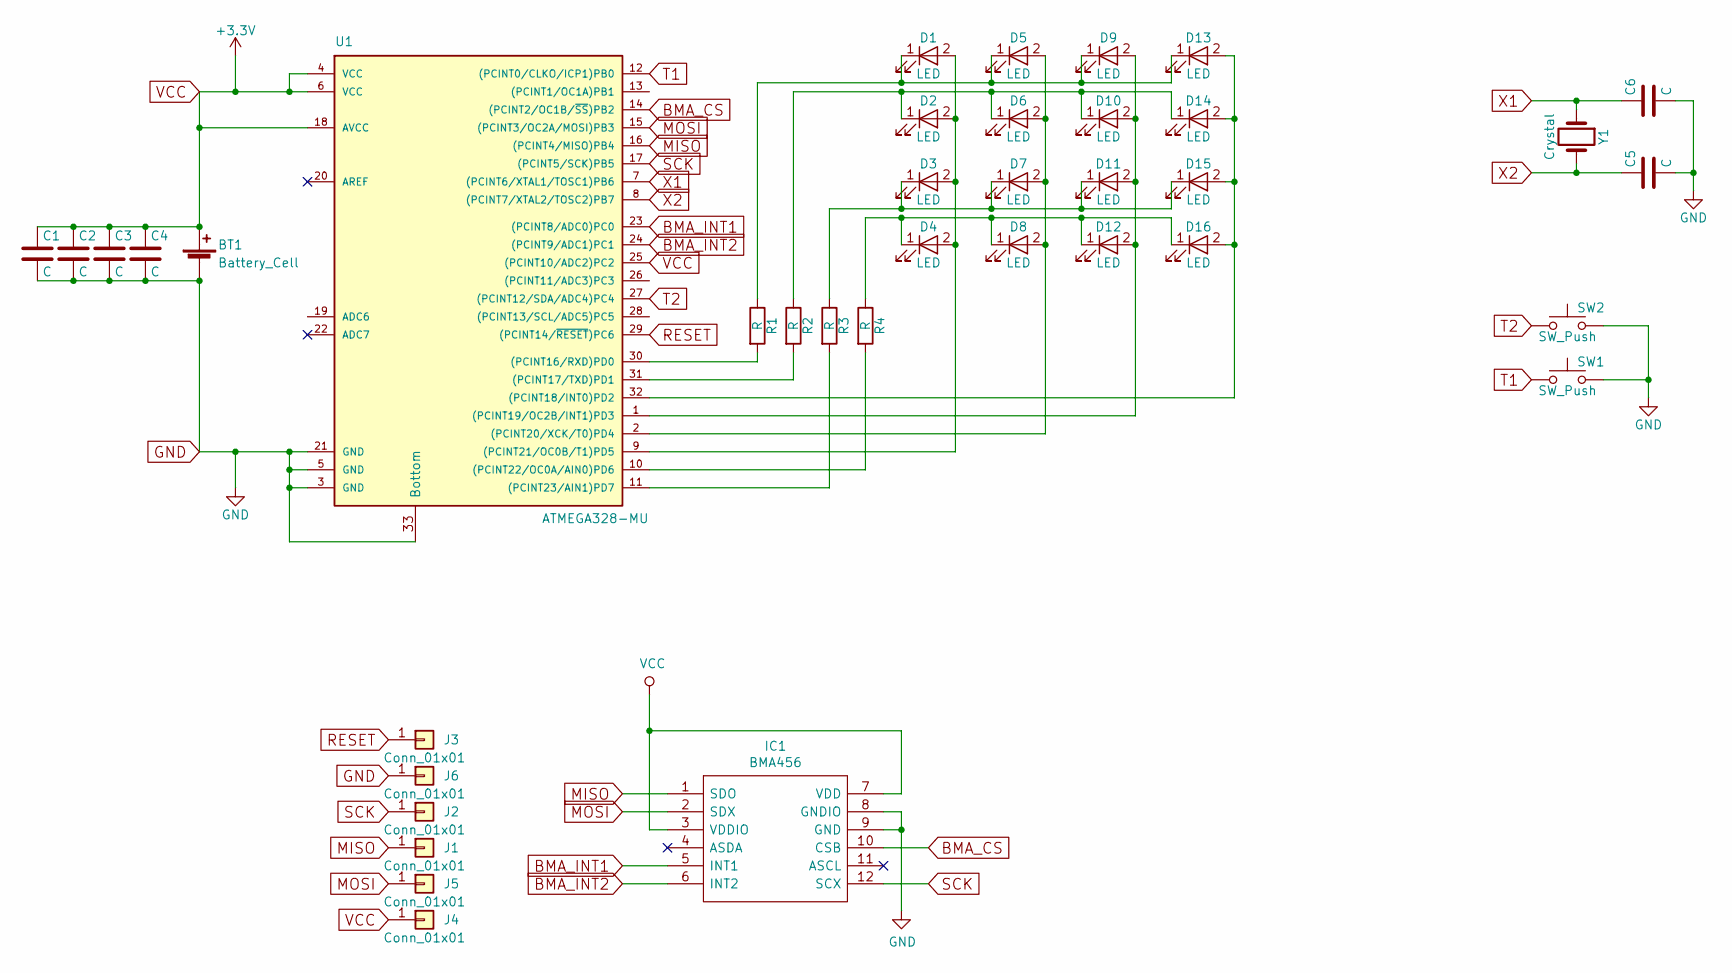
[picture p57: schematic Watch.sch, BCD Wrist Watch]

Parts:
BT1: Battery_Cell; BatteryHolderCR2032
C1, C2, C3, C4, C5, C6: C; C_0603_HandSoldering
D1, D2, D3, D4, D5, D6, D7, D8, D9, D10, D11, D12, D13, D14, D15, D16: LED; LED_0603
IC1: BMA456; Mouser Part Number 262-BMA456
J1, J2, J3, J4, J5, J6: Conn_01x01; TestPoint
R1, R2, R3, R4: R; R_0603
SW1, SW2: SW_Push; Panasonic_EVQPUJ_EVQPUA
U1: ATMEGA328-MU; QFN-32-1EP_5x5mm_Pitch0.5mm
Y1: Crystal; Crystal_SMD_2012-2pin_2.0x1.2mm_HandSoldering

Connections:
BMA_CS: IC1.10 (CSB), U1.14 ((PCINT2/OC1B/~SS~)PB2)
BMA_INT1: IC1.5 (INT1), U1.23 ((PCINT8/ADC0)PC0)
BMA_INT2: IC1.6 (INT2), U1.24 ((PCINT9/ADC1)PC1)
GND: BT1.2 (-), C1.2, C2.2, C3.2, C4.2, C5.2, C6.2, IC1.8 (GNDIO), IC1.9 (GND), J6.1, SW1.2, SW2.2, U1.3 (GND), U1.5 (GND), U1.21 (GND), U1.33 (Bottom); also elsewhere on the board
MISO: IC1.1 (SDO), J1.1, U1.16 ((PCINT4/MISO)PB4)
MOSI: IC1.2 (SDX), J5.1, U1.15 ((PCINT3/OC2A/MOSI)PB3)
unnamed: D1.1 (K), D5.1 (K), D9.1 (K), D13.1 (K), R1.1
unnamed: D1.2 (A), D2.2 (A), D3.2 (A), D4.2 (A), U1.9 ((PCINT21/OC0B/T1)PD5)
unnamed: D5.2 (A), D6.2 (A), D7.2 (A), D8.2 (A), U1.2 ((PCINT20/XCK/T0)PD4)
unnamed: D2.1 (K), D6.1 (K), D10.1 (K), D14.1 (K), R2.1
unnamed: D9.2 (A), D10.2 (A), D11.2 (A), D12.2 (A), U1.1 ((PCINT19/OC2B/INT1)PD3)
unnamed: D3.1 (K), D7.1 (K), D11.1 (K), D15.1 (K), R3.1
unnamed: D4.1 (K), D8.1 (K), D12.1 (K), D16.1 (K), R4.1
unnamed: D13.2 (A), D14.2 (A), D15.2 (A), D16.2 (A), U1.32 ((PCINT18/INT0)PD2)
unnamed: R1.2, U1.30 ((PCINT16/RXD)PD0)
unnamed: R2.2, U1.31 ((PCINT17/TXD)PD1)
unnamed: R3.2, U1.11 ((PCINT23/AIN1)PD7)
unnamed: R4.2, U1.10 ((PCINT22/OC0A/AIN0)PD6)
RESET: J3.1, U1.29 ((PCINT14/~RESET~)PC6)
SCK: IC1.12 (SCX), J2.1, U1.17 ((PCINT5/SCK)PB5)
T1: SW1.1, U1.12 ((PCINT0/CLKO/ICP1)PB0)
T2: SW2.1, U1.27 ((PCINT12/SDA/ADC4)PC4)
VCC: BT1.1 (+), C1.1, C2.1, C3.1, C4.1, IC1.3 (VDDIO), IC1.7 (VDD), J4.1, U1.4 (VCC), U1.6 (VCC), U1.18 (AVCC), U1.25 ((PCINT10/ADC2)PC2)
X1: C6.1, U1.7 ((PCINT6/XTAL1/TOSC1)PB6), Y1.1
X2: C5.1, U1.8 ((PCINT7/XTAL2/TOSC2)PB7), Y1.2

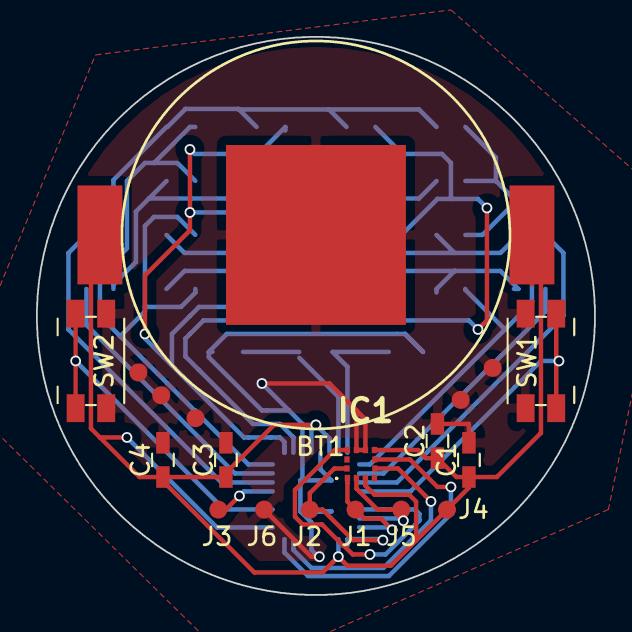
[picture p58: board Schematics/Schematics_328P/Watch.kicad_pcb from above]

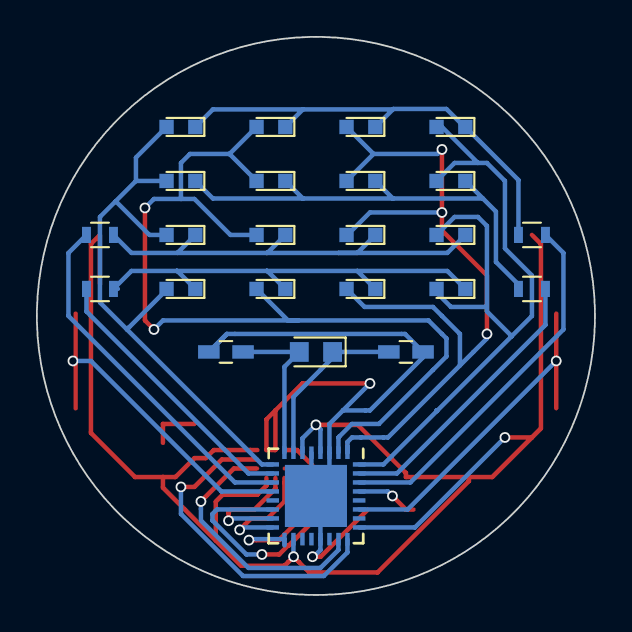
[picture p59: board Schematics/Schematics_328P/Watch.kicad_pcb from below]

Board: 2 copper layers, 31.0 x 31.0 mm, 43 parts (24 on the bottom side), 25 nets.

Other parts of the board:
GP: TestPoint
GP#2, GP#3, GP#4, GP#5: TestPoint

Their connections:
GND: GP.1, GP#2.1, GP#3.1, GP#4.1, GP#5.1; also elsewhere on the board

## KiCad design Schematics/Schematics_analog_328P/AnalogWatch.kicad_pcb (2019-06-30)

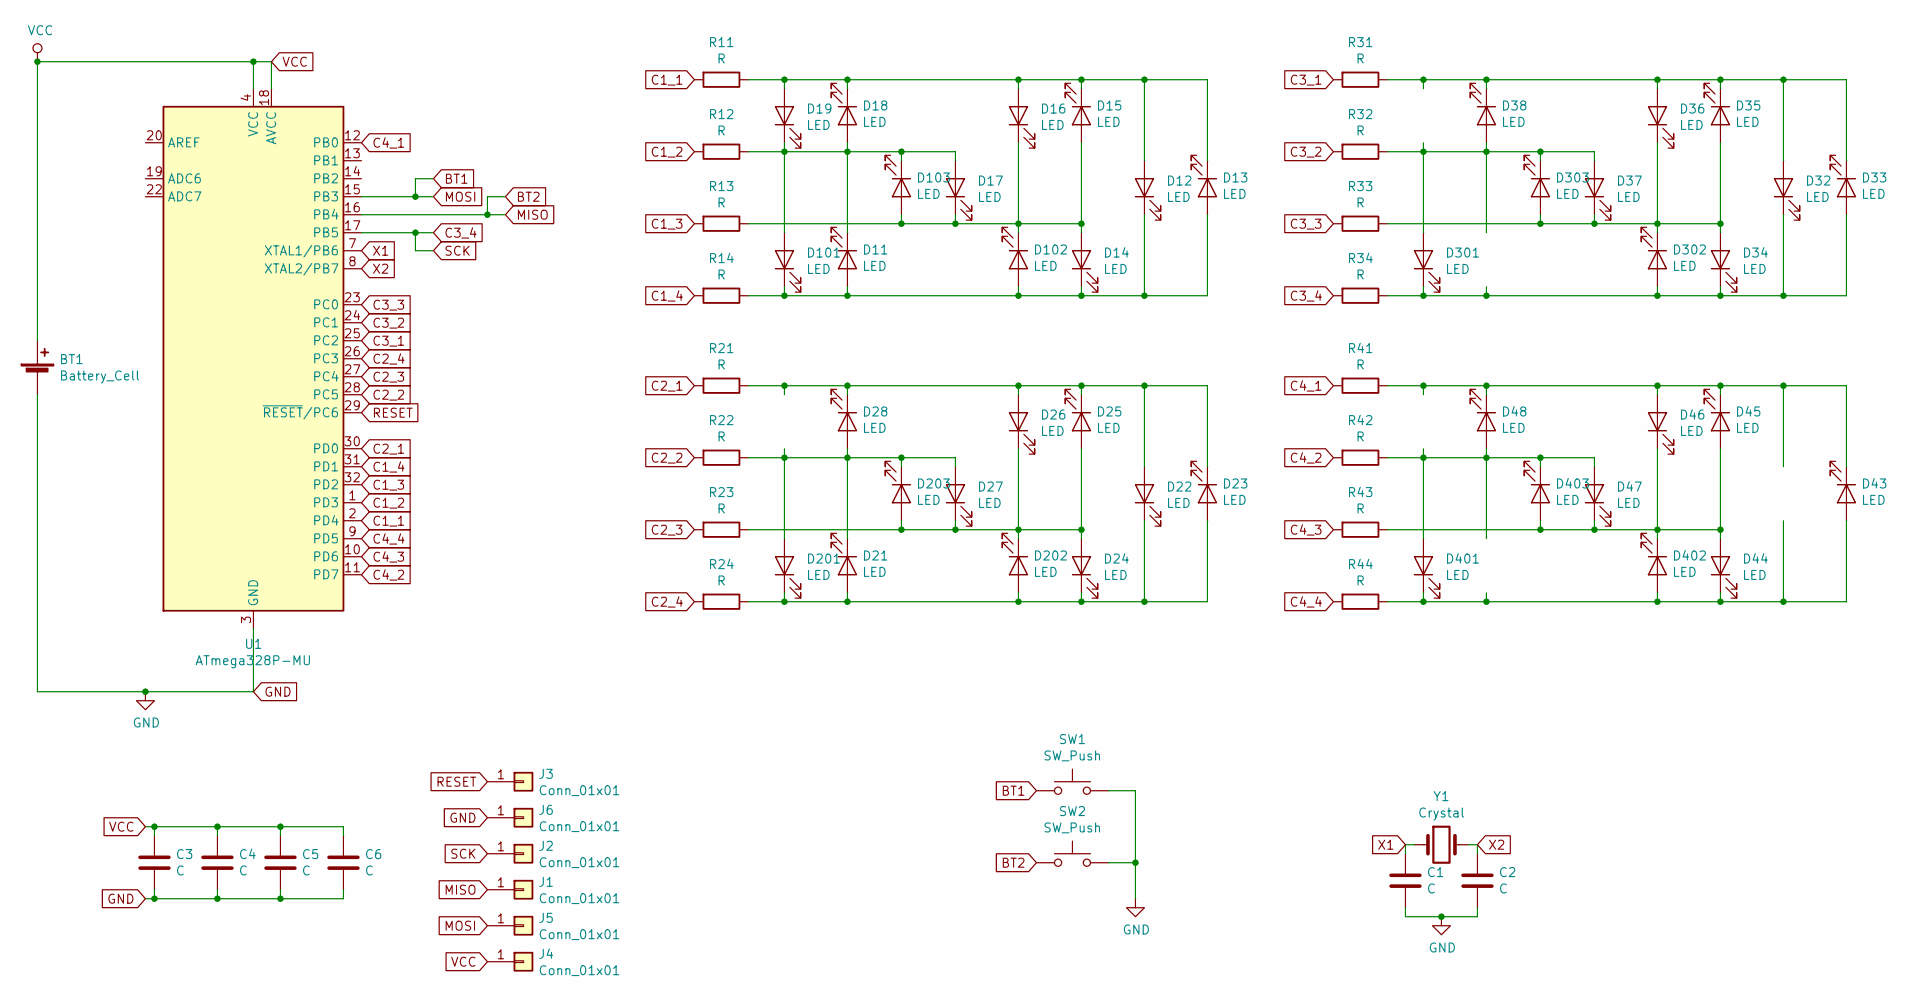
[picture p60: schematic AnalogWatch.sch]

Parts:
BT1: Battery_Cell; BatteryHolderCR2032
C1, C2, C3, C4, C5, C6: C; C_0603_1608Metric_Pad1.05x0.95mm_HandSolder
D11, D12, D13, D14, D15, D16, D17, D18, D19, D21, D22, D23, D24, D25, D26, D27, D28, D32, D33, D34, D35, D36, D37, D38, D43, D44, D45, D46, D47, D48, D101, D102, D103, D201, D202, D203, D301, D302, D303, D401, D402, D403: LED; LED_0603_1608Metric
J1, J2, J3, J4, J5, J6: Conn_01x01; TestPoint
R11, R12, R13, R14, R21, R22, R23, R24, R31, R32, R33, R34, R41, R42, R43, R44: R; R_0603_1608Metric_Pad1.05x0.95mm_HandSolder
SW1, SW2: SW_Push; Panasonic_EVQPUJ_EVQPUA
U1: ATmega328P-MU; QFN-32-1EP_5x5mm_P0.5mm_EP3.1x3.1mm
Y1: Crystal; Crystal_SMD_0603-2Pin_6.0x3.5mm

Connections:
BT1: J5.1, SW1.1, U1.15 (PB3)
BT2: J1.1, SW2.1, U1.16 (PB4)
C1_1: R11.2, U1.2 (PD4)
C1_2: R12.2, U1.1 (PD3)
C1_3: R13.2, U1.32 (PD2)
C1_4: R14.2, U1.31 (PD1)
C2_1: R21.2, U1.30 (PD0)
C2_2: R22.2, U1.28 (PC5)
C2_3: R23.2, U1.27 (PC4)
C2_4: R24.2, U1.26 (PC3)
C3_1: R31.2, U1.25 (PC2)
C3_2: R32.2, U1.24 (PC1)
C3_3: R33.2, U1.23 (PC0)
C3_4: J2.1, R34.2, U1.17 (PB5)
C4_1: R41.2, U1.12 (PB0)
C4_2: R42.2, U1.11 (PD7)
C4_3: R43.2, U1.10 (PD6)
C4_4: R44.2, U1.9 (PD5)
GND: BT1.2 (-), C1.2, C2.2, C3.2, C4.2, C5.2, C6.2, J6.1, SW1.2, SW2.2, U1.3 (GND), U1.5 (GND), U1.21 (GND), U1.33 (GND)
unnamed: D12.2 (A), D13.1 (K), D15.1 (K), D16.2 (A), D18.1 (K), D19.2 (A), R11.1
unnamed: D22.2 (A), D23.1 (K), D25.1 (K), D26.2 (A), D28.1 (K), R21.1
unnamed: D32.2 (A), D33.1 (K), D35.1 (K), D36.2 (A), D38.1 (K), R31.1
unnamed: D43.1 (K), D45.1 (K), D46.2 (A), D48.1 (K), R41.1
unnamed: D11.2 (A), D12.1 (K), D13.2 (A), D14.1 (K), D101.1 (K), D102.2 (A), R14.1
unnamed: D11.1 (K), D17.2 (A), D18.2 (A), D19.1 (K), D101.2 (A), D103.1 (K), R12.1
unnamed: D14.2 (A), D15.2 (A), D16.1 (K), D17.1 (K), D102.1 (K), D103.2 (A), R13.1
unnamed: D21.2 (A), D22.1 (K), D23.2 (A), D24.1 (K), D201.1 (K), D202.2 (A), R24.1
unnamed: D21.1 (K), D27.2 (A), D28.2 (A), D201.2 (A), D203.1 (K), R22.1
unnamed: D24.2 (A), D25.2 (A), D26.1 (K), D27.1 (K), D202.1 (K), D203.2 (A), R23.1
unnamed: D32.1 (K), D33.2 (A), D34.1 (K), D301.1 (K), D302.2 (A), R34.1
unnamed: D37.2 (A), D38.2 (A), D301.2 (A), D303.1 (K), R32.1
unnamed: D34.2 (A), D35.2 (A), D36.1 (K), D37.1 (K), D302.1 (K), D303.2 (A), R33.1
unnamed: D43.2 (A), D44.1 (K), D401.1 (K), D402.2 (A), R44.1
unnamed: D47.2 (A), D48.2 (A), D401.2 (A), D403.1 (K), R42.1
unnamed: D44.2 (A), D45.2 (A), D46.1 (K), D47.1 (K), D402.1 (K), D403.2 (A), R43.1
RESET: J3.1, U1.29 (~RESET~/PC6)
VCC: BT1.1 (+), C3.1, C4.1, C5.1, C6.1, J4.1, U1.4 (VCC), U1.6 (VCC), U1.18 (AVCC)
X1: C1.1, U1.7 (XTAL1/PB6), Y1.1
X2: C2.1, U1.8 (XTAL2/PB7), Y1.2

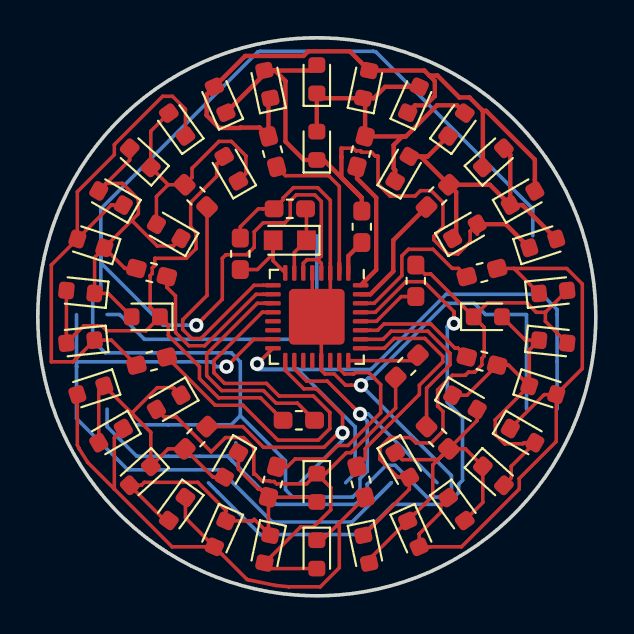
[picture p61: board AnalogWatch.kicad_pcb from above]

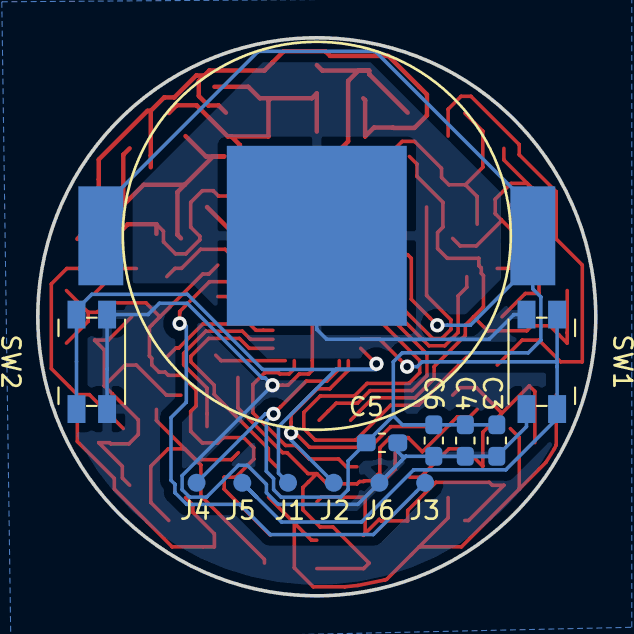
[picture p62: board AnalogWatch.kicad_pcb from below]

Board: 2 copper layers, 31.0 x 31.0 mm, 75 parts (13 on the bottom side), 39 nets.

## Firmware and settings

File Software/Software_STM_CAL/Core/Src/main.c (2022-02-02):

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
/* Includes ------------------------------------------------------------------*/
#include "main.h"

#define Undefined 0xFFFFUL
#define Binary_STM_V1 0x0100UL
#define Analog_STM_V1 0x0200UL
extern const uint32_t WatchVariant;// = Binary_STM_V1;
RTC_HandleTypeDef hrtc;

SPI_HandleTypeDef hspi1;

TIM_HandleTypeDef htim2;

void SystemClock_Config(void);
static void MX_GPIO_Init(void);
static void MX_TIM2_Init(void);
static void MX_RTC_Init(void);
static void MX_SPI1_Init(void);
/* USER CODE BEGIN 0 */
enum {
	Init, TestLEDs, WaitForTimer, Finished, Error
} State = Init;
uint8_t Errortype = 0;
uint8_t ErrorVar = 0;
const uint8_t LED_Brightness = 240;

//Maximum of 130000

int16_t SecondsElapsed = -1;
uint32_t startMeasure = 0;
uint32_t endMeasure = 0;
int64_t diffperppm = 0;


const uint32_t Timerrun_offset = 0x8000 * 8; //Prediv 8

void HAL_TIM_IC_CaptureCallback(TIM_HandleTypeDef *htim) {
	/* Prevent unused argument(s) compilation warning */

	if(SecondsElapsed == -1)
	{
		startMeasure = HAL_TIM_ReadCapturedValue(htim, TIM_CHANNEL_1);
		SecondsElapsed=1;
	}
	else if(SecondsElapsed == secondsToMeasure)
	{
		endMeasure = HAL_TIM_ReadCapturedValue(htim, TIM_CHANNEL_1);
		SecondsElapsed++;
	}
	else if(SecondsElapsed > secondsToMeasure)
	{

	}
	else
	{
		SecondsElapsed++;
	}

}

/* USER CODE END 0 */
/**
  * @brief  The application entry point.
  * @retval int
  */
int main(void)
{
  /* MCU Configuration--------------------------------------------------------*/

  /* Reset of all peripherals, Initializes the Flash interface and the Systick. */
  HAL_Init();
  /* USER CODE BEGIN Init */
  if(0)//just to get rid of warnings
  {
	  MX_GPIO_Init();
	  MX_SPI1_Init();
  }
  uint64_t WatchVersCode = *((uint64_t*) WatchVersCodeAddress);
  if((WatchVersCode&0xFFFF) == Undefined)
  {
	  writeFlash(FLASH_BASE + FLASH_SIZE - FLASH_PAGE_SIZE + 0x10, WatchVariant);
  }

  /* USER CODE END Init */

  /* Configure the system clock */
  SystemClock_Config();

  /* Initialize all configured peripherals */
  MX_TIM2_Init();
  MX_RTC_Init();
  /* USER CODE BEGIN 2 */
	DWT_Delay_Init();
	init_IOs();
  /* USER CODE END 2 */

  /* Infinite loop */
  /* USER CODE BEGIN WHILE */
	HAL_TIM_Base_MspInit(&htim2);
	if (HAL_TIM_IC_Start_IT(&htim2, TIM_CHANNEL_1) != HAL_OK) {
		Error_Handler();
		State = Error;
	}
	State = TestLEDs;
	while (1) {
		uint16_t Buffer[4] = { 0 };
		switch (State) {
		case Error:
			init_IOs();
			showError();
			break;
		case Finished:
			showFinish();
			break;
		case Init:
		case TestLEDs:
			testLEDs();
			if (HAL_GetTick() > 10000)
				State = WaitForTimer;
			break;
		case WaitForTimer:
			if(endMeasure!=0)
			{
				const uint32_t measuredClks = endMeasure -startMeasure;
				const uint32_t calculatedClks = 0x8000*secondsToMeasure;

				const int64_t difference = ((int64_t)calculatedClks-measuredClks);
				int64_t diffperppm1 = (difference*1000000);
				if(diffperppm1<0)//round the Value
					diffperppm1 -= (measuredClks/2);
				else
					diffperppm1 += (measuredClks/2);
				diffperppm = (int64_t)diffperppm1/(int64_t)measuredClks;
				if(diffperppm < 512 && diffperppm > -511)
								{
									uint16_t CALM = 0;
									uint16_t CALP = RTC_SMOOTHCALIB_PLUSPULSES_RESET;
									if (diffperppm > 0) {
										CALP = RTC_SMOOTHCALIB_PLUSPULSES_SET;
										CALM = 512 - diffperppm;
									} else {
										CALM = -diffperppm;
									}
									uint32_t EEPVAL = CALP | CALM;
									writeFlash(FLASH_BASE + FLASH_SIZE - FLASH_PAGE_SIZE, EEPVAL); //Write CalibrationValue to beginning of last Page
									HAL_RTCEx_SetSmoothCalib(&hrtc, RTC_SMOOTHCALIB_PERIOD_32SEC, CALP, CALM);//Correct RTC Immediately, to make sure the values are used even without POR
									//Note CALP, CALM, DEVID and REVID for the STM32L4_HAL.cpp File
									//__asm__("BKPT");
									State=Finished;
								}
								else
								{
									State = Error;
								}

			}
		else {
				uint16_t TimeToGo = secondsToMeasure-SecondsElapsed;
				showRemainingTime(TimeToGo);
			}
			break;

		}
    /* USER CODE END WHILE */

    /* USER CODE BEGIN 3 */
	}
  /* USER CODE END 3 */
}

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


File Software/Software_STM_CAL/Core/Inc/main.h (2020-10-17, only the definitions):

#define LSH01_Pin GPIO_PIN_3
#define LSH01_GPIO_Port GPIOA
#define LSH10_Pin GPIO_PIN_4
#define LSH10_GPIO_Port GPIOA
#define HS1_Pin GPIO_PIN_5
#define HS1_GPIO_Port GPIOA
#define HS2_Pin GPIO_PIN_6
#define HS2_GPIO_Port GPIOA
#define HS8_Pin GPIO_PIN_9
#define HS8_GPIO_Port GPIOA
#define HS4_Pin GPIO_PIN_10
#define HS4_GPIO_Port GPIOA
#define LSM01_Pin GPIO_PIN_11
#define LSM01_GPIO_Port GPIOA
#define LSM10_Pin GPIO_PIN_12
#define LSM10_GPIO_Port GPIOA
#define BMA_CS_Pin GPIO_PIN_6
#define BMA_CS_GPIO_Port GPIOB
#define BMA_CS_Pin GPIO_PIN_6
#define BMA_CS_GPIO_Port GPIOB

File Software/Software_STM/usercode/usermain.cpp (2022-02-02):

/*
 * usermain.cpp
 *
 *  Created on: Jul 24, 2020
 *      Author: sulkith
 */
#include "usermain.hpp"
#include "ClockM.hpp"
#include "DisplayManager.hpp"
#include "DisplayRequest.hpp"

#include "UserInterface.hpp"
#include "HAL.hpp"
#include "SleepM.hpp"

#include "STM32L4_HAL.hpp"
#include "GForceUI.hpp"
#include "settings.hpp"

extern RTC_HandleTypeDef hrtc;

#ifdef COMPILE_BINARY_V1
#include "STM32L4_BCDDisplayManager.hpp"
#endif
#ifdef COMPILE_ANALOG_V1
#include "STM32L4_AnalogDisplayManager.hpp"
#endif


DisplayManager *dman;
STM32L4_HAL stm_hal;
#ifdef COMPILE_BINARY_V1
STM32L4_BCDDisplayManager BCDdm;
#endif
#ifdef COMPILE_ANALOG_V1
STM32L4_AnalogDisplayManager Adm;
#endif
GForceUI gfui;

void RTC_Event_Callback()
{
	stm_hal.updateSteps();
	stm_hal.pushNewSteps(stm_hal.getSteps());
	stm_hal.resetSteps();
}
uint32_t DWT_Delay_Init(void)
{
    /* Disable TRC */
    CoreDebug->DEMCR &= ~CoreDebug_DEMCR_TRCENA_Msk; // ~0x01000000;
    /* Enable TRC */
    CoreDebug->DEMCR |=  CoreDebug_DEMCR_TRCENA_Msk; // 0x01000000;
    /* Disable clock cycle counter */
    DWT->CTRL &= ~DWT_CTRL_CYCCNTENA_Msk; //~0x00000001;
    /* Enable  clock cycle counter */
    DWT->CTRL |=  DWT_CTRL_CYCCNTENA_Msk; //0x00000001;
    /* Reset the clock cycle counter value */
    DWT->CYCCNT = 0;
    /* 3 NO OPERATION instructions */
    __ASM volatile ("NOP");
    __ASM volatile ("NOP");
    __ASM volatile ("NOP");
    volatile uint8_t a;
    a++;
    a++;
    a++;
    /* Check if clock cycle counter has started */
    if(DWT->CYCCNT)
    {
       return 0; /*clock cycle counter started*/
    }
    else
    {
      return 1; /*clock cycle counter not started*/
    }
}
void SystemClock_Config_without_LSE(void)
{
  RCC_OscInitTypeDef RCC_OscInitStruct = {0};
  RCC_ClkInitTypeDef RCC_ClkInitStruct = {0};
  RCC_PeriphCLKInitTypeDef PeriphClkInit = {0};

  /** Initializes the RCC Oscillators according to the specified parameters
  * in the RCC_OscInitTypeDef structure.
  */
  RCC_OscInitStruct.OscillatorType = RCC_OSCILLATORTYPE_MSI;
  RCC_OscInitStruct.MSIState = RCC_MSI_ON;
  RCC_OscInitStruct.MSICalibrationValue = 0;
  RCC_OscInitStruct.MSIClockRange = RCC_MSIRANGE_5;
  RCC_OscInitStruct.PLL.PLLState = RCC_PLL_NONE;
  if (HAL_RCC_OscConfig(&RCC_OscInitStruct) != HAL_OK)
  {
    Error_Handler();
  }
  /** Initializes the CPU, AHB and APB buses clocks
  */
  RCC_ClkInitStruct.ClockType = RCC_CLOCKTYPE_HCLK|RCC_CLOCKTYPE_SYSCLK
                              |RCC_CLOCKTYPE_PCLK1|RCC_CLOCKTYPE_PCLK2;
  RCC_ClkInitStruct.SYSCLKSource = RCC_SYSCLKSOURCE_MSI;
  RCC_ClkInitStruct.AHBCLKDivider = RCC_SYSCLK_DIV1;
  RCC_ClkInitStruct.APB1CLKDivider = RCC_HCLK_DIV1;
  RCC_ClkInitStruct.APB2CLKDivider = RCC_HCLK_DIV1;

  if (HAL_RCC_ClockConfig(&RCC_ClkInitStruct, FLASH_LATENCY_0) != HAL_OK)
  {
    Error_Handler();
  }
  PeriphClkInit.PeriphClockSelection = RCC_PERIPHCLK_ADC;
#ifdef STM32L432xx
  PeriphClkInit.AdcClockSelection = RCC_ADCCLKSOURCE_SYSCLK;
#endif
  if (HAL_RCCEx_PeriphCLKConfig(&PeriphClkInit) != HAL_OK)
  {
    Error_Handler();
  }
  /** Configure the main internal regulator output voltage
  */
  if (HAL_PWREx_ControlVoltageScaling(PWR_REGULATOR_VOLTAGE_SCALE1) != HAL_OK)
  {
    Error_Handler();
  }
}
inline void requestScreen(DisplayManager *dm, DisplayRequestType type,
		uint16_t d0, uint16_t d1 = 0, uint16_t d2 = 0, uint16_t d3 = 0,
		uint16_t d4 = 0) {
	uint16_t data[DisplayRequest::dataLength] = { 0 };
	data[0] = d0;
	data[1] = d1;
	data[2] = d2;
	data[3] = d3;
	data[4] = d4;
	DisplayRequest dr(type, data);
	dm->requestDisplay(dr);
}
//#define PROFILING(x) x
#ifndef PROFILING
	#define PROFILING(x)
#endif
void usermain_init() {
	  SystemClock_Config_without_LSE();
	  PROFILING(uint32_t time[20];)

	  // Moved to HAL: MX_RTC_Init();
	  // Moved to HAL: MX_SPI1_Init();
	  PROFILING(time[0] = HAL_GetTick();)
	  Watch_Type_t wt = Binary_v1;
	  uint64_t WatchVersCode = *((uint64_t*) WatchVersCodeAddress);
		if((WatchVersCode&0xFFFF) == Binary_STM_V1 || (WatchVersCode&0xFFFF) == Binary_STM_V2_LIPO)
		{
		  wt = Binary_v1;
		  gfui.setSettingsPtr(&SettingsBinaryV1);
		}
		if((WatchVersCode&0xFFFF) == Analog_STM_V1)
		{
		  wt = Analog_v1;
		  gfui.setSettingsPtr(&SettingsAnalogV1);
		}
	  PROFILING(time[1] = HAL_GetTick();)
	  //hal = &stm_hal;
	  DWT_Delay_Init();

	  switch(wt)
	  {
#ifdef COMPILE_BINARY_V1
	  case Binary_v1:
		  dman = &BCDdm;
		  break;
#endif
#ifdef COMPILE_ANALOG_V1
	  case Analog_v1:
		  dman = &Adm;
#endif
	  	  break;
	  default:
		  Error_Handler();
	  }
	  PROFILING(time[2] = HAL_GetTick();)
	  stm_hal.setAxisMappingVariant(wt);
	  PROFILING(time[3] = HAL_GetTick();)
	  stm_hal.HAL_driverInit();
	  PROFILING(time[4] = HAL_GetTick();)
	  stm_hal.setDisplayManager(dman);
	  PROFILING(time[5] = HAL_GetTick();)
	  dman->init();
	  PROFILING(time[6] = HAL_GetTick();)
	  stm_hal.HAL_init();
	  PROFILING(time[7] = HAL_GetTick();)
	  dman->lockPorts();
	  PROFILING(time[8] = HAL_GetTick();)
	  stm_hal.HAL_cyclic();


	  gfui.init(dman, &stm_hal, &stm_hal);
	  PROFILING(time[9] = HAL_GetTick();)
	  SleepM::getInstance()->setHal(&stm_hal);
	  PROFILING(time[10] = HAL_GetTick();)

//	  while(1)
//	  {
//		  requestScreen(dman, Debouncing, 2, 3, 4);
//		  dman->show();
//	  }

	  if(stm_hal.HAL_getWakeupReason() < 0x10)//No Wakeup for Hourly Display
	  {
		  stm_hal.HAL_sleep();
	  }


}

void usermain_loop() {
	if(0)
	{
		uint16_t data[] = {12,48,0,0,0};
		data[0] = ClockM::getInstance().getHour();
		data[1] = ClockM::getInstance().getMinute();
		if(HAL_GPIO_ReadPin(BMA_INT_GPIO_Port, BMA_INT_Pin) == GPIO_PIN_SET)
		{
			data[0] = 21;
		}
		if(stm_hal.getTap()>0)
		{
			data[1] = 84;
		}
		DisplayRequest dr(Time, data);
		dman->requestDisplay(dr);
		dman->show();
	}
	gfui.cyclic();
	SleepM::getInstance()->cyclic();
	stm_hal.HAL_cyclic();
	dman->show();
}

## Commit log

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2018-07-29 ímproved PCB. Removed 2 Buttons. Now diameter is only 35mm
    [Watch.kicad_pcb, Watch.sch]
2018-07-30 Added Capacitors. Added gerber files
    [Watch-B.Cu.gbl, Watch-B.Mask.gbs, Watch-B.SilkS.gbo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]
2018-08-25 Added new Board with 5mmx5mm QFN Package. the 7x7 Package is not produced by Atmel, therefore the old boards are useless -.- Also added two capacitorsfor the crystal, since it is recommended.
    [Watch.kicad_pcb, Watch.sch, Watch_wrong.kicad_pcb]
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2018-08-25 added missing ground connection. Seperate rule for edges in DRC.
    [Watch-B.Cu.gbl, Watch-B.Mask.gbs, Watch-B.SilkS.gbo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]
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2018-09-02 finished 3D Model of Housing
    [Housing.scad, HousingAssembled.stl]
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2018-09-03 cleaned up old Stuff from SCAD File.
    [Housing.scad]
2018-09-03 smoothed lid. updated rendering.
    [Housing.scad]
2018-09-03 smoothed the lid further.
    [Housing.scad]
2018-09-03 set to high quality again
    [Housing.scad]
2018-12-01 Added ADC for Battery Voltage and Connected VADC to VCC
    [Watch-B.Cu.gbl, Watch-B.Mask.gbs, Watch-B.SilkS.gbo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]
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2018-12-16 created a Folder for the Housing Model Files
    [Housing.scad]
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2018-12-17 added temperature Test sw. found error in PCB aref should not be vonnected to VCC.
    [main.c]
2018-12-20 added functionality for eeprom read and correction added functions to makefile to write eeprom and to dump the whole Chip
    [main.c]
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2018-12-21 correcte eeprom read function for Month correction
    [main.c]
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2018-12-25 Added a Option for a Transparent Housing
    [Housing.scad]
2018-12-25 strengthened the Glass mounting
    [Housing.scad]
2018-12-27 Added Makefile to generate the stl files on the command line
    [generatePrintFile.scad, generateRendering.scad]
2018-12-27 Bigger top on the housing. moved the buttons a bit down to fit better to the Buttons on the real pcb
    [Housing.scad, HousingAssembled.stl]
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2018-12-28 Fixed a bad mistake in reloading corretion every Day
    [main.c]
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2018-12-31 added function for modifing the EEPROM values for the crystal correction via Buttons on the Clock
    [main.c]
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2019-01-02 merged with the normal Housing again...
    [Housing.scad, HousingAssembled.stl]
2019-01-02 added a size calculation to the print function. now the Housing Size is 9.7mm
    [Housing.scad, HousingAssembled.stl]
2019-01-02 removed the PCB Dummy from the Printfile
    [Housing.scad, HousingAssembled.stl]
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2019-01-04 corrected a mistake in the PCB Placement. made the Housing 1mm slimmer
    [Housing.scad, HousingAssembled.stl]
2019-01-04 fixed overlaying parts
    [Housing.scad, HousingAssembled.stl]
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2019-01-08 Added Temperature Correction
2019-01-10 smoothing of the upper side lid is aligned with the bottom added a Clamp for the glass
    [Housing.scad]
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2019-02-02 added Temperature display, moved temparature correction table to flash, since it took very long to write it to EEP. added option to configure temperature offset in EEP. Added protection for settings 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
    [main.c]
2019-02-12 added Schematic for Analog Watch
    [AnalogWatch.kicad_pcb, AnalogWatch.sch, CircleDistribution.ods]
2019-02-13 finally a PCB Routing. Buttons are stillt missing, but the Pins used for ISP should be usable.
    [AnalogWatch.kicad_pcb, AnalogWatch.sch]
2019-02-14 Added Buttons on the analog Variant. Added Gerber Files.
    [AnalogWatch-B.Cu.gbl, AnalogWatch-B.Mask.gbs, AnalogWatch-B.Paste.gbp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]
2019-02-14 cleanup of the Folder Structure
    [AnalogWatch-B.Cu.gbl, AnalogWatch-B.Mask.gbs, AnalogWatch-B.Paste.gbp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]
2019-03-03 Added Software for analog PCB.
    [CharlieArray.ods]
2019-03-04 fitted the soldermask clearance to the QFN Package. otherwise soldering is a mess, since the pins are connecting to each other -.-
    [AnalogWatch-B.Cu.gbl, AnalogWatch-B.Mask.gbs, AnalogWatch-B.Paste.gbp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]
2019-03-05 added Cpacitors for the voltage
    [AnalogWatch-B.Cu.gbl, AnalogWatch-B.Mask.gbs, AnalogWatch-B.Paste.gbp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]
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2019-03-05 cleaned up labels again
    [AnalogWatch-B.Cu.gbl, AnalogWatch-B.Mask.gbs, AnalogWatch-B.Paste.gbp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]
2019-03-05 added a leftover track
    [AnalogWatch-B.Cu.gbl, AnalogWatch-B.Mask.gbs, AnalogWatch-B.Paste.gbp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]
2019-04-17 fixed problems with static initialization
    [main.cpp]
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2019-06-30 added space for the Battery Clip
    [Housing.scad, HousingAssembled.stl]
2019-07-02 added file for SLA printing
    [Housing.scad, generatePrintFile_SLA.scad]
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2019-08-13 added latex generated Story of the Project
    [myconf.cfg]
2019-09-08 added a delay, for not interfering with the BMA while programming
    [main.cpp]
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2019-09-29 removed buttons and corresponding Holes
    [Housing.scad, HousingAssembled.stl]
2019-09-29 removed Button-Holes on lid
    [Housing.scad, HousingAssembled.stl]
2019-10-03 increased robustness of BMA Bootup, also better error signalizing. Testing the Second PCB drove me nuts, since the BMA wasnt initializing when plugging in the Battery to slow
    [BinaryGWatch.cpp]
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2019-10-08 improved rebustness of BMA(reini if error occurs), changed the way how the Step Counter is reset, now all steps ever should be preserved
    [BinaryGWatch.cpp, BinaryGWatch.h]
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2019-12-14 fixed a type conversion Problem
    [BinaryGWatch.cpp]
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2020-03-31 added gnd pins so it is possible to solder a battery without a battery holder
    [Watch.kicad_pcb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]
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2020-05-03 corrected Typo Timer0 is Timer2 instead
    [BinaryGWatch.cpp]
2020-05-03 added a Hint for Error ED11
    [BinaryGWatch.cpp]
2020-07-17 Added PCB Version with STM32 Controller
    [Watch-B_Cu.gbl, Watch-B_Mask.gbs, Watch-B_SilkS.gbo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]
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2020-07-19 Improved Schematics, got the DRC to finish without errors. Added 256K Controller Version
    [ControllerOptions.ods, Watch.sch]
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2020-07-25 first import of the BCD Software for the STM32L432. RTC, BMA, Display and Sleep are working. UBatt Measure is not implemented yet...
    [WristWatch Debug.cfg]
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2020-07-25 Added Resistor for Boot0 but only on schematic, PCB is to be done
    [Watch.sch]
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2020-07-30 initial import of RTC Calibration Software
    [WristWatch_Calibration Debug.cfg]
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2020-07-30 Routed BOOT0 Pin via Resistor to GND, and Removed BMA_INT2
    [Watch-B_Cu.gbl, Watch-B_Mask.gbs, Watch-B_SilkS.gbo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]
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2020-08-03 added Analog Version with BMA and STM
    [AnalogWatch-B.Cu.gbl, AnalogWatch-B.Mask.gbs, AnalogWatch-B.Paste.gbp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]
2020-08-07 improved some traces, so they are straigt
    [AnalogWatch-B.Cu.gbl, AnalogWatch-B.Mask.gbs, AnalogWatch-B.Paste.gbp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]
2020-08-07 added backup of steps History
    [WristWatch Debug.cfg]
2020-08-07 selected STLINK to use
    [WristWatch_Calibration Debug.cfg]
2020-08-07 added Calibrations --> Voltage does not have an effect, but to high capacitance slows the clock down
    [Calibrations.ods]
2020-08-10 added Testpoints for programming and calibration
    [Watch-B_Cu.gbl, Watch-B_Mask.gbs, Watch-B_SilkS.gbo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]
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2020-08-10 Moved the Testpoints from under the Battery to an accessible place
    [Watch-B_Cu.gbl, Watch-B_Mask.gbs, Watch-B_SilkS.gbo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]
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2020-08-14 corrected calibration function
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2020-08-23 fixed ubatt Calculation. VRef is 1,2V not 1,1V, added Brightness Control based on Time of Day, Added Steps History Size
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2020-09-27 fixed the power Problem, all pins are now in a defined State. The Watch draws 54,6µA in shutdown now thes is nearly completely caused by the BMA Sensor
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2020-10-04 fixed the Analog Display Manager, so it wont kill the SPI with locking the Pins
    [usermain.cpp]
2020-10-09 added PM LED for setting the Hour, and fixed the turn on Animation for evenings
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2020-10-16 fixed the initialization Problem for the analog watch. Now the Stepcounter Reset should work
    [usermain.cpp]
2020-10-17 fixed a Missing entry in the minutes Array
    [CharlieArray_STM.ods]
2020-10-17 Added different Build Targets for Analog and BCD Calibration
    [WristWatch_Calibration.cfg]
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2021-04-30 added solderpads for chager and fixed wiring from charger to Buck Converter
    [Watch-B_Cu.gbl, Watch-B_Mask.gbs, Watch-B_SilkS.gbo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]
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2021-11-29 added wireless charging to the STM32 Binary Watch
    [Watch.kicad_pcb, Watch.sch]
2021-11-30 cleanup and removed C3 to keep the front side cleaner
    [Watch.kicad_pcb, Watch.sch]
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2022-01-02 added the PDFs of the Schematics and some notes
    [FrequencyCalculation.ods]
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2022-01-08 added a missing initialization for the STM32L422s RTC
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2022-02-02 added a missing comment, so the new generation of the Config code will not delete the usercode
    [main.c]
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2022-02-06 made the housing bigger to fit the LiPo Version of the Watch
    [Housing.scad, HousingAssembled.stl]
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2022-05-29 fixed an initialization Problem for the STM32L422, added a clr for the reinitialization Comand, added a Branch to deinitialize the BMA to get the calibration of the RTC working without cutting power

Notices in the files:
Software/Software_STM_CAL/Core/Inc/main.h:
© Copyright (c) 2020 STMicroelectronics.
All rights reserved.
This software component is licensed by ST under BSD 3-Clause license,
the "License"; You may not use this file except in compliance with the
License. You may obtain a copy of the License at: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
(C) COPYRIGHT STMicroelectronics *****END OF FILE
